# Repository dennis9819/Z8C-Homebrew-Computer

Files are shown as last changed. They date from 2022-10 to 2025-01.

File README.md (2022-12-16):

# Z8C-Homebrew-Computer

# Using the build tools
The Z8C uses the zmac macro assembler (http://48k.ca/zmac.html)

To easily develop for my Z80 homebrew system, I designed a simple
assempler development environment. This packs the following tasks into one script:
* zmac assembly
* object file creation (for xmodem upload)
* monitor file creation (creates monitor commands for ascii upload)
* symbol table include file generation
* eeprom programming for the minipro

## Prequisites
* zmac - self-compiled version included in ./Utility.
* minipro (https://gitlab.com/DavidGriffith/minipro)
* binutils (apt-get install binutils-multiarch, 
    pacman -S aarch64-linux-gnu-binutils )

## Building a project
`./build.sh <dir> <asm filename>`
* `dir`: Path to the location of the asm file
* `asm filename`: name of the assembly file without suffix

```
    # e.g.:
    cd ./Utility
    ./build.sh ../OperatingSystem/monitor_v2  
    ./build.sh ../OperatingSystem/software  
```
## Building a project with a properties file

`./build.sh <dir>`
* `dir`: Path to the location of the asm file

The directory must contain a file called `properties.env`
This file can contain project-specific options.

Example:
```
export OPT_GEN_SYMBOLTABLE=1
export OPT_GEN_MONFILE=0
export OPT_GEN_OBJFILE=1
export OPT_WRITEROM=1
export FILENAME=main
```

### Options
* `OPT_GEN_SYMBOLTABLE` if set to 1: Generates the symbols.s file
* `OPT_GEN_MONFILE` if set to 1: Generates the monitor file
* `OPT_GEN_OBJFILE` if set to 1: Generates the object file
* `OPT_WRITEROM` if set to 1: Starts eeprom programmer
* `FILENAME` same as the `<asm filename>` paramter of the build script
* `ROOT_DIR` overrides the project root path. required if git is not used
* `EEPROM_PART` sets EEPROM part for minipro. Default: `AT28C256`

# System design
The Z80 Hombrew computer is modular computer system, designed arround a custom backplane.

## Available modules
### Z8C CPU/COM Board
* Z80 ZPU @ 4MHz (6MHz planned)
* 64 KiB SRAM
* 32 KiB EEPROM (R/W switchable)
* Z80 CTC with external 1.8432MHz Clock switchable per channel
* Z80 SIO (Up to 115200 BAUD possible @ X16 SIO prescaler)
* 1 FTDI Connector
* 1 RS232 DSUB-9 Port
* 8 front-facing DIP switches (currently used for baud-rate setup)
* Power-On-Reset Circuit

```
Memory Layout
       Default ($00 = 0x00)  Mode 1 ($00 = 0x02)  Mode 2 ($00 = 0x01)             
$0000 +--------------------+--------------------+--------------------+
      | EEPROM Lower 16KiB | EEPROM Upper 16KiB | SRAM               |
$4000 +--------------------+--------------------+                    |
      | SRAM               | SRAM               |                    | 
      |                    |                    |                    |
      |                    |                    |                    |
$FFFF +--------------------+--------------------+--------------------+

Note: In default mode and mode 1, the MEMAQ pin (pin a5 on backplane) 
      can be used to inject an external memory device in the $0000-$3FFF 
      window.

IO Addresses:
$00 Memory register
$01 DIP Switches
$04 CTC (First address)
$08 SIO (First address)
```

### Z8C MIO Board
* Z80 PIO (Used for GPIO and non Z80 compliant interrupt handling)
* VT82C42 PS/2 controller
* AM5911A (only usable with CPU-Clock under 3 MHz)
* PFC8584 I2C Controller
* DS1307 RTC
* 8-Bit GPIO Port

//TODO: Add more Info

### Z8C Disk Interface Board
* Intel 82C55 based IDE Interface
* FDC9266 Floppy Disk Controller

//TODO: Add more Info

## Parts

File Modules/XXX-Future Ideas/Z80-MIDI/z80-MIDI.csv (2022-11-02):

Source: | C:\Users\dg\Documents\Z80\z80-MIDI\z80-MIDI.kicad_sch
Date: | 14/10/2022 00:28:46
Tool: | Eeschema (6.0.4)
Generator: | C:\Program Files\KiCad\6.0\bin\scripting\plugins/bom_csv_grouped_by_value.py
Component Count: | 26
Individual Components:
Item | Qty | Reference(s) | Value | LibPart | Footprint | Datasheet | Allied Price/Stock | Allied_Number | Description | Height | Manufacturer_Name | Manufacturer_Part_Number | Mouser Part Number | Mouser Price/Stock | RS Part Number | RS Price/Stock
 |  | IC1 | CTC-DIP-28 | Zilog_Z80_Peripherals:CTC-DIP-28 | Package_DIP:DIP-28_W15.24mm_LongPads |  |  |  | Z8430 Zilog CTC | 5.21 | Zilog | Z84C3010PEG | 692-Z84C3010PEG | https://www.mouser.com/Search/Refine.aspx?Keyword=692-Z84C3010PEG
 |  | IC2 | SIO1-DIP-40 | Zilog_Z80_Peripherals:SIO1-DIP-40 | Package_DIP:DIP-40_W15.24mm_LongPads |  | https://www.alliedelec.com/zilog-z84c4206peg/R1000052/ | R1000052 | Z80 CMOS SIO/1 Z84C41 Zilog | 4.06 | Zilog | Z84C4206PEG | 692-Z84C4206PEG | https://www.mouser.com/Search/Refine.aspx?Keyword=692-Z84C4206PEG | 6600766 | https://uk.rs-online.com/web/p/products/6600766
 |  | J1 | Conn_02x32_Row_Letter_First | Connector_Generic:Conn_02x32_Row_Letter_First | Connector_DIN:DIN41612_Q_2x32_Male_Horizontal_THT | ~
 |  | J2 | Conn_02x05_Odd_Even | Connector_Generic:Conn_02x05_Odd_Even | Connector_PinHeader_2.54mm:PinHeader_2x05_P2.54mm_Vertical | ~
 |  | J3 | DIN-5 | Connector:DIN-5 | w_conn_av:din-5 | http://www.mouser.com/ds/2/18/40_c091_abd_e-75918.pdf
 |  | J4 | DIN-5 | Connector:DIN-5 | w_conn_av:din-5 | http://www.mouser.com/ds/2/18/40_c091_abd_e-75918.pdf
 |  | J5 | DIN-5 | Connector:DIN-5 | w_conn_av:din-5 | http://www.mouser.com/ds/2/18/40_c091_abd_e-75918.pdf
 |  | LED1 | MENOTR_A500_Dual_3mm | CustomSymbols:MENOTR_A500_Dual_3mm | w_conn_av:MENTOR A500 Dual 3mm
 |  | R1 | 10k | Device:R | Resistor_THT:R_Axial_DIN0204_L3.6mm_D1.6mm_P7.62mm_Horizontal | ~
 |  | R2 | 10k | Device:R | Resistor_THT:R_Axial_DIN0204_L3.6mm_D1.6mm_P7.62mm_Horizontal | ~
 |  | R3 | 10k | Device:R | Resistor_THT:R_Axial_DIN0204_L3.6mm_D1.6mm_P7.62mm_Horizontal | ~
 |  | R4 | 10k | Device:R | Resistor_THT:R_Axial_DIN0204_L3.6mm_D1.6mm_P7.62mm_Horizontal | ~
 |  | R5 | 10k | Device:R | Resistor_THT:R_Axial_DIN0204_L3.6mm_D1.6mm_P7.62mm_Horizontal | ~
 |  | R6 | 10k | Device:R | Resistor_THT:R_Axial_DIN0204_L3.6mm_D1.6mm_P7.62mm_Horizontal | ~
 |  | R7 | 10k | Device:R | Resistor_THT:R_Axial_DIN0204_L3.6mm_D1.6mm_P7.62mm_Horizontal | ~
 |  | RN1 | R_Network08 | Device:R_Network08 | Resistor_THT:R_Array_SIP9 | http://www.vishay.com/docs/31509/csc.pdf
 |  | U1 | 74LS688 | 74xx:74LS688 | Package_DIP:DIP-20_W7.62mm_LongPads | http://www.ti.com/lit/gpn/sn74LS688
 |  | U2 | 74HC245 | 74xx:74HC245 | Package_DIP:DIP-20_W7.62mm_LongPads | http://www.ti.com/lit/gpn/sn74HC245
 |  | U3 | 74HC245 | 74xx:74HC245 | Package_DIP:DIP-20_W7.62mm_LongPads | http://www.ti.com/lit/gpn/sn74HC245
 |  | U4 | 74HC245 | 74xx:74HC245 | Package_DIP:DIP-20_W7.62mm_LongPads | http://www.ti.com/lit/gpn/sn74HC245
 |  | U5 | 74LS06 | 74xx:74LS06 | Package_DIP:DIP-14_W7.62mm_Socket_LongPads | http://www.ti.com/lit/gpn/sn74LS06
 |  | U6 | 74LS02 | 74xx:74LS02 |  | http://www.ti.com/lit/gpn/sn74ls02
 |  | U7 | 74LS06 | 74xx:74LS06 | Package_DIP:DIP-14_W7.62mm_Socket_LongPads | http://www.ti.com/lit/gpn/sn74LS06
 |  | U8 | 74LS06 | 74xx:74LS06 | Package_DIP:DIP-14_W7.62mm_Socket_LongPads | http://www.ti.com/lit/gpn/sn74LS06
 |  | U9 | 6N137 | Isolator:6N137 | Package_DIP:DIP-8_W7.62mm | https://docs.broadcom.com/docs/AV02-0940EN
 |  | X1 | ACO-xxxMHz | Oscillator:ACO-xxxMHz | Oscillator:Oscillator_DIP-14 | http://www.conwin.com/datasheets/cx/cx030.pdf
Collated Components:
Item | Qty | Reference(s) | Value | LibPart | Footprint | Datasheet | Allied Price/Stock | Allied_Number | Description | Height | Manufacturer_Name | Manufacturer_Part_Number | Mouser Part Number | Mouser Price/Stock | RS Part Number | RS Price/Stock
1 | 1 | IC1 | CTC-DIP-28 | Zilog_Z80_Peripherals:CTC-DIP-28 | Package_DIP:DIP-28_W15.24mm_LongPads |  |  |  | Z8430 Zilog CTC | 5.21 | Zilog | Z84C3010PEG | 692-Z84C3010PEG | https://www.mouser.com/Search/Refine.aspx?Keyword=692-Z84C3010PEG
2 | 1 | IC2 | SIO1-DIP-40 | Zilog_Z80_Peripherals:SIO1-DIP-40 | Package_DIP:DIP-40_W15.24mm_LongPads |  | https://www.alliedelec.com/zilog-z84c4206peg/R1000052/ | R1000052 | Z80 CMOS SIO/1 Z84C41 Zilog | 4.06 | Zilog | Z84C4206PEG | 692-Z84C4206PEG | https://www.mouser.com/Search/Refine.aspx?Keyword=692-Z84C4206PEG | 6600766 | https://uk.rs-online.com/web/p/products/6600766
3 | 1 | J1 | Conn_02x32_Row_Letter_First | Connector_Generic:Conn_02x32_Row_Letter_First | Connector_DIN:DIN41612_Q_2x32_Male_Horizontal_THT | ~
4 | 1 | J2 | Conn_02x05_Odd_Even | Connector_Generic:Conn_02x05_Odd_Even | Connector_PinHeader_2.54mm:PinHeader_2x05_P2.54mm_Vertical | ~
5 | 3 | J3, J4, J5 | DIN-5 | Connector:DIN-5 | w_conn_av:din-5 | http://www.mouser.com/ds/2/18/40_c091_abd_e-75918.pdf
6 | 1 | LED1 | MENOTR_A500_Dual_3mm | CustomSymbols:MENOTR_A500_Dual_3mm | w_conn_av:MENTOR A500 Dual 3mm
7 | 7 | R1, R2, R3, R4, R5, R6, R7 | 10k | Device:R | Resistor_THT:R_Axial_DIN0204_L3.6mm_D1.6mm_P7.62mm_Horizontal | ~
8 | 1 | RN1 | R_Network08 | Device:R_Network08 | Resistor_THT:R_Array_SIP9 | http://www.vishay.com/docs/31509/csc.pdf
9 | 1 | U1 | 74LS688 | 74xx:74LS688 | Package_DIP:DIP-20_W7.62mm_LongPads | http://www.ti.com/lit/gpn/sn74LS688
10 | 3 | U2, U3, U4 | 74HC245 | 74xx:74HC245 | Package_DIP:DIP-20_W7.62mm_LongPads | http://www.ti.com/lit/gpn/sn74HC245
11 | 3 | U5, U7, U8 | 74LS06 | 74xx:74LS06 | Package_DIP:DIP-14_W7.62mm_Socket_LongPads | http://www.ti.com/lit/gpn/sn74LS06
12 | 1 | U6 | 74LS02 | 74xx:74LS02 |  | http://www.ti.com/lit/gpn/sn74ls02
13 | 1 | U9 | 6N137 | Isolator:6N137 | Package_DIP:DIP-8_W7.62mm | https://docs.broadcom.com/docs/AV02-0940EN
14 | 1 | X1 | ACO-xxxMHz | Oscillator:ACO-xxxMHz | Oscillator:Oscillator_DIP-14 | http://www.conwin.com/datasheets/cx/cx030.pdf

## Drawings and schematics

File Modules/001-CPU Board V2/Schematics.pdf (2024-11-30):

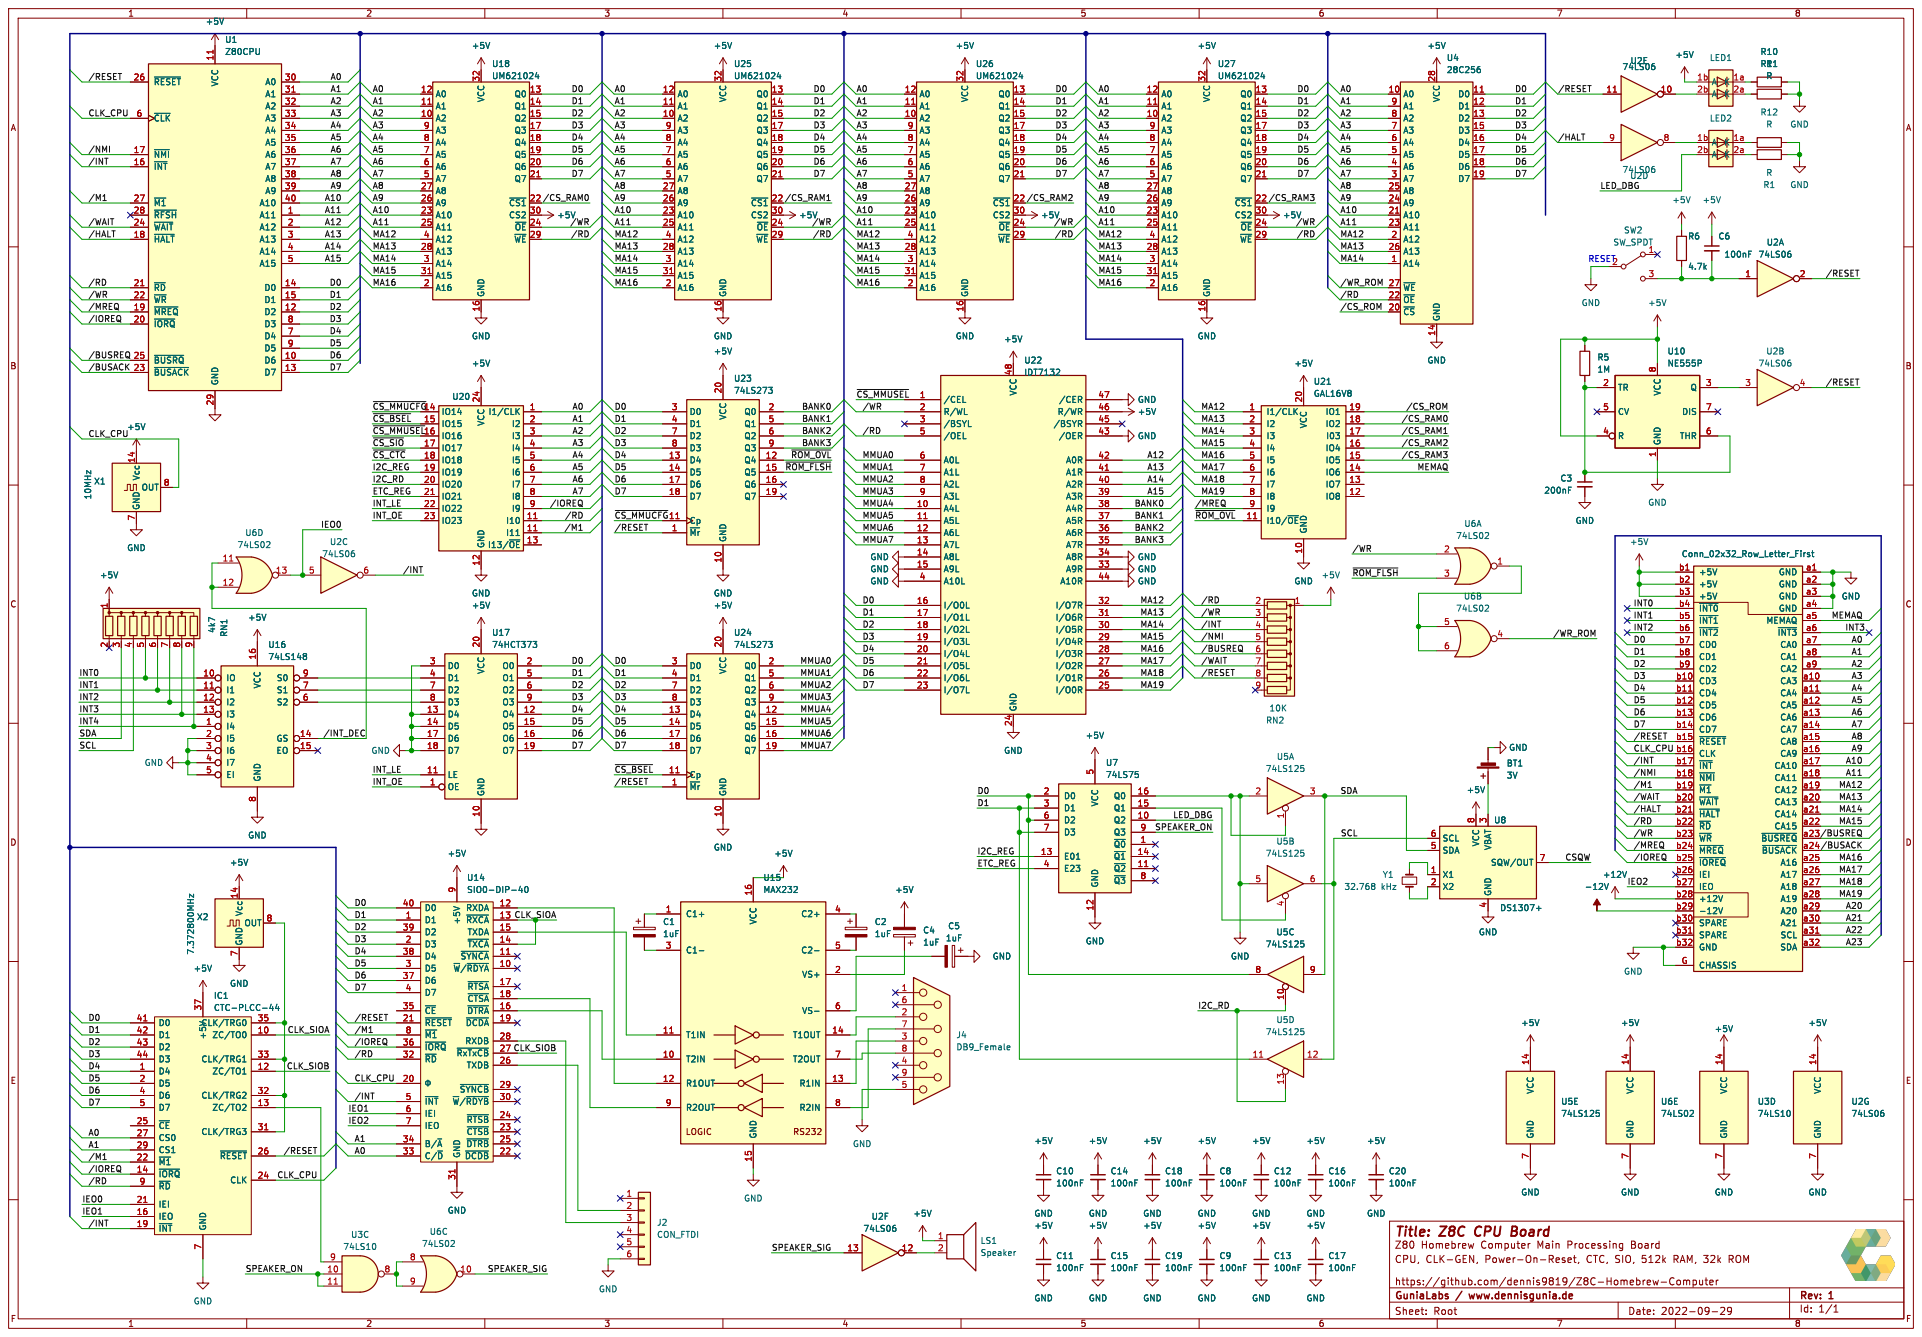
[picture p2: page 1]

GND
+5V GND GND GND GND

4 SDA 5 SCL 6 SQW/OUT 7 VCC

Id: 1/1 Title: Z8C CPU Board

https://github.com/dennis9819/Z8C-Homebrew-Computer

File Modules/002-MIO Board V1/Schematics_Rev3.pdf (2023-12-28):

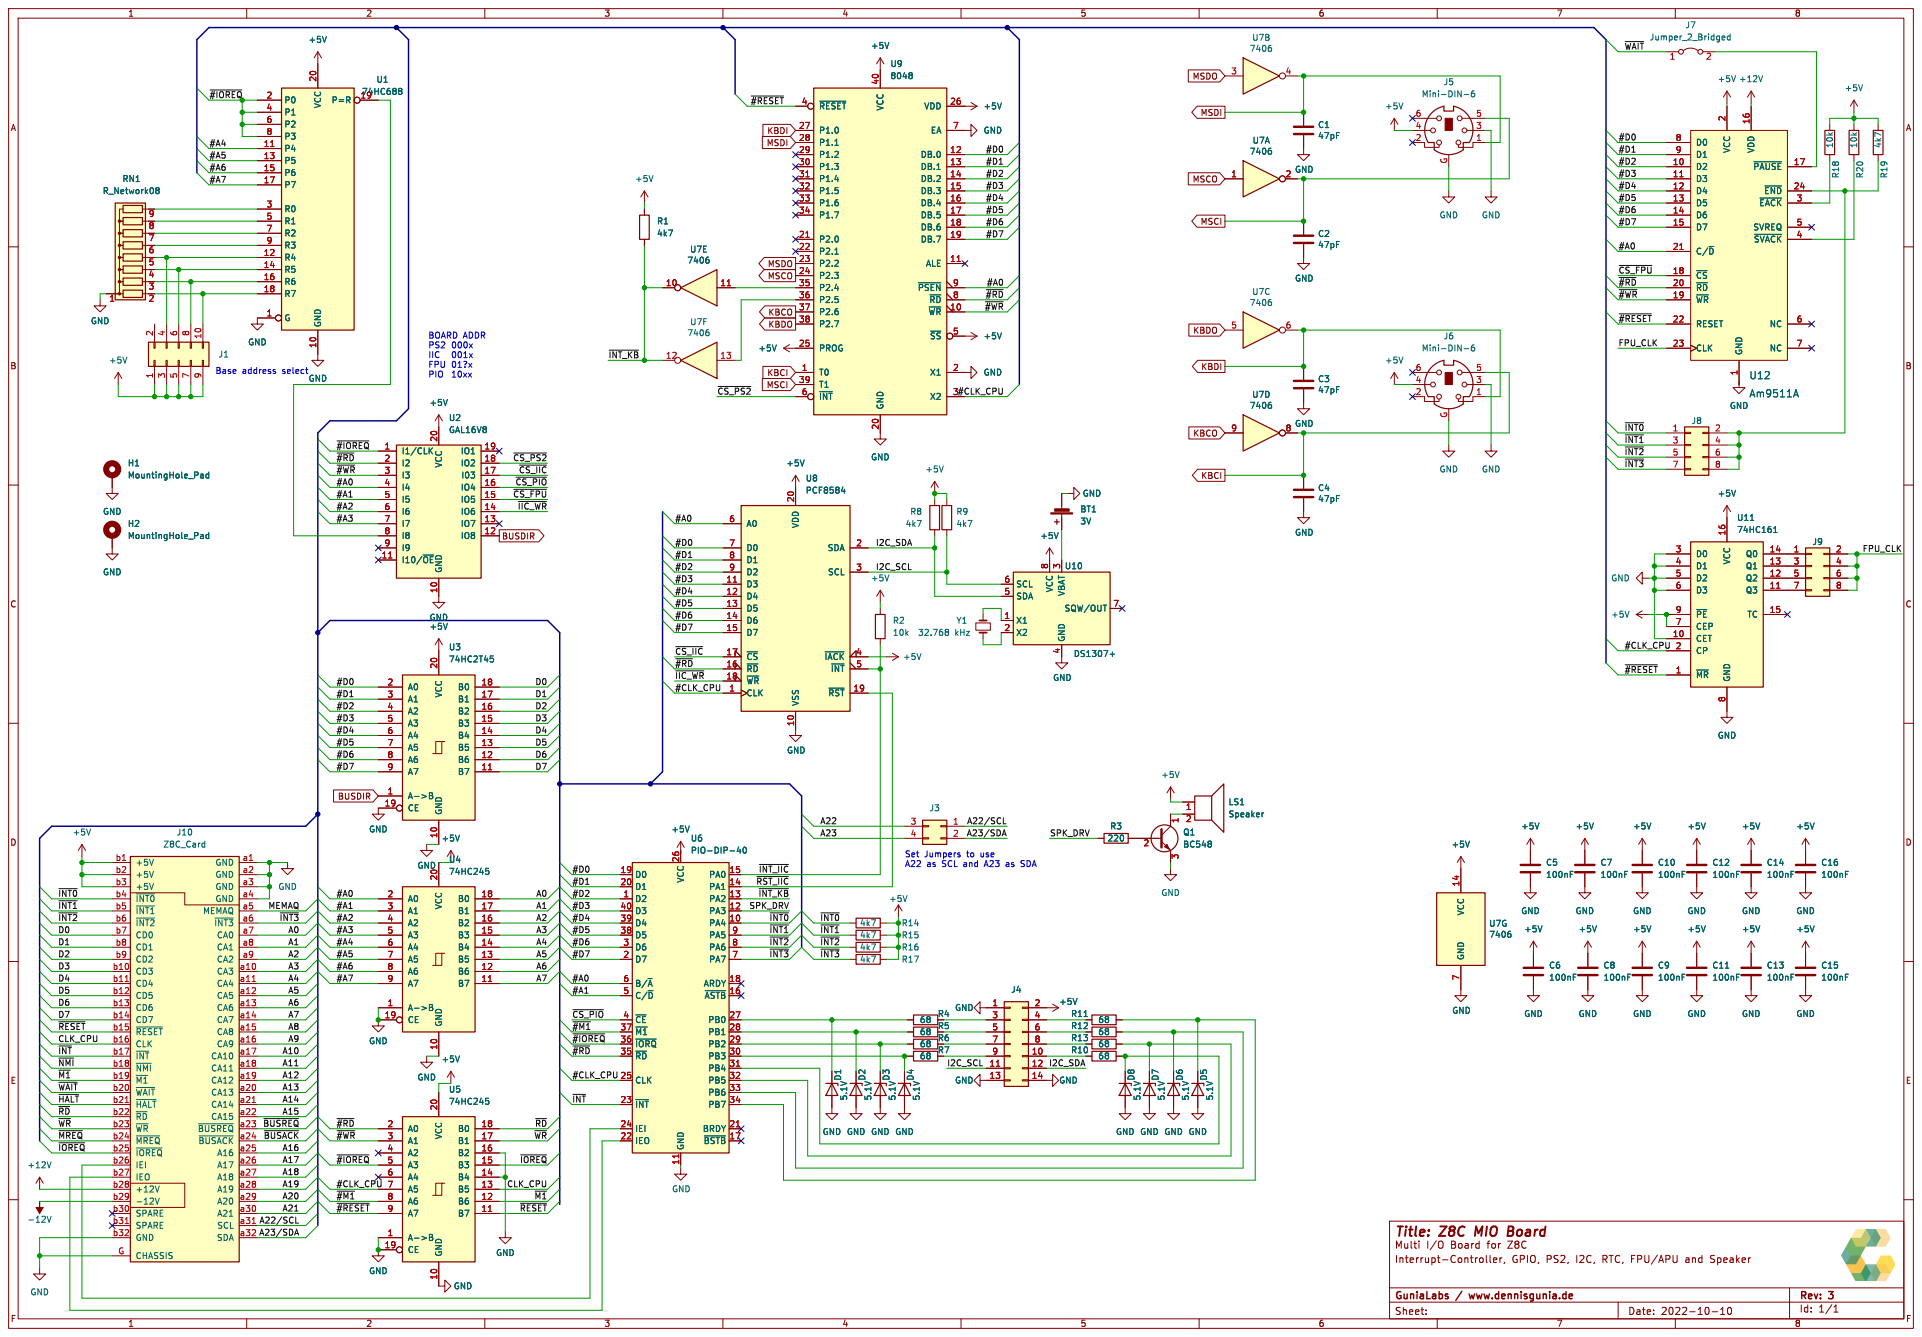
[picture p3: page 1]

4 SDA 5 SCL 6 SQW/OUT 7 VCC

Id: 1/1 Title: Z8C MIO Board

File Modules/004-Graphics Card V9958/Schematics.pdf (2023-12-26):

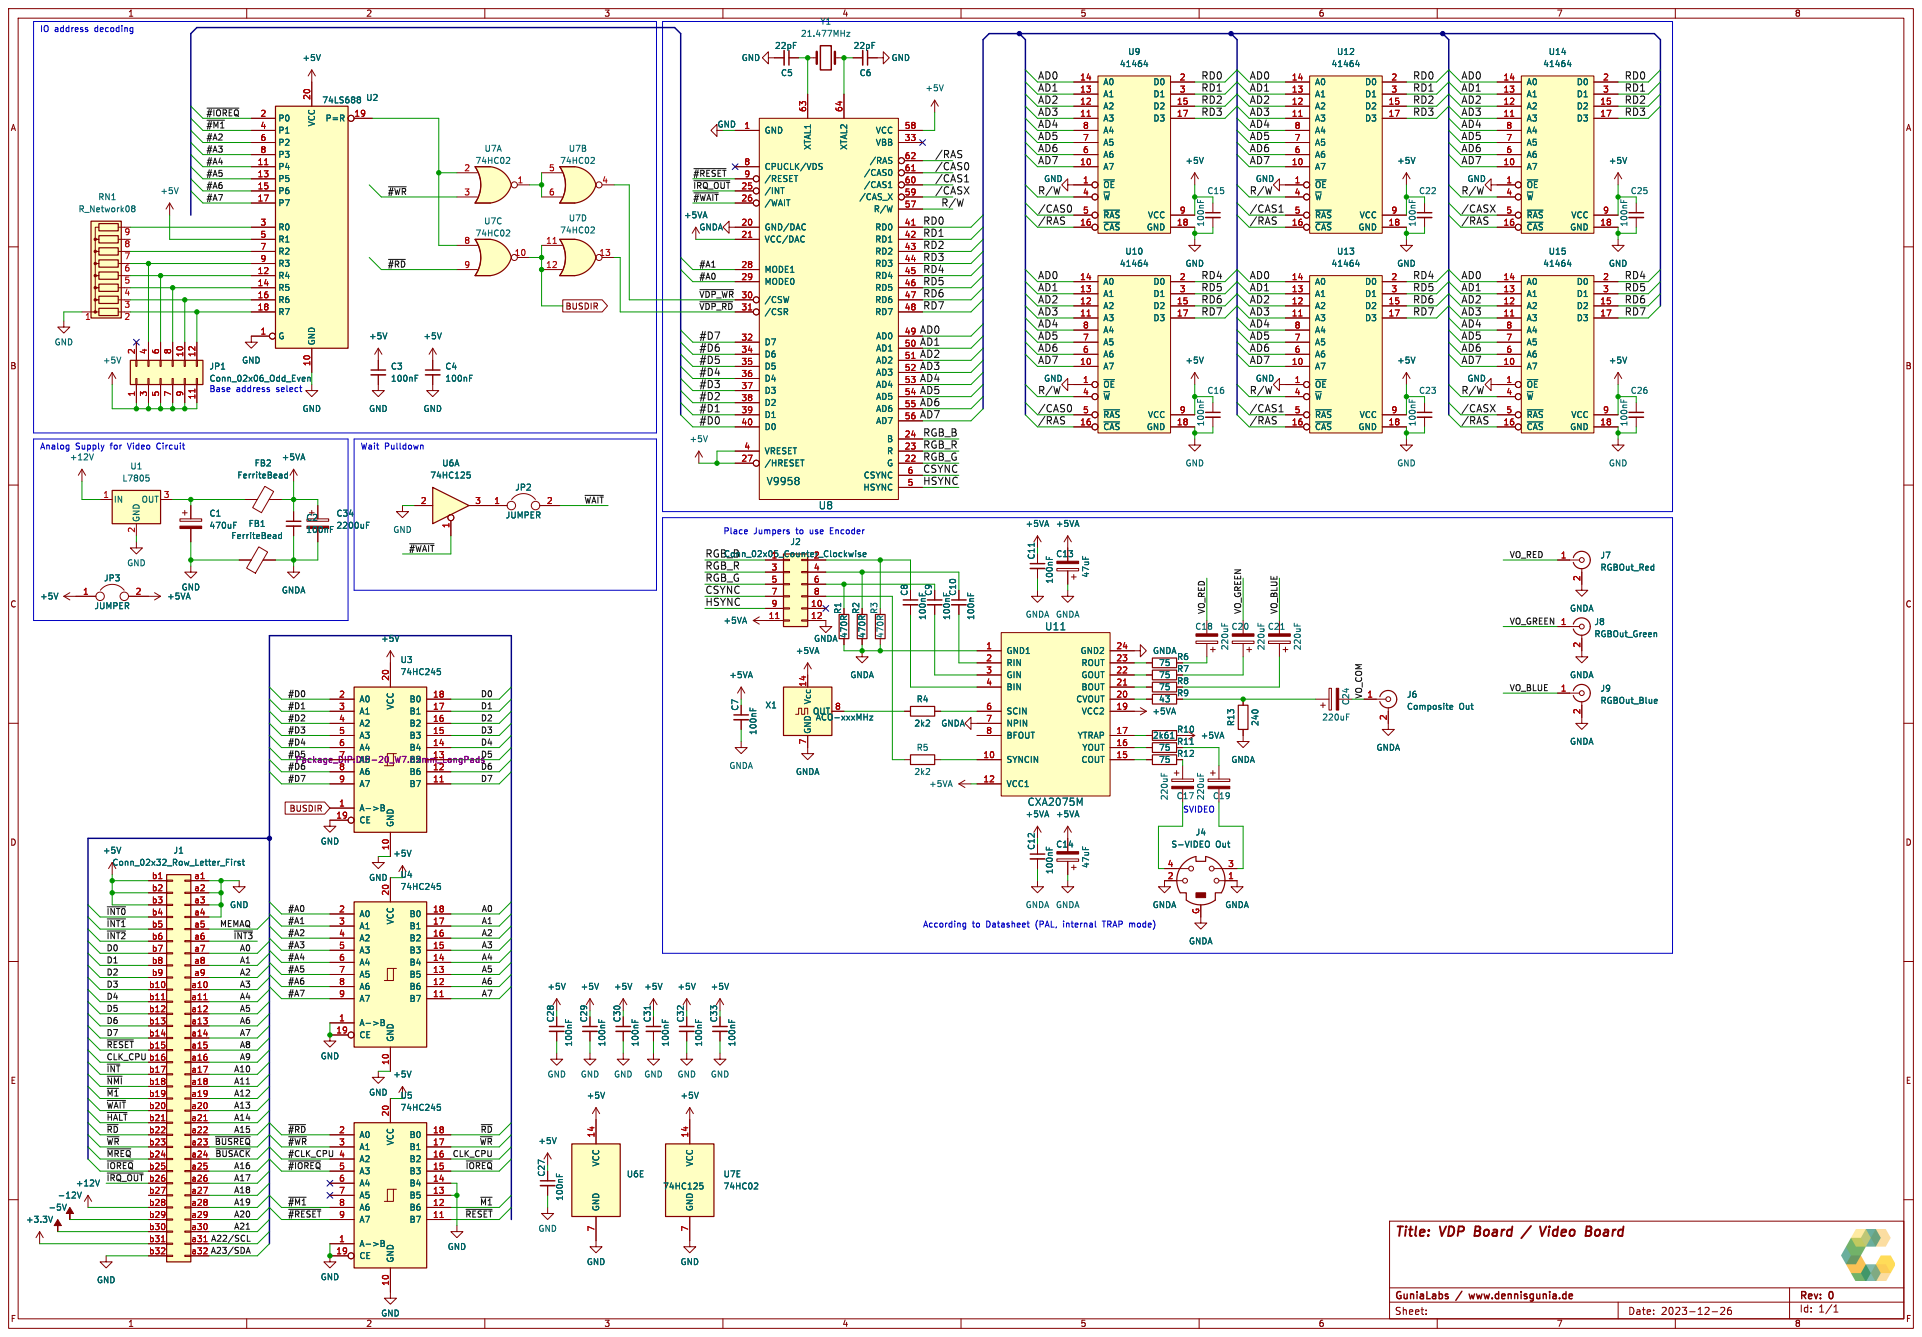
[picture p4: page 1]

Sheet: GuniaLabs / www.dennisgunia.de GND
+5VVCC 14 GND

Id: 1/1 Title: VDP Board / Video Board

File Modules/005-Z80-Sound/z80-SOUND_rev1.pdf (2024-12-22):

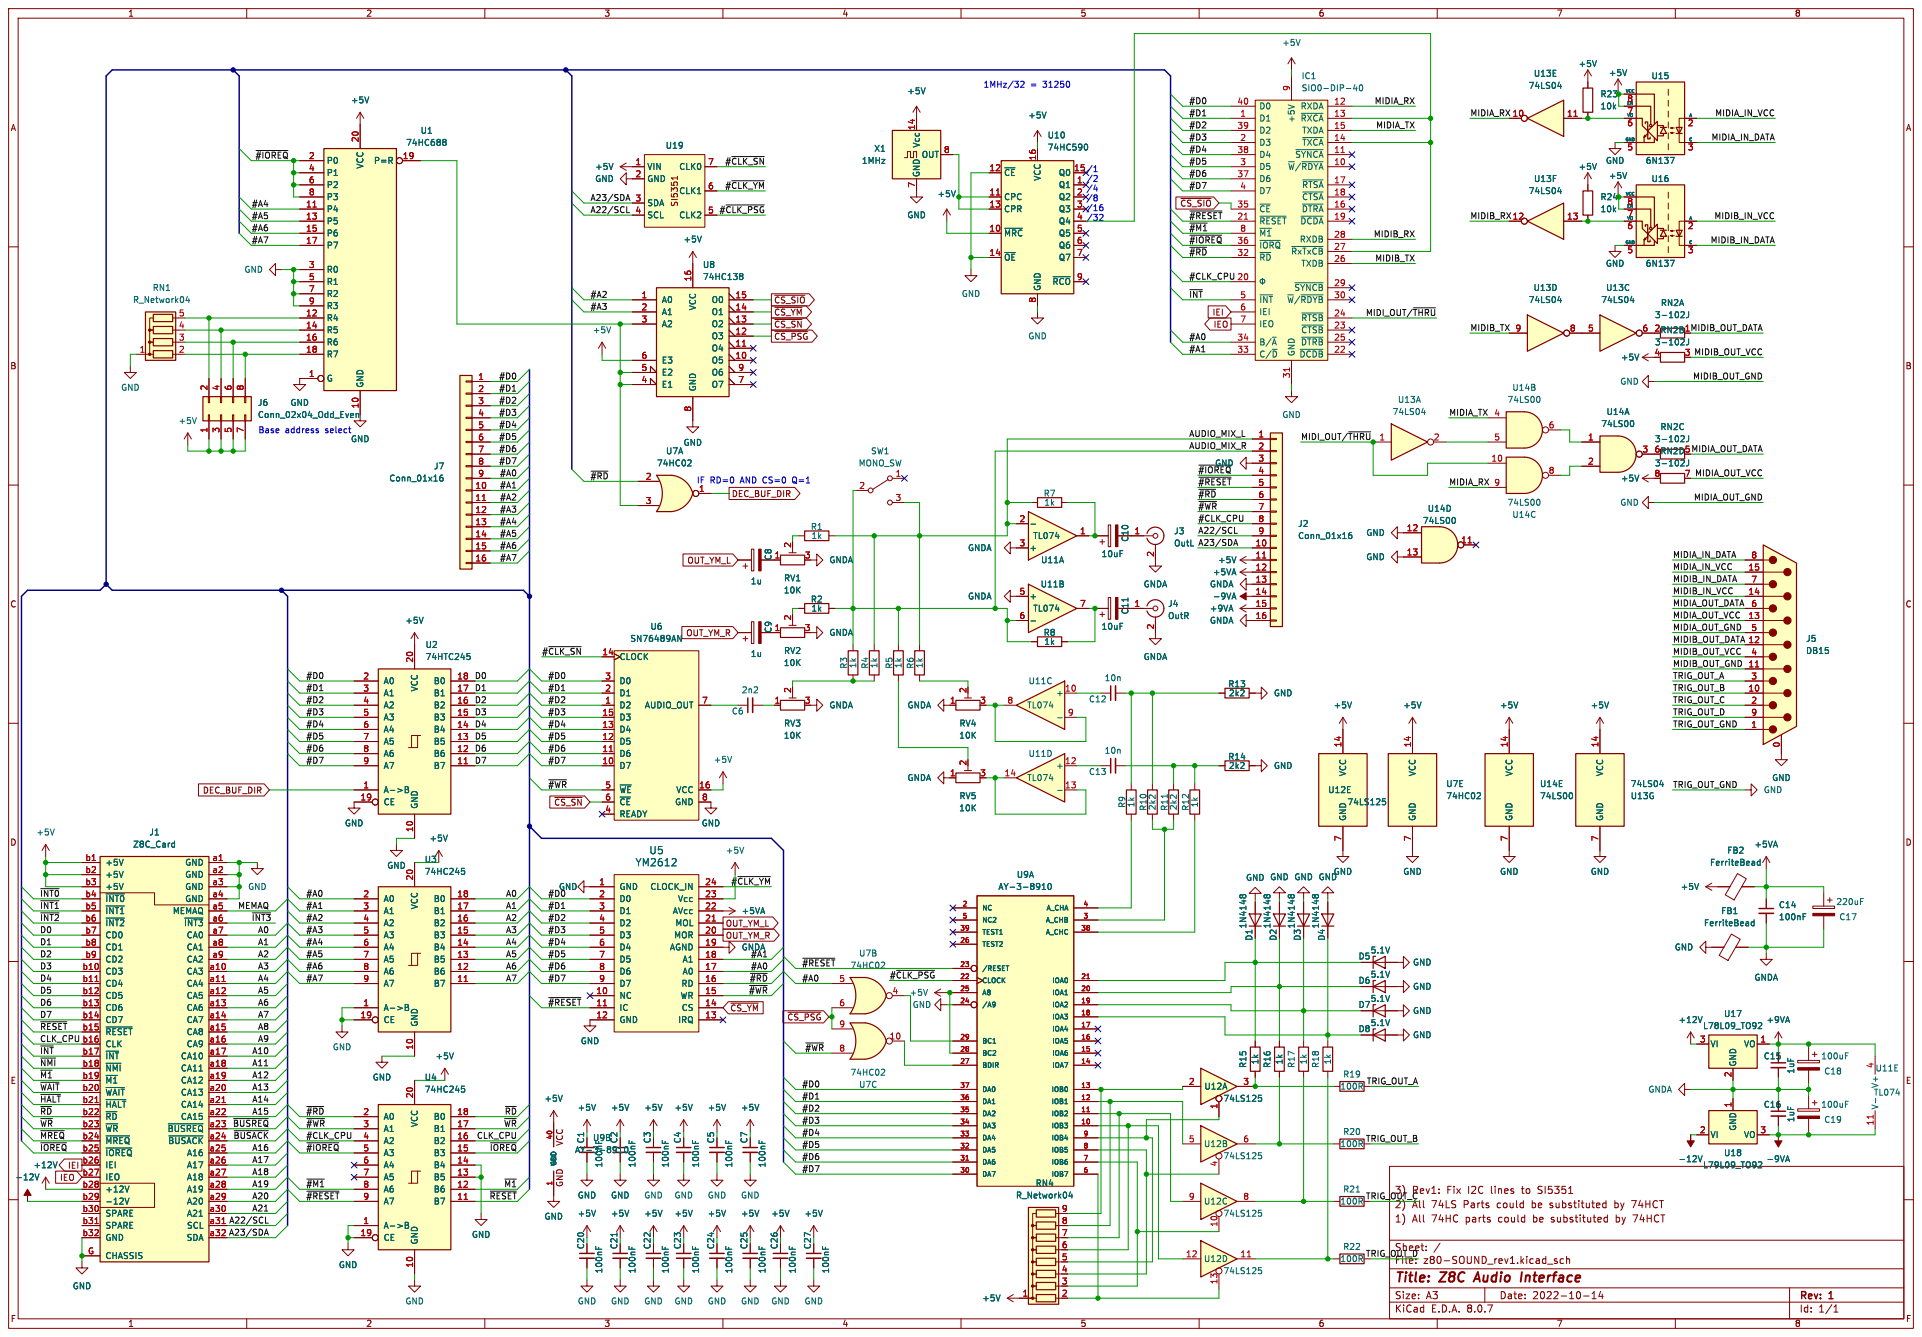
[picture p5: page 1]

7 OUT 8 +5V U19 VIN 1 GND 2 SDA 3 SCL 4 CLK2 5 CLK1 6 CLK0 7 +5V GND

IF RD=0 AND CS=0 Q=1

GND a1 CA3 a10 CA4 a11 CA5 a12 CA6 a13 CA7 a14 CA8 a15 CA9 a16 CA10 a17 CA11 a18 CA12 a19 GND a2 CA13 a20 CA14 a21 CA15 a22 ~{BUSREQ}a23 ~{BUSACK}a24 A16 a25 A17 a26 A18 a27 A19 a28 A20 a29 GND a3 A21 a30 SCL a31 SDA a32 GND a4 MEMAQ a5 ~{INT3}a6 CA0 a7 CA1 a8 CA2 a9 +5V b1 CD3 b10 CD4 b11 CD5 b12 CD6 b13 CD7 b14 ~{RESET} b15 CLK b16 ~{INT} b17 ~{NMI} b18 ~{M1} b19 +5V b2 ~{WAIT} b20 ~{HALT} b21 ~{RD} b22 ~{WR} b23 ~{MREQ} b24 ~{IOREQ} b25
-12V b29 +5V b3 SPARE b30 SPARE b31 GND b32 ~{INT0} b4 ~{INT1} b5 ~{INT2} b6 CD0 b7 CD1 b8 CD2 b9

+5VA DEC_BUF_DIR
-12V b29 +5V b3 SPARE b30 SPARE b31 GND b32 ~{INT0} b4 ~{INT1} b5 ~{INT2} b6 CD0 b7 CD1 b8 CD2 b9 GND

1 VCC 40 C1 100nF GND GND U5 YM2612 GND 1 NC 10

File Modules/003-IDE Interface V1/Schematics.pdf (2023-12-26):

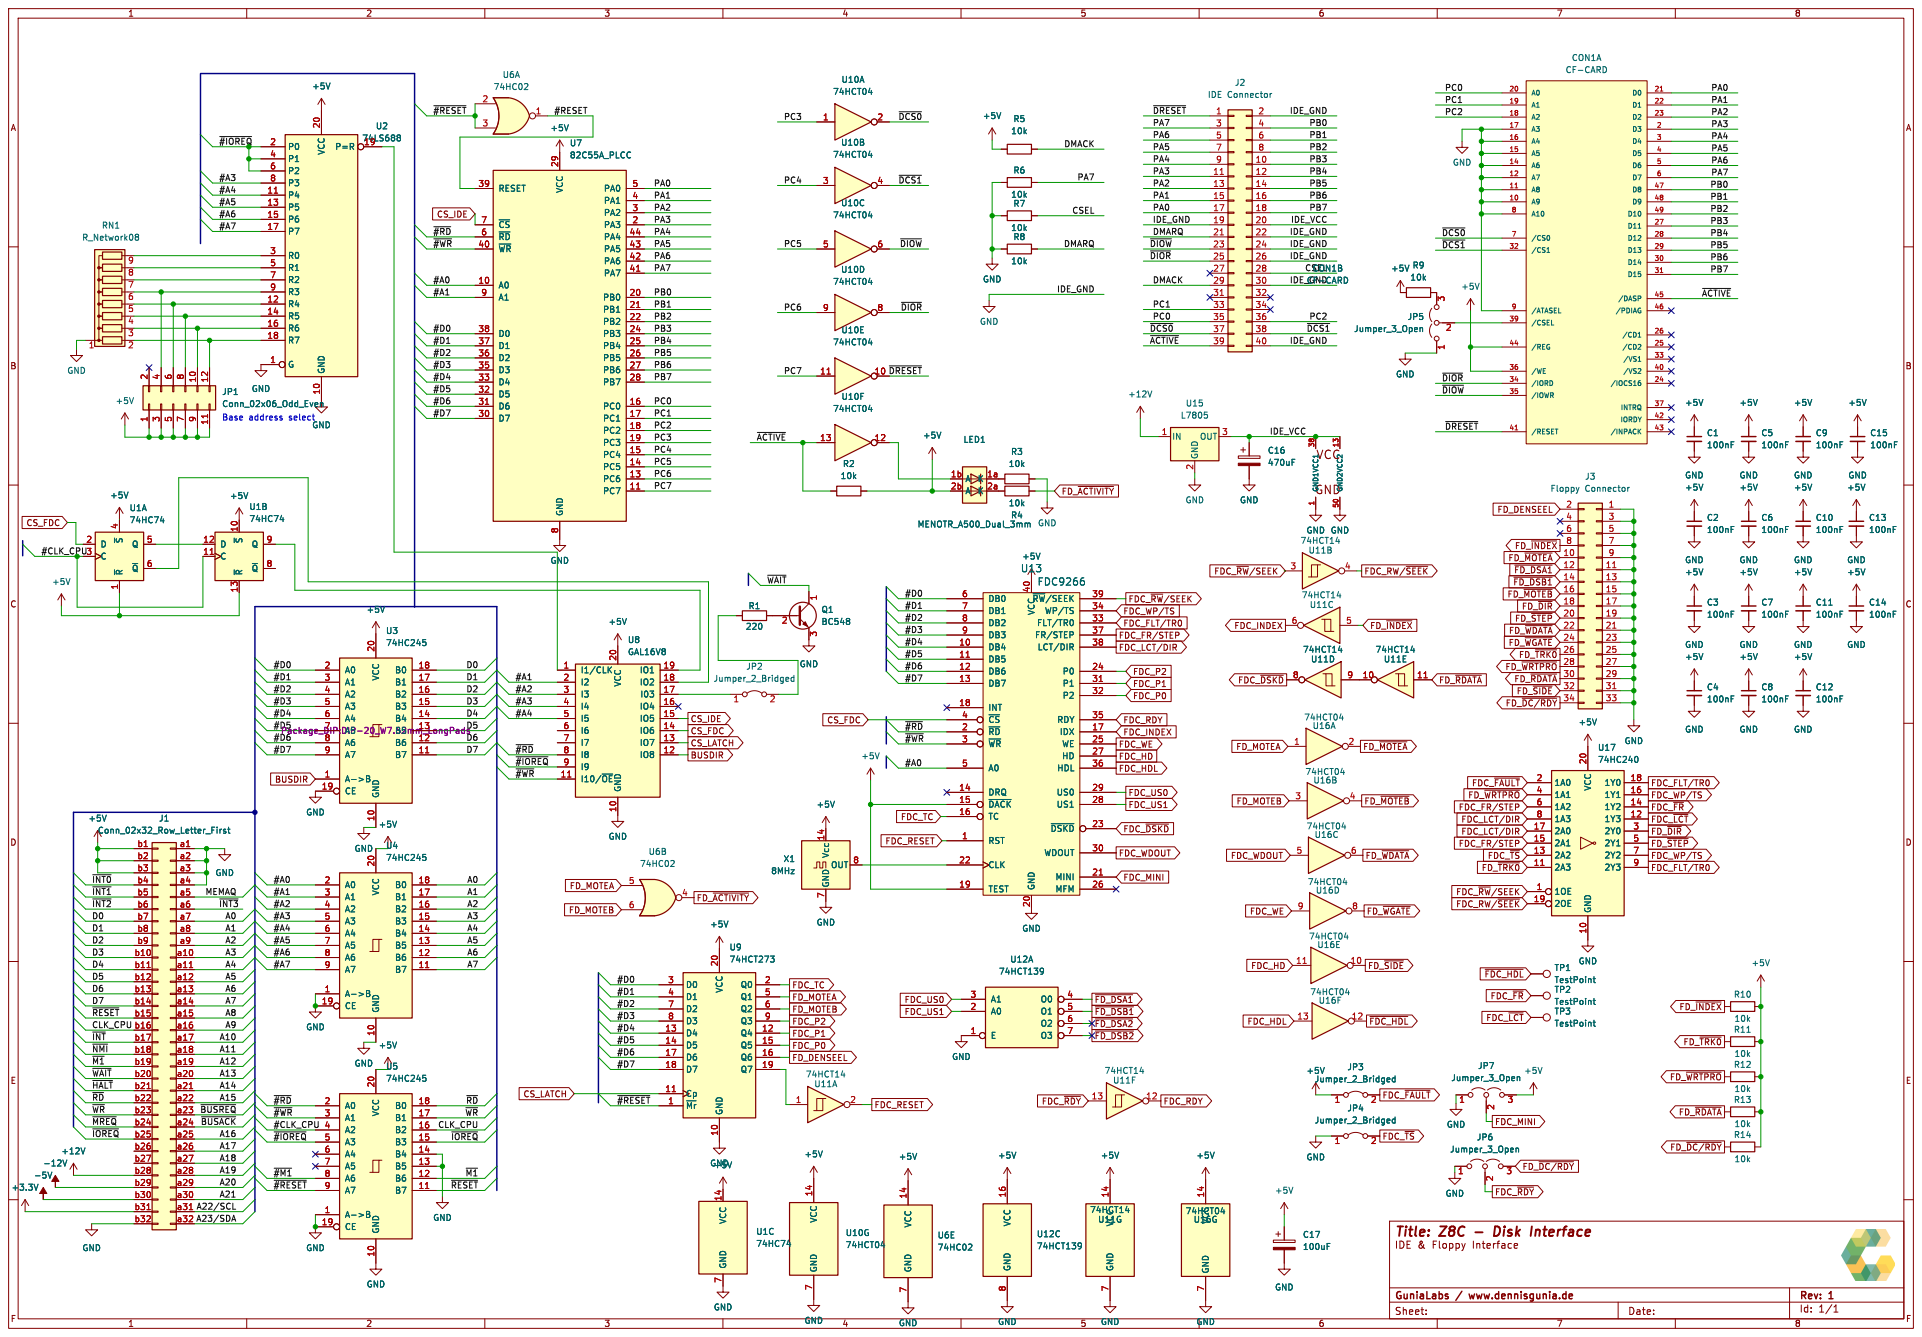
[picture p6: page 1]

Id: 1/1 Title: Z8C - Disk Interface

Sheet: GuniaLabs / www.dennisgunia.de

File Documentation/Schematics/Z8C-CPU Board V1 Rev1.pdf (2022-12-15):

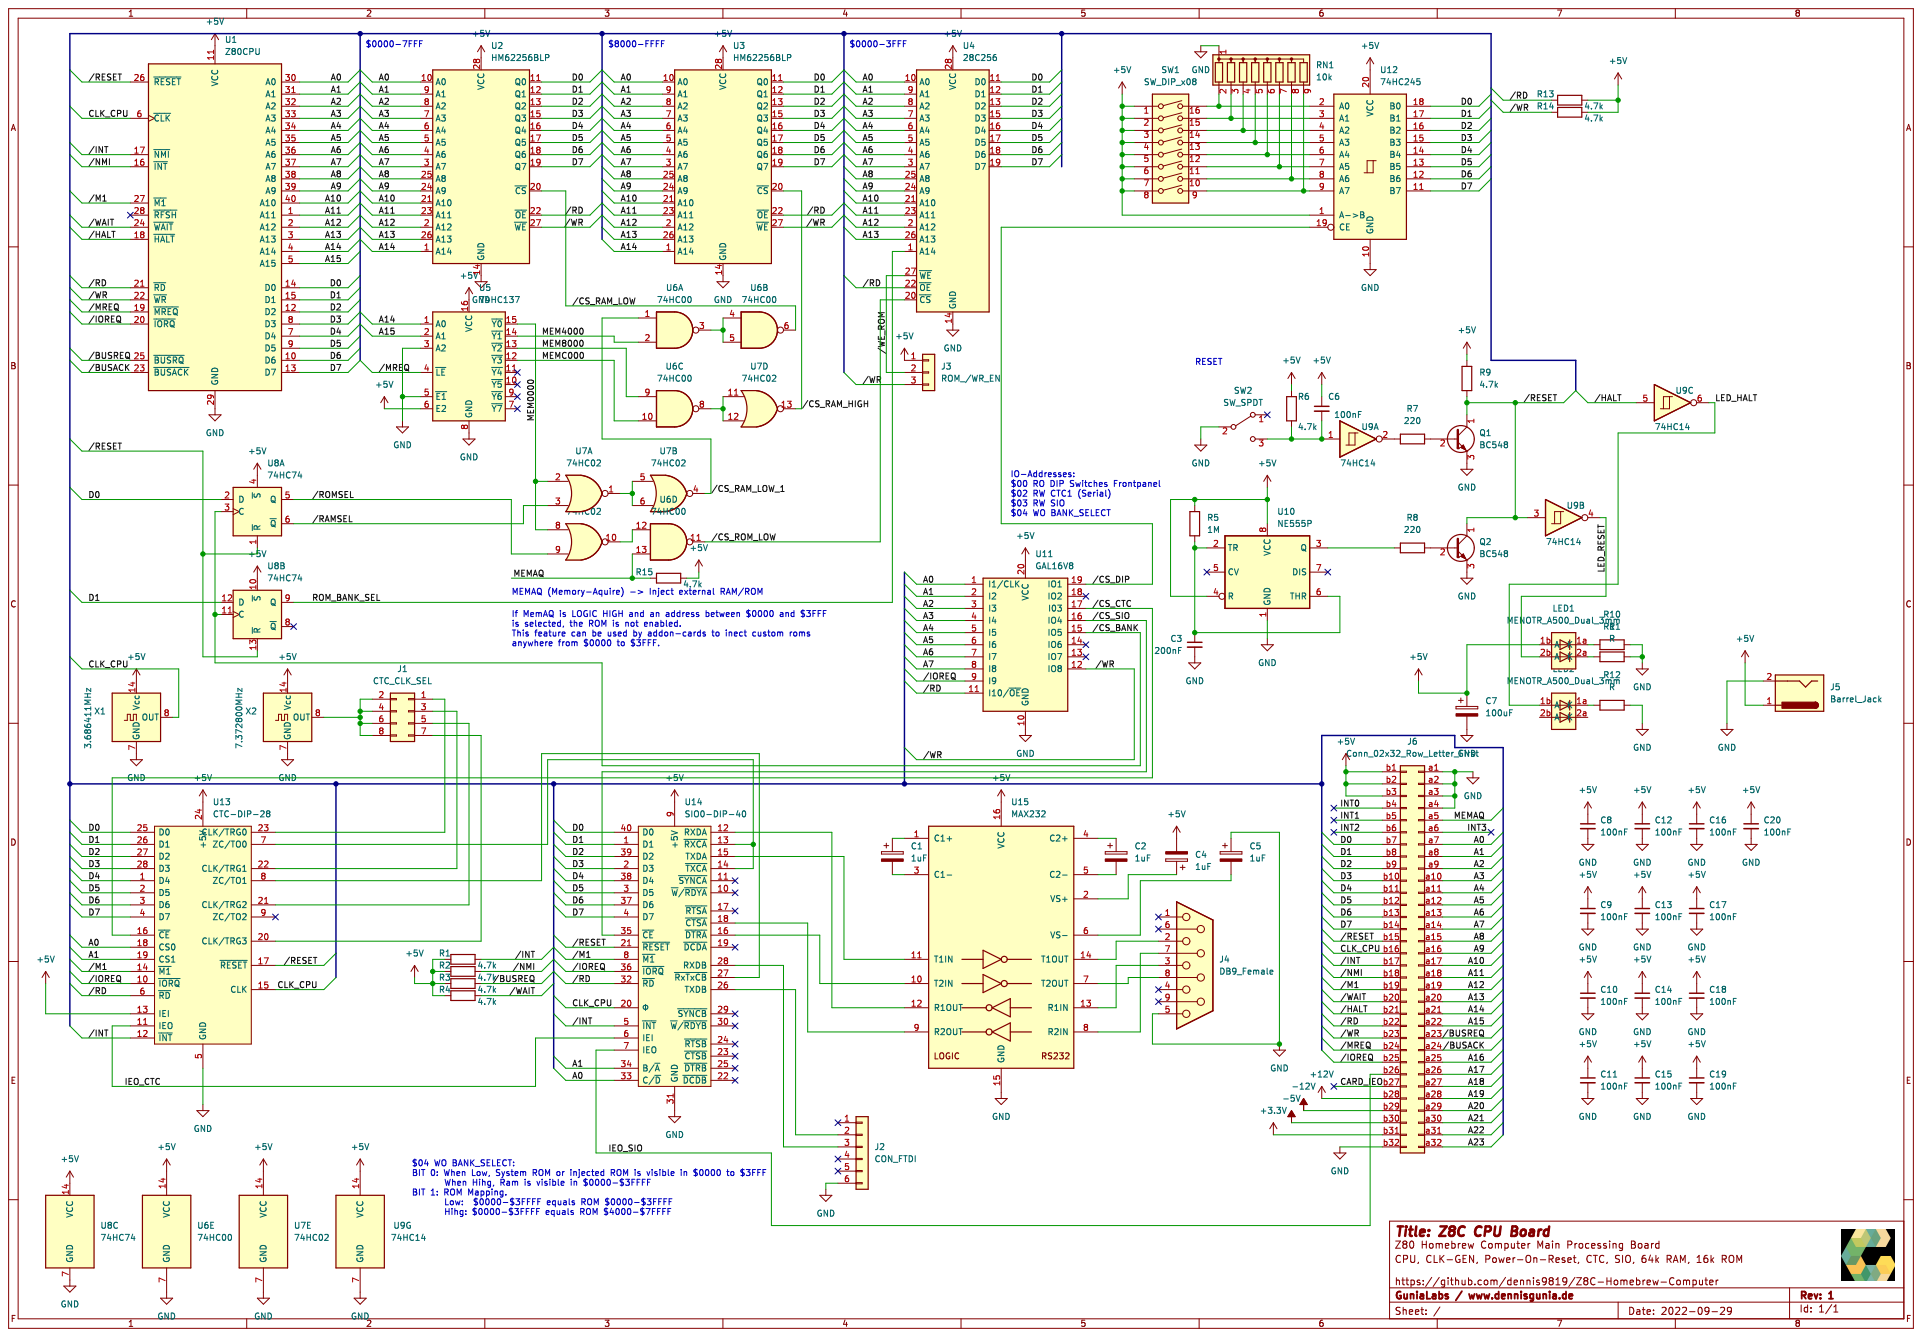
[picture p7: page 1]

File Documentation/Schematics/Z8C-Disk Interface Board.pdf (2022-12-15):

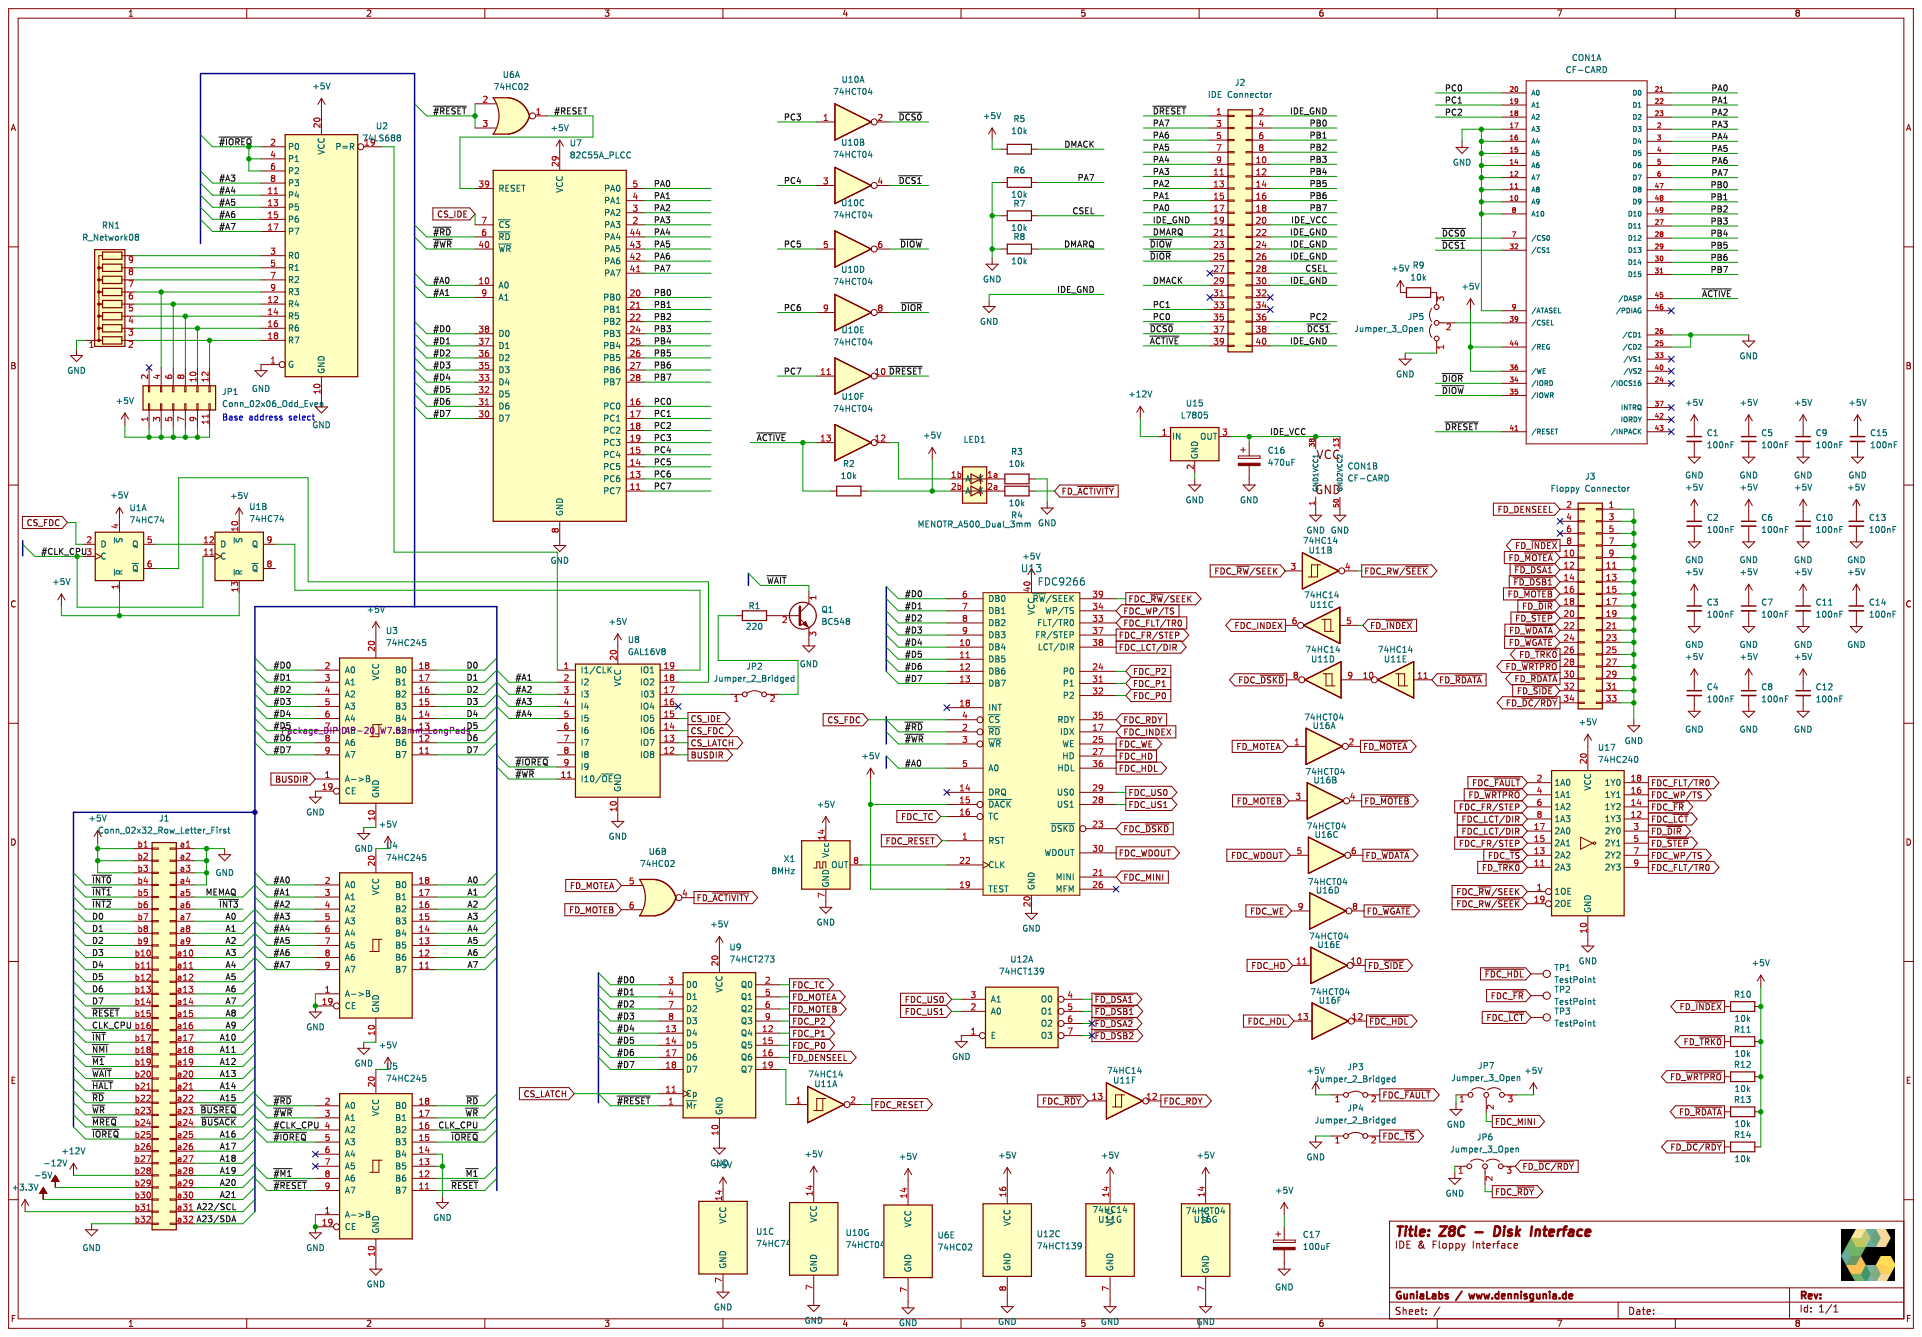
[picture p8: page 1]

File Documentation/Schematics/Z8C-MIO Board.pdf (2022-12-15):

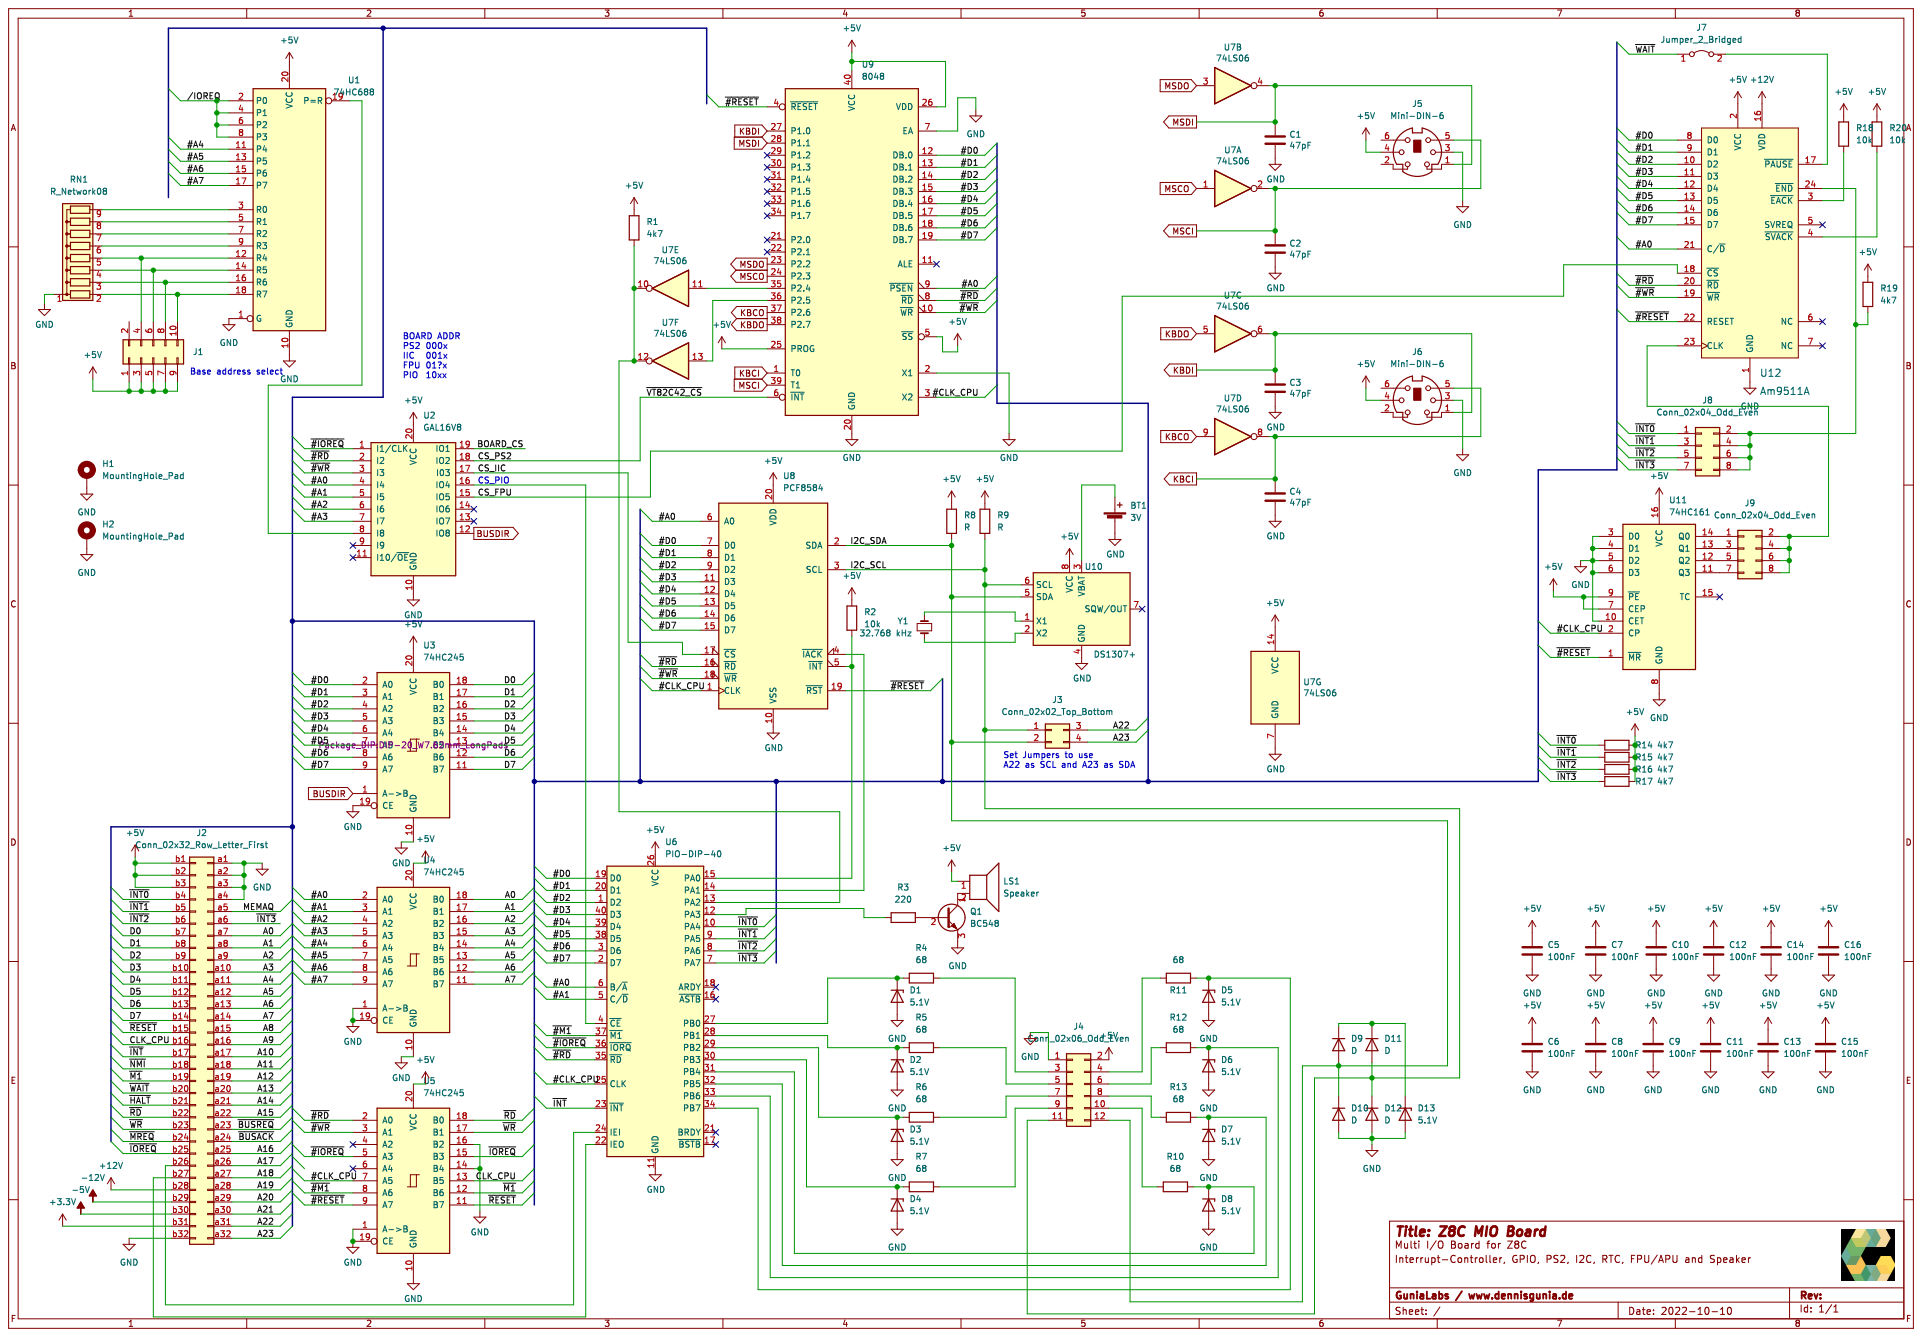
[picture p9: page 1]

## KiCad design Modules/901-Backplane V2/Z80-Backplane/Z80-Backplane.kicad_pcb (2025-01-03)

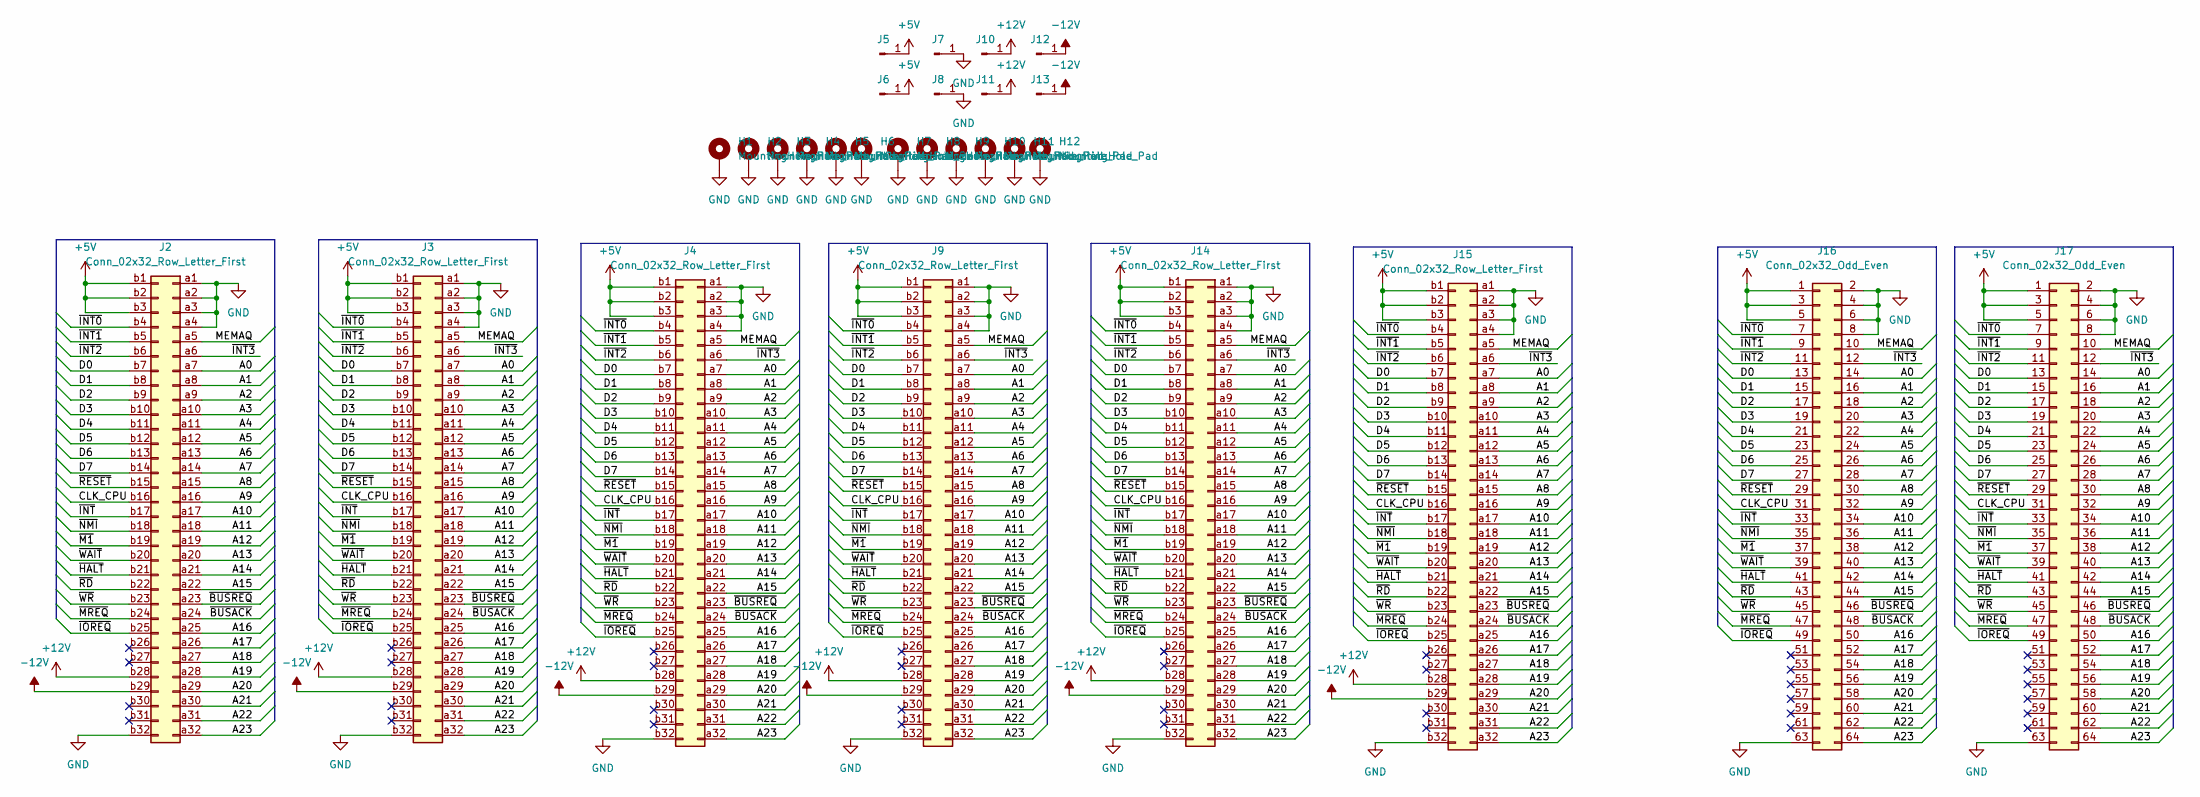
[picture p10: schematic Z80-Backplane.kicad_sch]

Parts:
H1, H2, H3, H4, H5, H6, H7, H8, H9, H10, H11, H12: MountingHole_Pad; MountingHole_2.7mm_M2.5_DIN965_Pad
J2, J3, J4, J9, J14, J15: Conn_02x32_Row_Letter_First; DIN41612_B_2x32_Female_Vertical_THT
J5, J6, J7, J8, J10, J11, J12, J13: Conn_01x01_Male; FS-P475
J16, J17: Conn_02x32_Odd_Even; IDC-Header_2x32_P2.54mm_Vertical

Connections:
+5V: J2.b1, J2.b2, J2.b3, J3.b1, J3.b2, J3.b3, J4.b1, J4.b2, J4.b3, J5.1, J6.1, J9.b1, J9.b2, J9.b3, J14.b1, J14.b2, J14.b3, J15.b1, J15.b2, J15.b3, J16.1, J16.3, J16.5, J17.1, J17.3, J17.5
+12V: J2.b28, J3.b28, J4.b28, J9.b28, J10.1, J11.1, J14.b28, J15.b28
-12V: J2.b29, J3.b29, J4.b29, J9.b29, J12.1, J13.1, J14.b29, J15.b29
/A0: J2.a7, J3.a7, J4.a7, J9.a7, J14.a7, J15.a7, J16.14, J17.14
/A1: J2.a8, J3.a8, J4.a8, J9.a8, J14.a8, J15.a8, J16.16, J17.16
/A2: J2.a9, J3.a9, J4.a9, J9.a9, J14.a9, J15.a9, J16.18, J17.18
/A3: J2.a10, J3.a10, J4.a10, J9.a10, J14.a10, J15.a10, J16.20, J17.20
/A4: J2.a11, J3.a11, J4.a11, J9.a11, J14.a11, J15.a11, J16.22, J17.22
/A5: J2.a12, J3.a12, J4.a12, J9.a12, J14.a12, J15.a12, J16.24, J17.24
/A6: J2.a13, J3.a13, J4.a13, J9.a13, J14.a13, J15.a13, J16.26, J17.26
/A7: J2.a14, J3.a14, J4.a14, J9.a14, J14.a14, J15.a14, J16.28, J17.28
/A8: J2.a15, J3.a15, J4.a15, J9.a15, J14.a15, J15.a15, J16.30, J17.30
/A9: J2.a16, J3.a16, J4.a16, J9.a16, J14.a16, J15.a16, J16.32, J17.32
/A10: J2.a17, J3.a17, J4.a17, J9.a17, J14.a17, J15.a17, J16.34, J17.34
/A11: J2.a18, J3.a18, J4.a18, J9.a18, J14.a18, J15.a18, J16.36, J17.36
/A12: J2.a19, J3.a19, J4.a19, J9.a19, J14.a19, J15.a19, J16.38, J17.38
/A13: J2.a20, J3.a20, J4.a20, J9.a20, J14.a20, J15.a20, J16.40, J17.40
/A14: J2.a21, J3.a21, J4.a21, J9.a21, J14.a21, J15.a21, J16.42, J17.42
/A15: J2.a22, J3.a22, J4.a22, J9.a22, J14.a22, J15.a22, J16.44, J17.44
/A16: J2.a25, J3.a25, J4.a25, J9.a25, J14.a25, J15.a25, J16.50, J17.50
/A17: J2.a26, J3.a26, J4.a26, J9.a26, J14.a26, J15.a26, J16.52, J17.52
/A18: J2.a27, J3.a27, J4.a27, J9.a27, J14.a27, J15.a27, J16.54, J17.54
/A19: J2.a28, J3.a28, J4.a28, J9.a28, J14.a28, J15.a28, J16.56, J17.56
/A20: J2.a29, J3.a29, J4.a29, J9.a29, J14.a29, J15.a29, J16.58, J17.58
/A21: J2.a30, J3.a30, J4.a30, J9.a30, J14.a30, J15.a30, J16.60, J17.60
/A22: J2.a31, J3.a31, J4.a31, J9.a31, J14.a31, J15.a31, J16.62, J17.62
/A23: J2.a32, J3.a32, J4.a32, J9.a32, J14.a32, J15.a32, J16.64, J17.64
/CLK_CPU: J2.b16, J3.b16, J4.b16, J9.b16, J14.b16, J15.b16, J16.31, J17.31
/D0: J2.b7, J3.b7, J4.b7, J9.b7, J14.b7, J15.b7, J16.13, J17.13
/D1: J2.b8, J3.b8, J4.b8, J9.b8, J14.b8, J15.b8, J16.15, J17.15
/D2: J2.b9, J3.b9, J4.b9, J9.b9, J14.b9, J15.b9, J16.17, J17.17
/D3: J2.b10, J3.b10, J4.b10, J9.b10, J14.b10, J15.b10, J16.19, J17.19
/D4: J2.b11, J3.b11, J4.b11, J9.b11, J14.b11, J15.b11, J16.21, J17.21
/D5: J2.b12, J3.b12, J4.b12, J9.b12, J14.b12, J15.b12, J16.23, J17.23
/D6: J2.b13, J3.b13, J4.b13, J9.b13, J14.b13, J15.b13, J16.25, J17.25
/D7: J2.b14, J3.b14, J4.b14, J9.b14, J14.b14, J15.b14, J16.27, J17.27
/MEMAQ: J2.a5, J3.a5, J4.a5, J9.a5, J14.a5, J15.a5, J16.10, J17.10
/~BUSACK: J2.a24, J3.a24, J4.a24, J9.a24, J14.a24, J15.a24, J16.48, J17.48
/~BUSREQ: J2.a23, J3.a23, J4.a23, J9.a23, J14.a23, J15.a23, J16.46, J17.46
/~HALT: J2.b21, J3.b21, J4.b21, J9.b21, J14.b21, J15.b21, J16.41, J17.41
/~INT0: J2.b4, J3.b4, J4.b4, J9.b4, J14.b4, J15.b4, J16.7, J17.7
/~INT1: J2.b5, J3.b5, J4.b5, J9.b5, J14.b5, J15.b5, J16.9, J17.9
/~INT2: J2.b6, J3.b6, J4.b6, J9.b6, J14.b6, J15.b6, J16.11, J17.11
/~INT3: J2.a6, J3.a6, J4.a6, J9.a6, J14.a6, J15.a6, J16.12, J17.12
/~INT: J2.b17, J3.b17, J4.b17, J9.b17, J14.b17, J15.b17, J16.33, J17.33
/~IOREQ: J2.b25, J3.b25, J4.b25, J9.b25, J14.b25, J15.b25, J16.49, J17.49
/~M1: J2.b19, J3.b19, J4.b19, J9.b19, J14.b19, J15.b19, J16.37, J17.37
/~MREQ: J2.b24, J3.b24, J4.b24, J9.b24, J14.b24, J15.b24, J16.47, J17.47
/~NMI: J2.b18, J3.b18, J4.b18, J9.b18, J14.b18, J15.b18, J16.35, J17.35
/~RD: J2.b22, J3.b22, J4.b22, J9.b22, J14.b22, J15.b22, J16.43, J17.43
/~RESET: J2.b15, J3.b15, J4.b15, J9.b15, J14.b15, J15.b15, J16.29, J17.29
/~WAIT: J2.b20, J3.b20, J4.b20, J9.b20, J14.b20, J15.b20, J16.39, J17.39
/~WR: J2.b23, J3.b23, J4.b23, J9.b23, J14.b23, J15.b23, J16.45, J17.45
GND: H1.1, H2.1, H3.1, H4.1, H5.1, H6.1, H7.1, H8.1, H9.1, H10.1, H11.1, H12.1, J2.a1, J2.a2, J2.a3, J2.a4, J2.b32, J3.a1, J3.a2, J3.a3, J3.a4, J3.b32, J4.a1, J4.a2, J4.a3, J4.a4, J4.b32, J7.1, J8.1, J9.a1, J9.a2, J9.a3, J9.a4, J9.b32, J14.a1, J14.a2, J14.a3, J14.a4, J14.b32, J15.a1, J15.a2, J15.a3, J15.a4, J15.b32, J16.2, J16.4, J16.6, J16.8, J16.63, J17.2, J17.4, J17.6, J17.8, J17.63

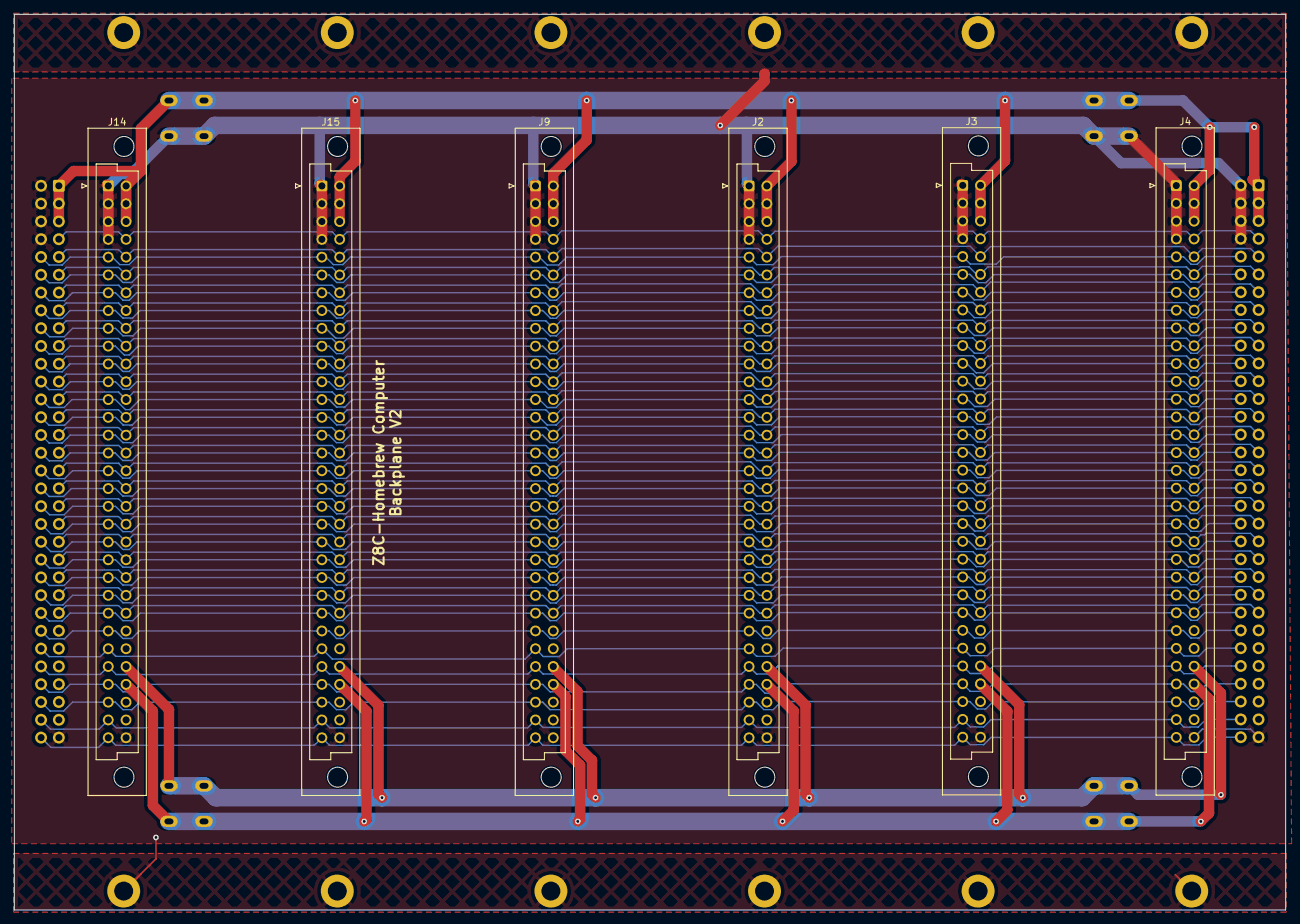
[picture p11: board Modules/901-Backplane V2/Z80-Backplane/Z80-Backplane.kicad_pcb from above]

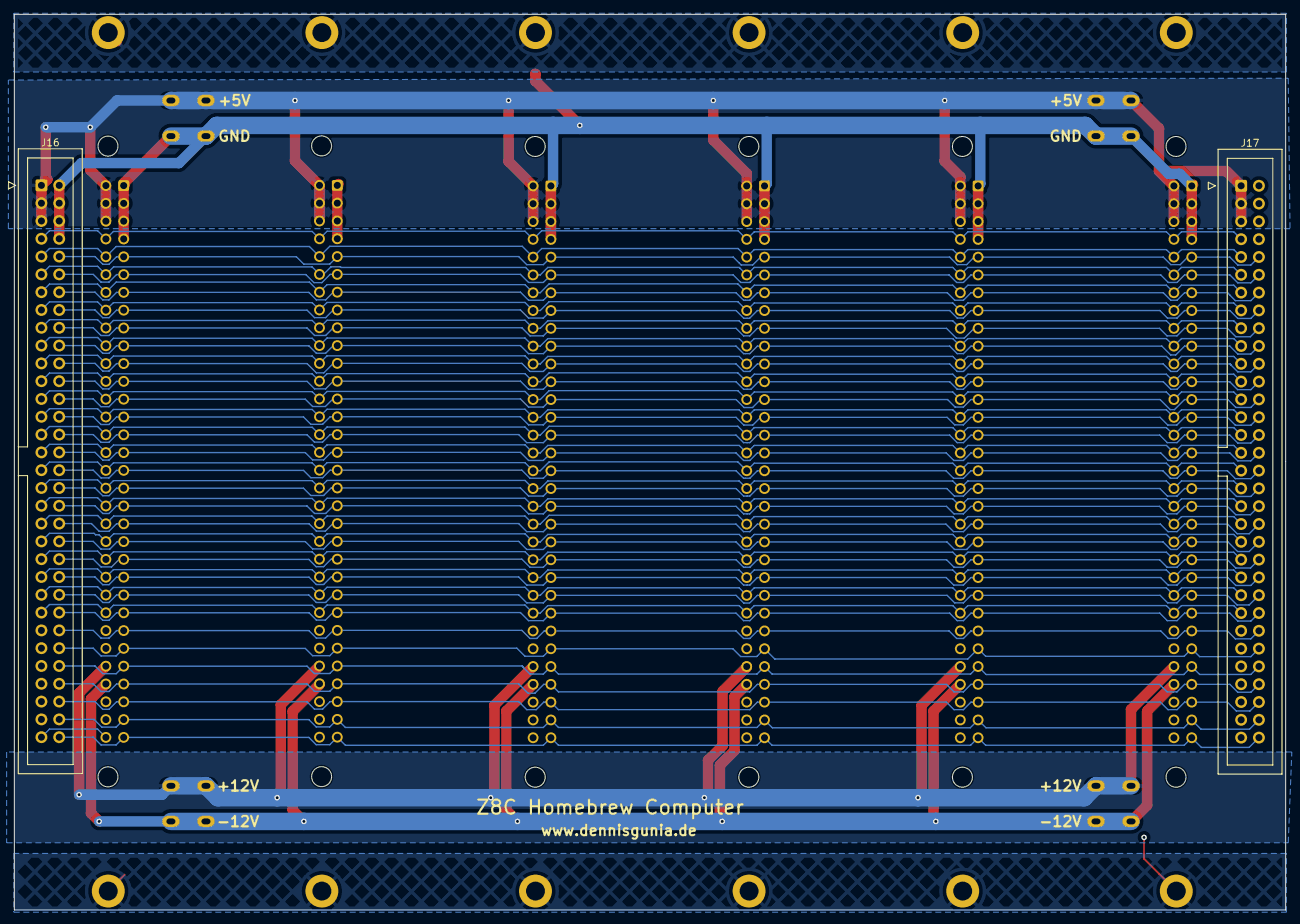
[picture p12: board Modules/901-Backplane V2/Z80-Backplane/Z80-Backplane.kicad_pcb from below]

Board: 2 copper layers, 181.4 x 127.8 mm, 28 parts (10 on the bottom side), 54 nets.

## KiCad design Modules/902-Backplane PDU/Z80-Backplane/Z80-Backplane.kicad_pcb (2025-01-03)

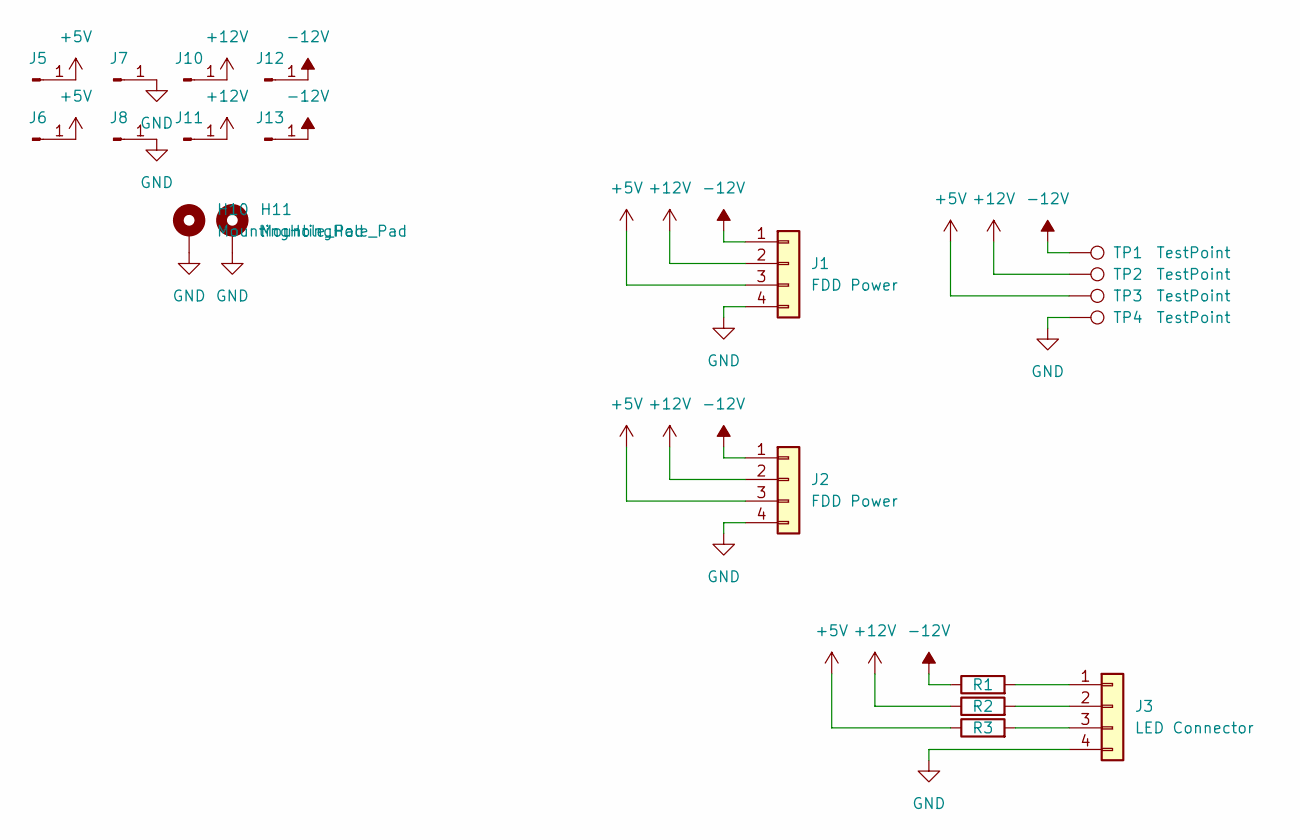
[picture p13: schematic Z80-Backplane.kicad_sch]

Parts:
H10, H11: MountingHole_Pad; MountingHole_2.7mm_M2.5_DIN965_Pad
J1, J2: FDD Power; Molex_Mini-Fit_Jr_5566-04A_2x02_P4.20mm_Vertical
J3: LED Connector; JST_EH_B4B-EH-A_1x04_P2.50mm_Vertical
J5, J6, J7, J8, J10, J11, J12, J13: Conn_01x01_Male; FS-P475
R1, R2, R3: R; R_Axial_DIN0207_L6.3mm_D2.5mm_P10.16mm_Horizontal
TP1, TP2, TP3, TP4: TestPoint; TestPoint_THTPad_D1.5mm_Drill0.7mm

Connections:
+5V: J1.3, J2.3, J5.1, J6.1, R3.1, TP3.1
+12V: J1.2, J2.2, J10.1, J11.1, R2.1, TP2.1
-12V: J1.1, J2.1, J12.1, J13.1, R1.1, TP1.1
GND: H10.1, H11.1, J1.4, J2.4, J3.4, J7.1, J8.1, TP4.1
unnamed: J3.1, R1.2
unnamed: J3.2, R2.2
unnamed: J3.3, R3.2

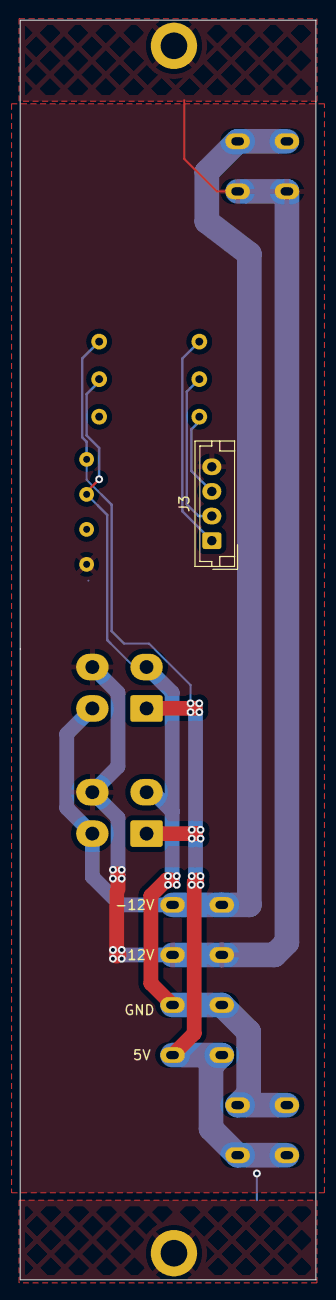
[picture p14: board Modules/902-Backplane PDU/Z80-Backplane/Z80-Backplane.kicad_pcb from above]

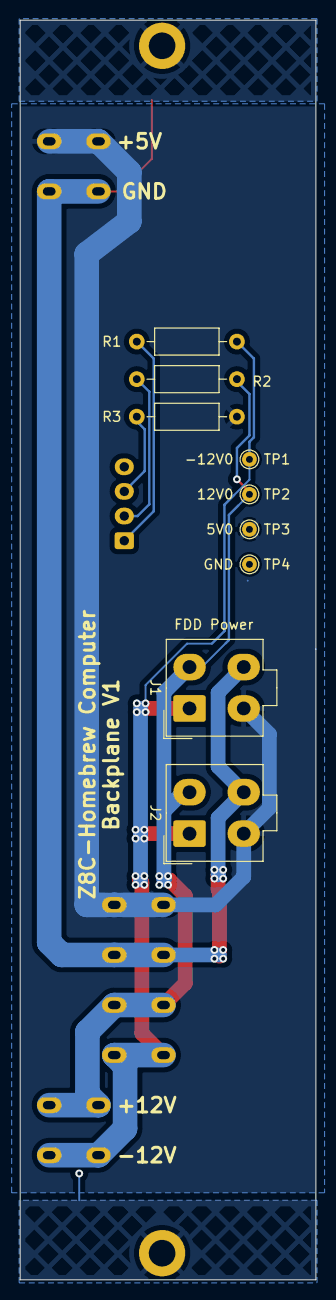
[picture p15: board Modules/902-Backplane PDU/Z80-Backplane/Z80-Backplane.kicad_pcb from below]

Board: 2 copper layers, 30.0 x 127.8 mm, 20 parts (13 on the bottom side), 7 nets.

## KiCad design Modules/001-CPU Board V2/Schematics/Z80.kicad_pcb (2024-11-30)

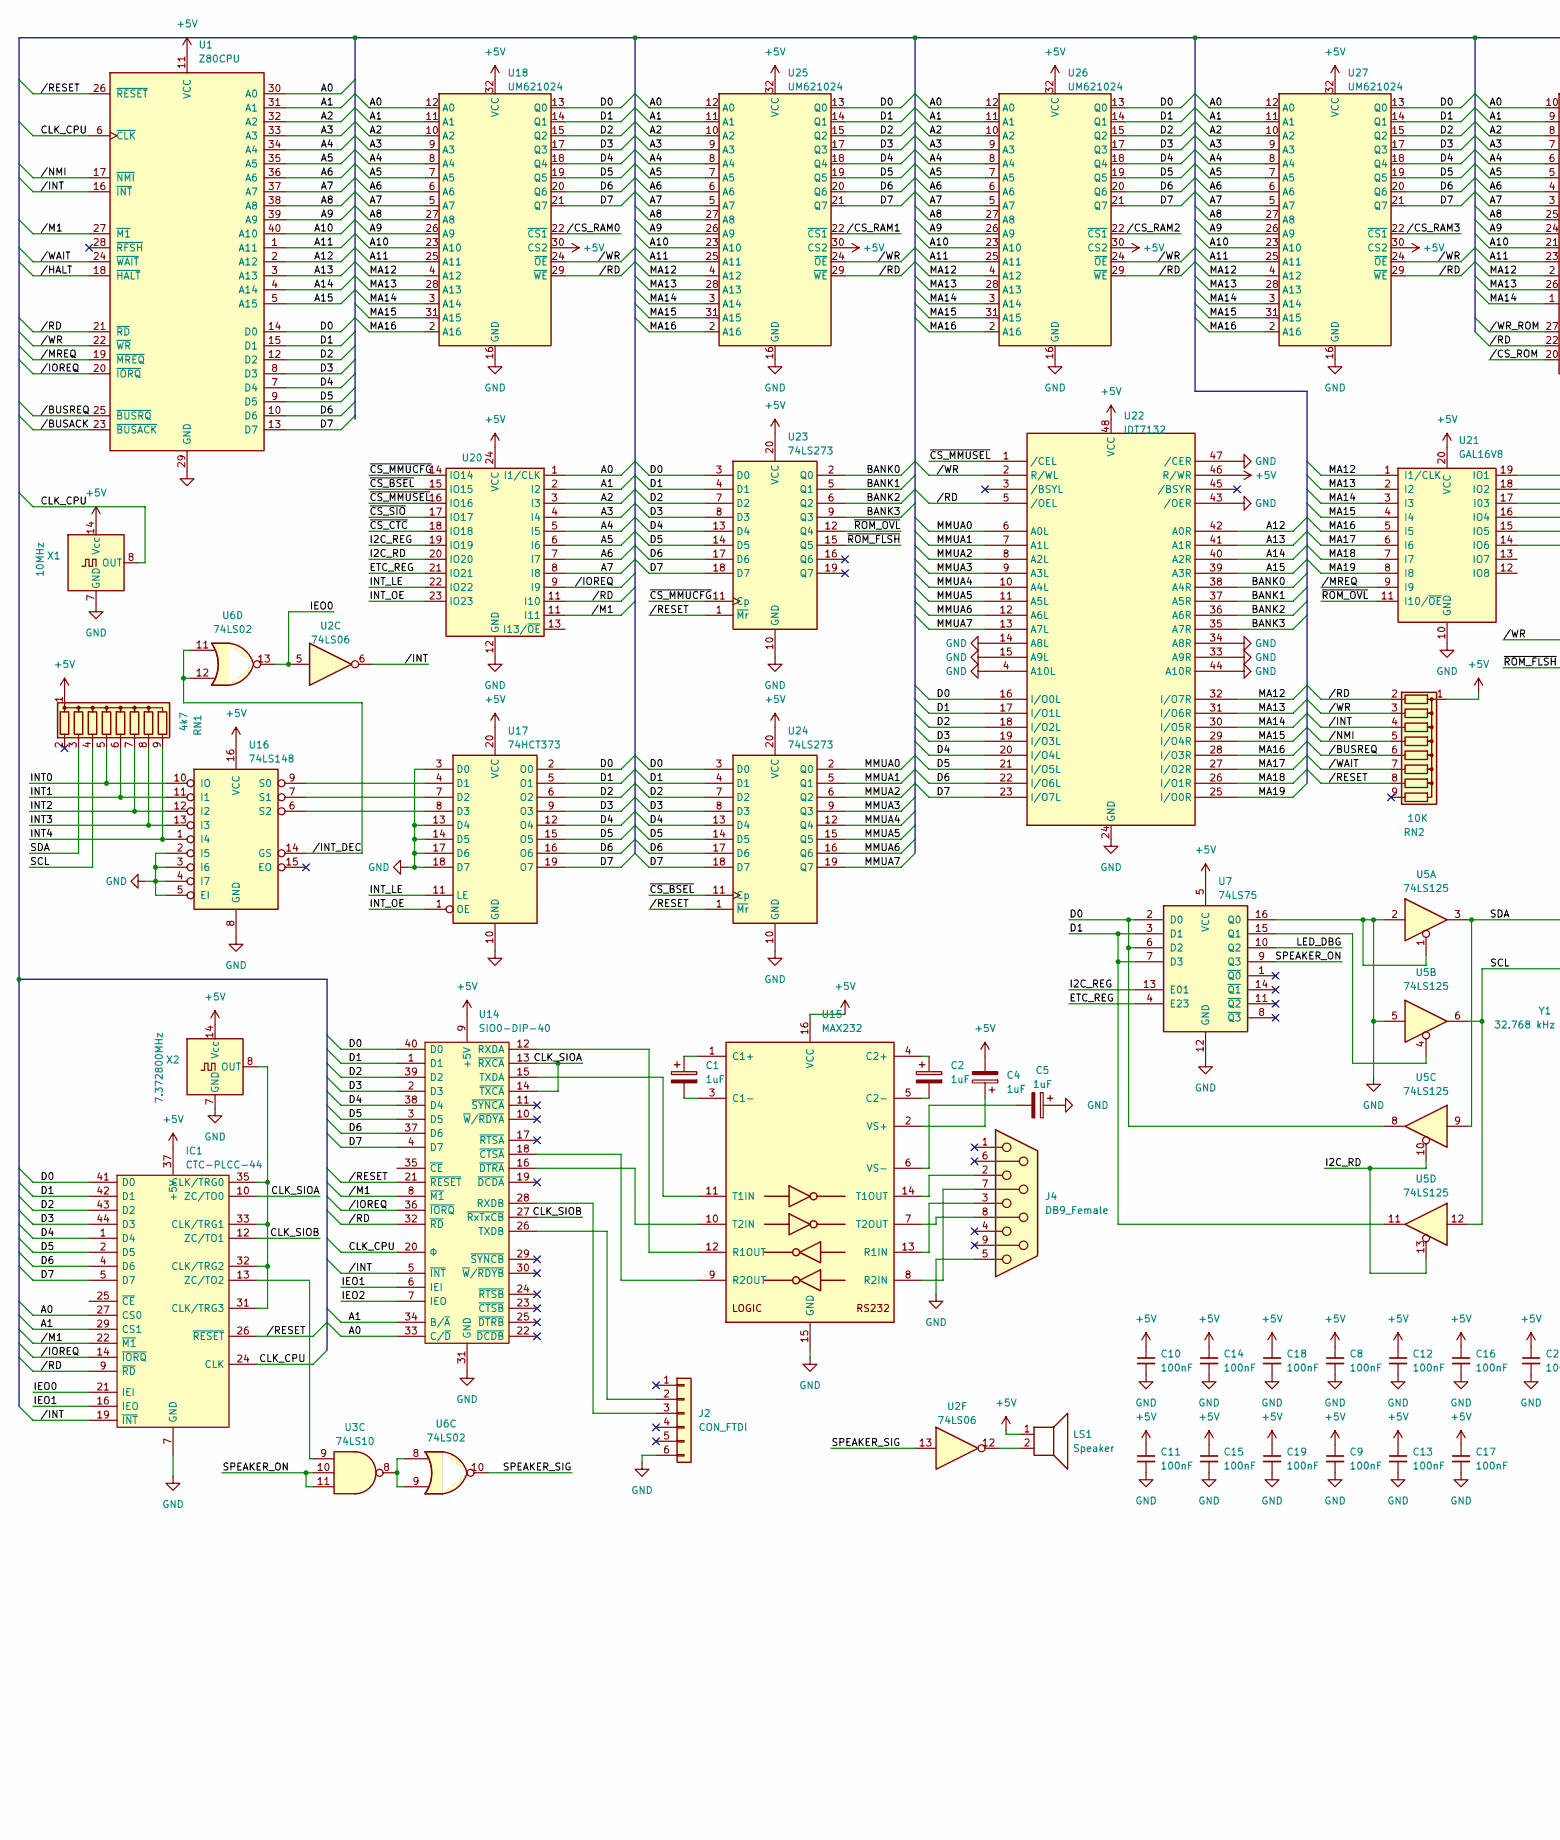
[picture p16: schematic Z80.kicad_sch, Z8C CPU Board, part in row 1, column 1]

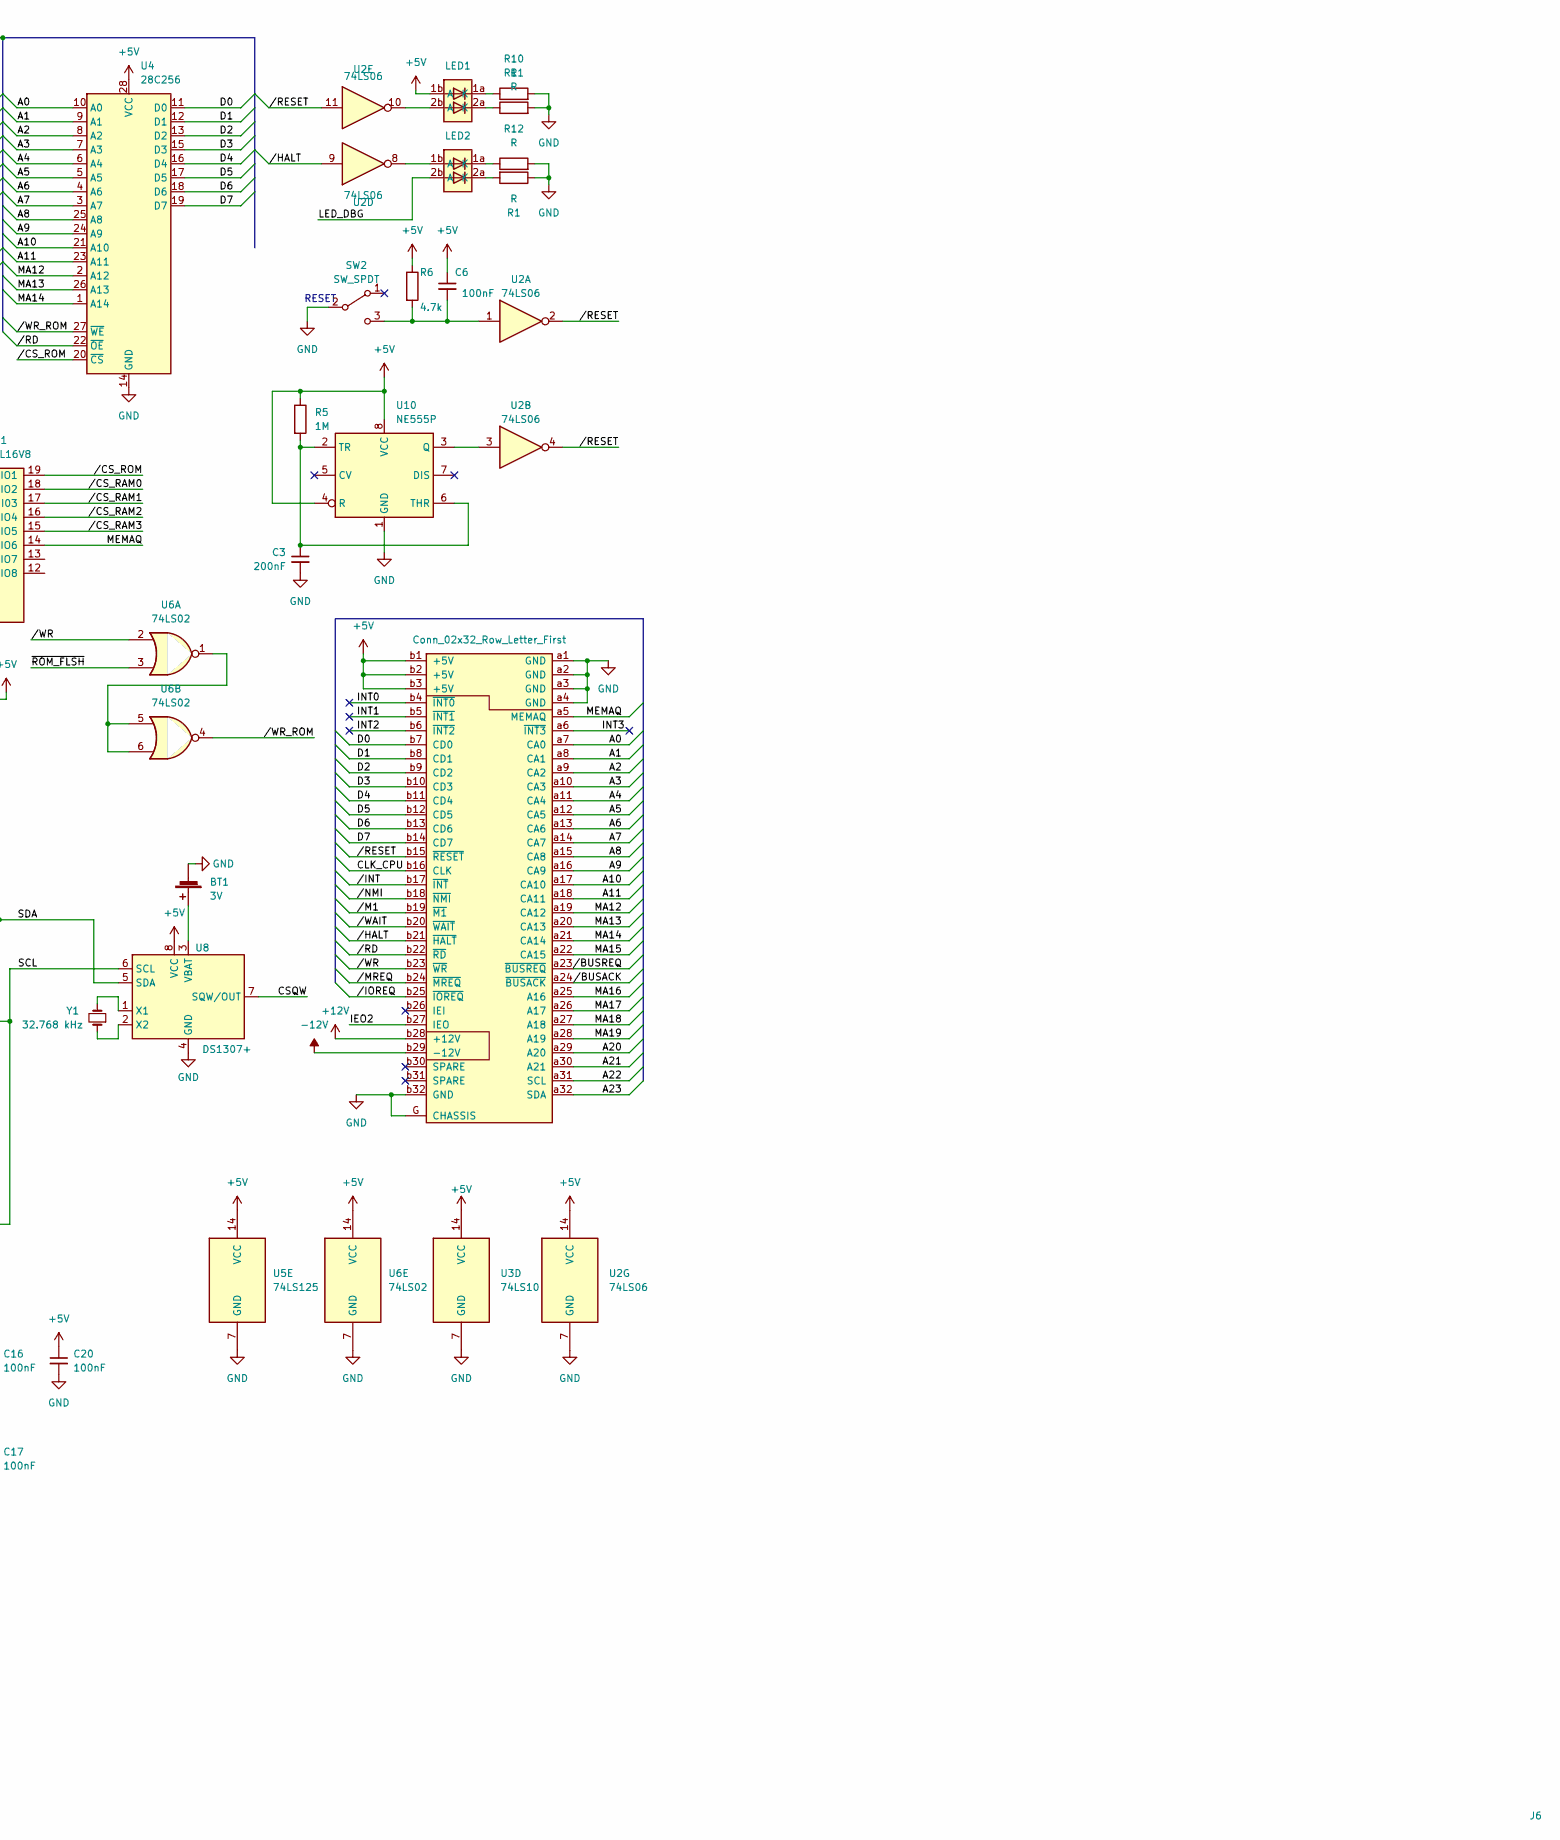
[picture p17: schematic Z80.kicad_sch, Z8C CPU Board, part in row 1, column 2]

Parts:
BT1: 3V; Battery_Holder_Coin_2032_BS-7
C1, C2, C4, C5: 1uF; CP_Radial_D6.3mm_P2.50mm
C3: 200nF; C_Rect_L7.0mm_W2.0mm_P5.00mm
C6, C8, C9, C10, C11, C12, C13, C14, C15, C16, C17, C18, C19, C20: 100nF; C_Rect_L7.0mm_W2.0mm_P5.00mm
IC1: CTC-PLCC-44; PLCC-44_THT-Socket; Manufacturer_Part_Number Z84C3010PEG; Mouser Part Number 692-Z84C3010PEG
J2: CON_FTDI; PinSocket_1x06_P2.54mm_Vertical
J4: DB9_Female; DSUB-9_Female_Horizontal_P2.77x2.84mm_EdgePinOffset9.90mm_H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
J6: Conn_02x32_Row_Letter_First; Z8C Card
LED1, LED2: MENOTR_A500_Dual_3mm; MENTOR A500 Dual 3mm
LS1: Speaker; Piezo_Transducer_THT_PS1240P02BT
R1, R10, R11, R12: R; R_Axial_DIN0204_L3.6mm_D1.6mm_P2.54mm_Vertical
R5: 1M; R_Axial_DIN0204_L3.6mm_D1.6mm_P2.54mm_Vertical
R6: 4.7k; R_Axial_DIN0204_L3.6mm_D1.6mm_P2.54mm_Vertical
RN1: 4k7; R_Array_SIP9
RN2: 10K; R_Array_SIP9
SW2: SW_SPDT; Toggle_Switch_100SP1T2B4M6QE
U1: Z80CPU; DIP-40_W15.24mm_Socket_LongPads
U2: 74LS06; DIP-14_W7.62mm
U3: 74LS10
U4: 28C256; DIP_Socket-28_W11.9_W12.7_W15.24_W17.78_W18.5_3M_228-1277-0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
U5: 74LS125; DIP-14_W7.62mm_Socket
U6: 74LS02
U7: 74LS75; DIP-16_W7.62mm_Socket
U8: DS1307+; DIP-8_W7.62mm
U10: NE555P; DIP-8_W7.62mm_Socket_LongPads
U14: SIO0-DIP-40; DIP-40_W15.24mm_Socket_LongPads; Manufacturer_Part_Number Z84C4206PEG; Mouser Part Number 692-Z84C4206PEG
U15: MAX232; DIP-16_W7.62mm_Socket_LongPads
U16: 74LS148; DIP-16_W7.62mm
U17: 74HCT373; DIP-20_W7.62mm
U18, U25, U26, U27: UM621024; DIP-32_W7.62mm
U20: DIP-24_W7.62mm
U21: GAL16V8; DIP-20_W7.62mm_Socket_LongPads
U22: IDT7132; PLCC-52_THT-Socket
U23, U24: 74LS273; DIP-20_W7.62mm
X1: 10MHz; Oscillator_DIP-14
X2: 7.372800MHz; Oscillator_DIP-14
Y1: 32.768 kHz; Crystal_AT310_D3.0mm_L10.0mm_Horizontal

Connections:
+5V: C4.2, C6.1, C8.1, C9.1, C10.1, C11.1, C12.1, C13.1, C14.1, C15.1, C16.1, C17.1, C18.1, C19.1, C20.1, IC1.37 (+5V), J6.b1 (+5V), J6.b2 (+5V), J6.b3 (+5V), LED1.1b (A), LS1.1, R5.1, R6.1, RN1.1 (common), RN2.1 (common), U1.11 (VCC), U2.14 (VCC), U3.14 (VCC), U4.28 (VCC), U5.14 (VCC), U6.14 (VCC), U7.5 (VCC), U8.8 (VCC), U10.4 (R), U10.8 (VCC), U14.9 (+5V), U15.16 (VCC), U16.16 (VCC), U17.20 (VCC), U18.30 (CS2), U18.32 (VCC), U20.24 (VCC), U21.20 (VCC), U22.46 (R/WR), U22.48 (VCC), U23.20 (VCC), U24.20 (VCC), U25.30 (CS2), U25.32 (VCC), U26.30 (CS2), U26.32 (VCC), U27.30 (CS2), U27.32 (VCC), X1.14 (Vcc), X2.14 (Vcc)
+12V: J6.b28 (+12V)
-12V: J6.b29 (-12V)
/A0: IC1.27 (CS0), J6.a7 (CA0), U1.30 (A0), U4.10 (A0), U14.33 (C/~D), U18.12 (A0), U20.1 (I1/CLK), U25.12 (A0), U26.12 (A0), U27.12 (A0)
/A1: IC1.29 (CS1), J6.a8 (CA1), U1.31 (A1), U4.9 (A1), U14.34 (B/~A), U18.11 (A1), U20.2 (I2), U25.11 (A1), U26.11 (A1), U27.11 (A1)
/A2: J6.a9 (CA2), U1.32 (A2), U4.8 (A2), U18.10 (A2), U20.3 (I3), U25.10 (A2), U26.10 (A2), U27.10 (A2)
/A3: J6.a10 (CA3), U1.33 (A3), U4.7 (A3), U18.9 (A3), U20.4 (I4), U25.9 (A3), U26.9 (A3), U27.9 (A3)
/A4: J6.a11 (CA4), U1.34 (A4), U4.6 (A4), U18.8 (A4), U20.5 (I5), U25.8 (A4), U26.8 (A4), U27.8 (A4)
/A5: J6.a12 (CA5), U1.35 (A5), U4.5 (A5), U18.7 (A5), U20.6 (I6), U25.7 (A5), U26.7 (A5), U27.7 (A5)
/A6: J6.a13 (CA6), U1.36 (A6), U4.4 (A6), U18.6 (A6), U20.7 (I7), U25.6 (A6), U26.6 (A6), U27.6 (A6)
/A7: J6.a14 (CA7), U1.37 (A7), U4.3 (A7), U18.5 (A7), U20.8 (I8), U25.5 (A7), U26.5 (A7), U27.5 (A7)
/A8: J6.a15 (CA8), U1.38 (A8), U4.25 (A8), U18.27 (A8), U25.27 (A8), U26.27 (A8), U27.27 (A8)
/A9: J6.a16 (CA9), U1.39 (A9), U4.24 (A9), U18.26 (A9), U25.26 (A9), U26.26 (A9), U27.26 (A9)
/A10: J6.a17 (CA10), U1.40 (A10), U4.21 (A10), U18.23 (A10), U25.23 (A10), U26.23 (A10), U27.23 (A10)
/A11: J6.a18 (CA11), U1.1 (A11), U4.23 (A11), U18.25 (A11), U25.25 (A11), U26.25 (A11), U27.25 (A11)
/A12: U1.2 (A12), U22.42 (A0R)
/A13: U1.3 (A13), U22.41 (A1R)
/A14: U1.4 (A14), U22.40 (A2R)
/A15: U1.5 (A15), U22.39 (A3R)
/A20: J6.a29 (A20)
/A21: J6.a30 (A21)
/A22: J6.a31 (SCL)
/A23: J6.a32 (SDA)
/BANK0: U22.38 (A4R), U23.2 (Q0)
/BANK1: U22.37 (A5R), U23.5 (Q1)
/BANK2: U22.36 (A6R), U23.6 (Q2)
/BANK3: U22.35 (A7R), U23.9 (Q3)
/CLK_CPU: IC1.24 (CLK), J6.b16 (CLK), U1.6 (~CLK), U14.20 (Φ), X1.8 (OUT)
/CLK_SIOA: IC1.10 (ZC/TO0), U14.13 (~RXCA), U14.14 (~TXCA)
/CLK_SIOB: IC1.12 (ZC/TO1), U14.27 (~RxTxCB)
/CSQW: U8.7 (SQW/OUT)
/D0: IC1.41 (D0), J6.b7 (CD0), U1.14 (D0), U4.11 (D0), U5.8, U7.2 (D0), U7.6 (D2), U14.40 (D0), U17.2 (O0), U18.13 (Q0), U22.16 (I/O0L), U23.3 (D0), U24.3 (D0), U25.13 (Q0), U26.13 (Q0), U27.13 (Q0)
/D1: IC1.42 (D1), J6.b8 (CD1), U1.15 (D1), U4.12 (D1), U5.11, U7.3 (D1), U7.7 (D3), U14.1 (D1), U17.5 (O1), U18.14 (Q1), U22.17 (I/O1L), U23.4 (D1), U24.4 (D1), U25.14 (Q1), U26.14 (Q1), U27.14 (Q1)
/D2: IC1.43 (D2), J6.b9 (CD2), U1.12 (D2), U4.13 (D2), U14.39 (D2), U17.6 (O2), U18.15 (Q2), U22.18 (I/O2L), U23.7 (D2), U24.7 (D2), U25.15 (Q2), U26.15 (Q2), U27.15 (Q2)
/D3: IC1.44 (D3), J6.b10 (CD3), U1.8 (D3), U4.15 (D3), U14.2 (D3), U17.9 (O3), U18.17 (Q3), U22.19 (I/O3L), U23.8 (D3), U24.8 (D3), U25.17 (Q3), U26.17 (Q3), U27.17 (Q3)
/D4: IC1.1 (D4), J6.b11 (CD4), U1.7 (D4), U4.16 (D4), U14.38 (D4), U17.12 (O4), U18.18 (Q4), U22.20 (I/O4L), U23.13 (D4), U24.13 (D4), U25.18 (Q4), U26.18 (Q4), U27.18 (Q4)
/D5: IC1.2 (D5), J6.b12 (CD5), U1.9 (D5), U4.17 (D5), U14.3 (D5), U17.15 (O5), U18.19 (Q5), U22.21 (I/O5L), U23.14 (D5), U24.14 (D5), U25.19 (Q5), U26.19 (Q5), U27.19 (Q5)
/D6: IC1.4 (D6), J6.b13 (CD6), U1.10 (D6), U4.18 (D6), U14.37 (D6), U17.16 (O6), U18.20 (Q6), U22.22 (I/O6L), U23.17 (D6), U24.17 (D6), U25.20 (Q6), U26.20 (Q6), U27.20 (Q6)
/D7: IC1.5 (D7), J6.b14 (CD7), U1.13 (D7), U4.19 (D7), U14.4 (D7), U17.19 (O7), U18.21 (Q7), U22.23 (I/O7L), U23.18 (D7), U24.18 (D7), U25.21 (Q7), U26.21 (Q7), U27.21 (Q7)
/ETC_REG: U7.4 (E23), U20.21 (IO21)
/I2C_RD: U5.10, U5.13, U20.20 (IO20)
/I2C_REG: U7.13 (E01), U20.19 (IO19)
/IEO0: IC1.21 (IEI), U2.5, U6.13
/IEO1: IC1.16 (IEO), U14.6 (IEI)
/IEO2: J6.b27 (IEO), U14.7 (IEO)
/INT0: J6.b4 (~INT0), RN1.5 (R4), U16.10 (IO)
/INT1: J6.b5 (~INT1), RN1.6 (R5), U16.11 (I1)
/INT2: J6.b6 (~INT2), RN1.7 (R6), U16.12 (I2)
/INT3: J6.a6 (~INT3), RN1.8 (R7), U16.13 (I3)
/INT4: RN1.9 (R8), U16.1 (I4)
/INT_LE: U17.11 (LE), U20.22 (IO22)
/INT_OE: U17.1 (OE), U20.23 (IO23)
/LED_DBG: LED2.2b (A), U7.10 (Q2)
/MA12: J6.a19 (CA12), U4.2 (A12), U18.4 (A12), U21.1 (I1/CLK), U22.32 (I/O7R), U25.4 (A12), U26.4 (A12), U27.4 (A12)
/MA13: J6.a20 (CA13), U4.26 (A13), U18.28 (A13), U21.2 (I2), U22.31 (I/O6R), U25.28 (A13), U26.28 (A13), U27.28 (A13)
/MA14: J6.a21 (CA14), U4.1 (A14), U18.3 (A14), U21.3 (I3), U22.30 (I/O5R), U25.3 (A14), U26.3 (A14), U27.3 (A14)
/MA15: J6.a22 (CA15), U18.31 (A15), U21.4 (I4), U22.29 (I/O4R), U25.31 (A15), U26.31 (A15), U27.31 (A15)
/MA16: J6.a25 (A16), U18.2 (A16), U21.5 (I5), U22.28 (I/O3R), U25.2 (A16), U26.2 (A16), U27.2 (A16)
/MA17: J6.a26 (A17), U21.6 (I6), U22.27 (I/O2R)
/MA18: J6.a27 (A18), U21.7 (I7), U22.26 (I/O1R)
/MA19: J6.a28 (A19), U21.8 (I8), U22.25 (I/O0R)
/MEMAQ: J6.a5 (MEMAQ), U21.14 (IO6)
/MMUA0: U22.6 (A0L), U24.2 (Q0)
/MMUA1: U22.7 (A1L), U24.5 (Q1)
/MMUA2: U22.8 (A2L), U24.6 (Q2)
/MMUA3: U22.9 (A3L), U24.9 (Q3)
/MMUA4: U22.10 (A4L), U24.12 (Q4)
/MMUA5: U22.11 (A5L), U24.15 (Q5)
/MMUA6: U22.12 (A6L), U24.16 (Q6)
/MMUA7: U22.13 (A7L), U24.19 (Q7)
/SCL: RN1.4 (R3), U5.6, U5.12, U8.6 (SCL)
/SDA: RN1.3 (R2), U5.3, U5.9, U8.5 (SDA)
/SPEAKER_ON: U3.10, U3.11, U7.9 (Q3)
/SPEAKER_SIG: U2.13, U6.10
//BUSACK: J6.a24 (~BUSACK), U1.23 (~BUSACK)
//BUSREQ: J6.a23 (~BUSREQ), RN2.6 (R5), U1.25 (~BUSRQ)
//CS_RAM0: U18.22 (~CS1), U21.18 (IO2)
//CS_RAM1: U21.17 (I03), U25.22 (~CS1)
//CS_RAM2: U21.16 (IO4), U26.22 (~CS1)
//CS_RAM3: U21.15 (IO5), U27.22 (~CS1)
//CS_ROM: U4.20 (~CS), U21.19 (IO1)
//HALT: J6.b21 (~HALT), U1.18 (~HALT), U2.9
//INT: IC1.19 (~INT), J6.b17 (~INT), RN2.4 (R3), U1.16 (~INT), U2.6, U14.5 (~INT)
//INT_DEC: U6.11, U6.12, U16.14 (GS)
//IOREQ: IC1.14 (~IORQ), J6.b25 (~IOREQ), U1.20 (~IORQ), U14.36 (~IORQ), U20.9 (I9)
//MREQ: J6.b24 (~MREQ), U1.19 (~MREQ), U21.9 (I9)
//NMI: J6.b18 (~NMI), RN2.5 (R4), U1.17 (~NMI)
//RESET: IC1.26 (~RESET), J6.b15 (~RESET), RN2.8 (R7), U1.26 (~RESET), U2.2, U2.4, U2.11, U14.21 (~RESET), U23.1 (~Mr), U24.1 (~Mr)
//WAIT: J6.b20 (~WAIT), RN2.7 (R6), U1.24 (~WAIT)
//WR_ROM: U4.27 (~WE), U6.4
/~CS_BSEL: U20.15 (IO15), U24.11 (Cp)
/~CS_CTC: U20.18 (IO18)
/~CS_MMUCFG: U20.14 (IO14), U23.11 (Cp)
/~CS_MMUSEL: U20.16 (IO16), U22.1 (/CEL)
/~CS_SIO: U20.17 (IO17)
/~ROM_FLSH: U6.3, U23.15 (Q5)
/~ROM_OVL: U21.11 (I10/~OE), U23.12 (Q4)
unnamed: IC1.31 (CLK/TRG3), IC1.32 (CLK/TRG2), IC1.33 (CLK/TRG1), IC1.35 (CLK/TRG0), X2.8 (OUT)
unnamed: IC1.13 (ZC/TO2), U3.9
unnamed: J2.2, U14.26 (TXDB)
unnamed: J2.3, U14.28 (RXDB)
unnamed: LED1.2b (A), U2.10
unnamed: LED1.1a (K), R10.1
unnamed: LED1.2a (K), R11.1
unnamed: LED2.1b (A), U2.8
unnamed: LED2.1a (K), R12.1
unnamed: LED2.2a (K), R1.2
unnamed: LS1.2, U2.12
unnamed: C6.2, R6.2, SW2.3 (C), U2.1
unnamed: U3.8, U6.8, U6.9
unnamed: U6.1, U6.5, U6.6
unnamed: U5.4, U7.15 (Q1)
unnamed: BT1.pos, U8.3 (VBAT)
unnamed: U8.1 (X1), Y1.2
unnamed: U8.2 (X2), Y1.1
unnamed: U2.3, U10.3 (Q)
unnamed: C3.1, R5.2, U10.2 (TR), U10.6 (THR)
unnamed: U14.12 (RXDA), U15.12 (R1OUT)
unnamed: U14.15 (TXDA), U15.11 (T1IN)
unnamed: U14.18 (~CTSA), U15.9 (R2OUT)
unnamed: U14.16 (~DTRA), U15.10 (T2IN)
unnamed: C1.1, U15.1 (C1+)
unnamed: C1.2, U15.3 (C1-)
unnamed: C2.1, U15.4 (C2+)
unnamed: C2.2, U15.5 (C2-)
unnamed: J4.3, U15.13 (R1IN)
unnamed: J4.7, U15.8 (R2IN)
unnamed: J4.2, U15.14 (T1OUT)
unnamed: J4.8, U15.7 (T2OUT)
unnamed: C4.1, U15.2 (VS+)
unnamed: C5.2, U15.6 (VS-)
unnamed: U16.9 (S0), U17.4 (D1)
unnamed: U16.7 (S1), U17.7 (D2)
unnamed: U16.6 (S2), U17.8 (D3)

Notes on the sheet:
RESET

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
Board: 2 copper layers, 59 parts (0 on the bottom side), 121 nets, no tracks yet.

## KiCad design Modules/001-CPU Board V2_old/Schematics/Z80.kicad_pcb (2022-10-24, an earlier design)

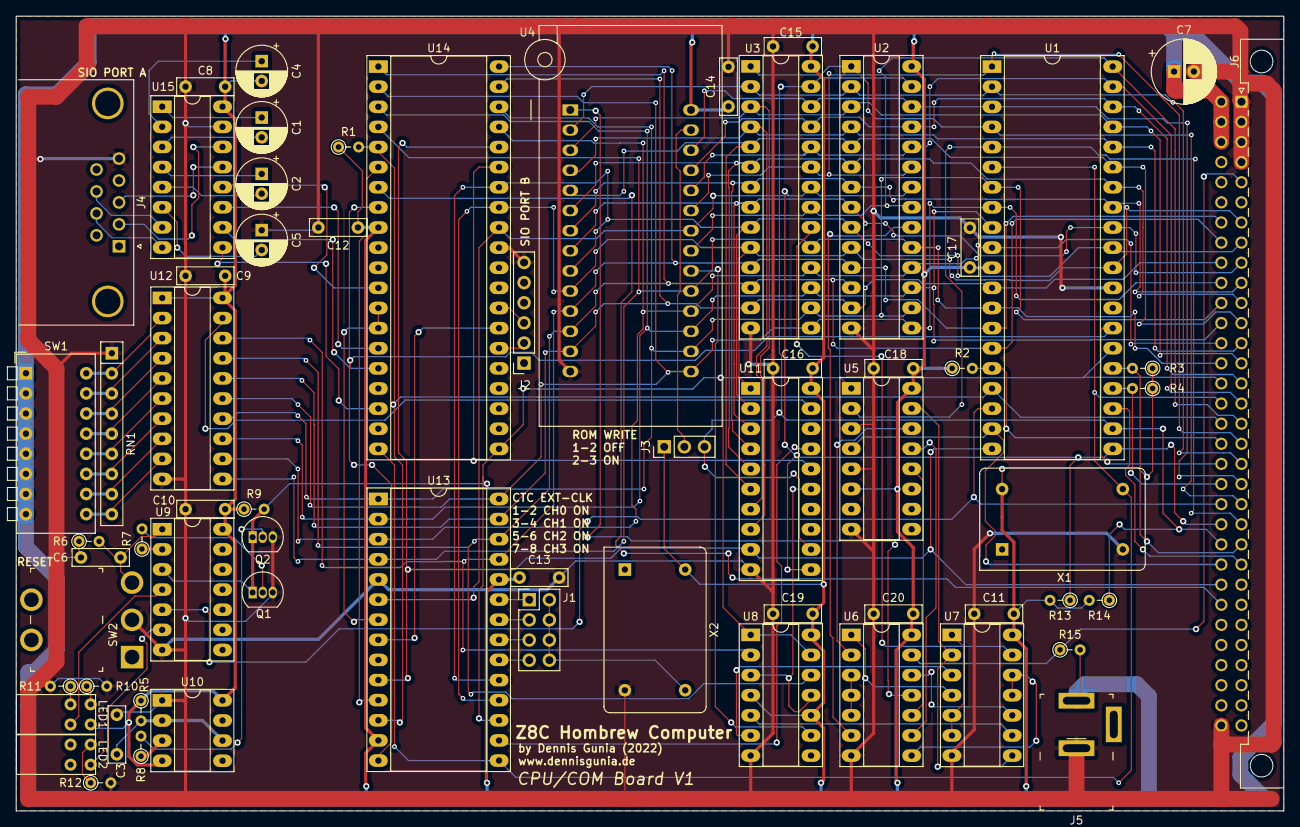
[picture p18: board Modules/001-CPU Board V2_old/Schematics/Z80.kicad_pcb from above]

Board: 2 copper layers, 160.0 x 100.3 mm, 65 parts (0 on the bottom side), 104 nets.

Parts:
C1, C2, C4, C5: 1uF; CP_Radial_D6.3mm_P2.50mm
C3: 200nF; C_Rect_L7.0mm_W2.0mm_P5.00mm
C6, C8, C9, C10, C11, C12, C13, C14, C15, C16, C17, C18, C19, C20: 100nF; C_Rect_L7.0mm_W2.0mm_P5.00mm
C7: 100uF; CP_Radial_D8.0mm_P2.50mm
J1: CTC_CLK_SEL; PinHeader_2x04_P2.54mm_Vertical
J2: CON_FTDI; PinSocket_1x06_P2.54mm_Vertical
J3: ROM_/WR_EN; PinHeader_1x03_P2.54mm_Vertical
J4: DB9_Female; DSUB-9_Female_Horizontal_P2.77x2.84mm_EdgePinOffset9.90mm_H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
J5: Barrel_Jack; Barrel_Jack_5.5mmODx2.1mmID_PJ-202A
J6: Conn_02x32_Row_Letter_First; DIN41612_Q_2x32_Male_Horizontal_THT
LED1, LED2: MENOTR_A500_Dual_3mm; MENTOR A500 Dual 3mm
Q1, Q2: BC548; TO-92_Inline
R1, R2, R3, R4, R6, R9, R13, R14, R15: 4.7k; R_Axial_DIN0204_L3.6mm_D1.6mm_P2.54mm_Vertical
R5: 1M; R_Axial_DIN0204_L3.6mm_D1.6mm_P2.54mm_Vertical
R7, R8: 220; R_Axial_DIN0204_L3.6mm_D1.6mm_P2.54mm_Vertical
R10, R11, R12: R; R_Axial_DIN0204_L3.6mm_D1.6mm_P2.54mm_Vertical
RN1: 10k; R_Array_SIP9
SW1: SW_DIP_x08; SW_DIP_SPSTx08_Piano_CTS_Series194-8MSTN_W7.62mm_P2.54mm
SW2: SW_SPDT; Toggle_Switch_100SP1T2B4M6QE
U1: Z80CPU; DIP-40_W15.24mm_Socket_LongPads
U2, U3: HM62256BLP; DIP-28_W7.62mm_Socket_LongPads
U4: 28C256; DIP_Socket-28_W11.9_W12.7_W15.24_W17.78_W18.5_3M_228-1277-0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
U5: 74HC137; DIP-16_W7.62mm_Socket_LongPads
U6: 74HC00; DIP-14_W7.62mm_Socket_LongPads
U7: 74HC02; DIP-14_W7.62mm_Socket_LongPads
U8: 74HC74; DIP-14_W7.62mm_Socket_LongPads
U9: 74HC14; DIP-14_W7.62mm_Socket_LongPads
U10: NE555P; DIP-8_W7.62mm_Socket_LongPads
U11: GAL16V8; DIP-20_W7.62mm_Socket_LongPads
U12: 74HC245; DIP-20_W7.62mm_Socket_LongPads
U13: CTC-DIP-28; DIP-28_W15.24mm_Socket_LongPads
U14: SIO0-DIP-40; DIP-40_W15.24mm_Socket_LongPads
U15: MAX232; DIP-16_W7.62mm_Socket_LongPads
X1: 3.686411MHz; Oscillator_DIP-14
X2: 7.372800MHz; Oscillator_DIP-14

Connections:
+5V: C4.2, C6.1, C7.1, C8.1, C9.1, C10.1, C11.1, C12.1, C13.1, C14.1, C15.1, C16.1, C17.1, C18.1, C19.1, C20.1, J3.1, J5.1, J6.b1, J6.b2, J6.b3, LED1.1b (A), R1.1, R2.1, R3.1, R4.1, R5.1, R6.1, R9.1, R13.2, R14.2, R15.2, SW1.1, SW1.2, SW1.3, SW1.4, SW1.5, SW1.6, SW1.7, SW1.8, U1.11 (VCC), U2.28 (VCC), U3.28 (VCC), U4.28 (VCC), U5.6 (E2), U5.16 (VCC), U6.14 (VCC), U7.14 (VCC), U8.4 (~S), U8.10 (~S), U8.14 (VCC), U9.14 (VCC), U10.4 (R), U10.8 (VCC), U11.20 (VCC), U12.1 (A->B), U12.20 (VCC), U13.13 (IEI), U13.24 (+5V), U14.9 (+5V), U15.16 (VCC), X1.14 (Vcc), X2.14 (Vcc)
/A0: J6.a7, U1.30 (A0), U2.10 (A0), U3.10 (A0), U4.10 (A0), U11.1 (I1/CLK), U13.18 (CS0), U14.33 (C/~D)
/A1: J6.a8, U1.31 (A1), U2.9 (A1), U3.9 (A1), U4.9 (A1), U11.2 (I2), U13.19 (CS1), U14.34 (B/~A)
/A2: J6.a9, U1.32 (A2), U2.8 (A2), U3.8 (A2), U4.8 (A2), U11.3 (I3)
/A3: J6.a10, U1.33 (A3), U2.7 (A3), U3.7 (A3), U4.7 (A3), U11.4 (I4)
/A4: J6.a11, U1.34 (A4), U2.6 (A4), U3.6 (A4), U4.6 (A4), U11.5 (I5)
/A5: J6.a12, U1.35 (A5), U2.5 (A5), U3.5 (A5), U4.5 (A5), U11.6 (I6)
/A6: J6.a13, U1.36 (A6), U2.4 (A6), U3.4 (A6), U4.4 (A6), U11.7 (I7)
/A7: J6.a14, U1.37 (A7), U2.3 (A7), U3.3 (A7), U4.3 (A7), U11.8 (I8)
/A8: J6.a15, U1.38 (A8), U2.25 (A8), U3.25 (A8), U4.25 (A8)
/A9: J6.a16, U1.39 (A9), U2.24 (A9), U3.24 (A9), U4.24 (A9)
/A10: J6.a17, U1.40 (A10), U2.21 (A10), U3.21 (A10), U4.21 (A10)
/A11: J6.a18, U1.1 (A11), U2.23 (A11), U3.23 (A11), U4.23 (A11)
/A12: J6.a19, U1.2 (A12), U2.2 (A12), U3.2 (A12), U4.2 (A12)
/A13: J6.a20, U1.3 (A13), U2.26 (A13), U3.26 (A13), U4.26 (A13)
/A14: J6.a21, U1.4 (A14), U2.1 (A14), U3.1 (A14), U5.1 (A0)
/A15: J6.a22, U1.5 (A15), U5.2 (A1)
/CLK_CPU: J6.b16, U1.6 (~CLK), U13.15 (CLK), U14.20 (Φ), X1.8 (OUT)
/D0: J6.b7, U1.14 (D0), U2.11 (Q0), U3.11 (Q0), U4.11 (D0), U8.2 (D), U12.18 (B0), U13.25 (D0), U14.40 (D0)
/D1: J6.b8, U1.15 (D1), U2.12 (Q1), U3.12 (Q1), U4.12 (D1), U8.12 (D), U12.17 (B1), U13.26 (D1), U14.1 (D1)
/D2: J6.b9, U1.12 (D2), U2.13 (Q2), U3.13 (Q2), U4.13 (D2), U12.16 (B2), U13.27 (D2), U14.39 (D2)
/D3: J6.b10, U1.8 (D3), U2.15 (Q3), U3.15 (Q3), U4.15 (D3), U12.15 (B3), U13.28 (D3), U14.2 (D3)
/D4: J6.b11, U1.7 (D4), U2.16 (Q4), U3.16 (Q4), U4.16 (D4), U12.14 (B4), U13.1 (D4), U14.38 (D4)
/D5: J6.b12, U1.9 (D5), U2.17 (Q5), U3.17 (Q5), U4.17 (D5), U12.13 (B5), U13.2 (D5), U14.3 (D5)
/D6: J6.b13, U1.10 (D6), U2.18 (Q6), U3.18 (Q6), U4.18 (D6), U12.12 (B6), U13.3 (D6), U14.37 (D6)
/D7: J6.b14, U1.13 (D7), U2.19 (Q7), U3.19 (Q7), U4.19 (D7), U12.11 (B7), U13.4 (D7), U14.4 (D7)
/IEO_CTC: U13.11 (IEO), U14.6 (IEI)
/IEO_SIO: J6.b26, U14.7 (IEO)
/LED_HALT: LED2.1b (A), U9.6
/LED_RESET: LED1.2b (A), U9.4
/MEM0000: U5.15 (~Y0), U7.2, U7.8
/MEM4000: U5.14 (~Y1), U6.2
/MEM8000: U5.13 (~Y2), U6.9
/MEMAQ: J6.a5, R15.1, U6.13
/MEMC000: U5.12 (~Y3), U6.10
/ROM_BANK_SEL: U4.20 (~CS), U8.9 (Q)
//BUSACK: J6.a24, U1.23 (~BUSACK)
//BUSREQ: J6.a23, R3.2, U1.25 (~BUSRQ)
//CS_BANK: U8.3 (C), U8.11 (C), U11.15 (IO5)
//CS_CTC: U11.17 (I03), U13.16 (~CE)
//CS_DIP: U11.19 (IO1), U12.19 (CE)
//CS_RAM_HIGH: U3.20 (~CS), U7.13
//CS_RAM_LOW: U2.20 (~CS), U6.6
//CS_RAM_LOW_1: U6.1, U7.4
//CS_ROM_LOW: U4.1 (A14), U6.11
//CS_SIO: U11.16 (IO4), U14.35 (~CE)
//HALT: J6.b21, U1.18 (~HALT), U9.5
//INT: J6.b17, R1.2, U1.17 (~NMI), U13.12 (~INT), U14.5 (~INT)
//IOREQ: J6.b25, U1.20 (~IORQ), U11.9 (I9), U13.10 (~IORQ), U14.36 (~IORQ)
//M1: J6.b19, U1.27 (~M1), U13.14 (~M1), U14.8 (~M1)
//MREQ: J6.b24, U1.19 (~MREQ), U5.4 (~LE)
//NMI: J6.b18, R2.2, U1.16 (~INT)
//RAMSEL: U7.3, U8.6 (~Q)
//RD: J6.b22, R13.1, U1.21 (~RD), U2.22 (~OE), U3.22 (~OE), U4.22 (~OE), U11.11 (I10/~OE), U13.6 (~RD), U14.32 (~RD)
//RESET: J6.b15, Q1.1 (C), Q2.1 (C), R9.2, U1.26 (~RESET), U8.1 (~R), U8.13 (~R), U9.3, U13.17 (~RESET), U14.21 (~RESET)
//ROMSEL: U7.9, U8.5 (Q)
//WAIT: J6.b20, R4.2, U1.24 (~WAIT)
//WE_ROM: J3.2, U4.27 (~WE)
//WR: J3.3, J6.b23, R14.1, U1.22 (~WR), U2.27 (~WE), U3.27 (~WE), U11.12 (IO8)
GND: C3.2, C5.1, C7.2, C8.2, C9.2, C10.2, C11.2, C12.2, C13.2, C14.2, C15.2, C16.2, C17.2, C18.2, C19.2, C20.2, J2.6, J4.5, J5.2, J6.a1, J6.a2, J6.a3, J6.a4, J6.b32, Q1.3 (E), Q2.3 (E), R10.2, R11.2, R12.2, RN1.1 (common), SW2.2 (B), U1.29 (GND), U2.14 (GND), U3.14 (GND), U4.14 (GND), U5.3 (A2), U5.5 (~E1), U5.8 (GND), U6.7 (GND), U7.7 (GND), U8.7 (GND), U9.7 (GND), U10.1 (GND), U11.10 (GND), U12.10 (GND), U13.5 (GND), U14.31 (GND), U15.15 (GND), X1.7 (GND), X2.7 (GND)
unnamed: C1.1, U15.1 (C1+)
unnamed: C1.2, U15.3 (C1-)
unnamed: C2.1, U15.4 (C2+)
unnamed: C2.2, U15.5 (C2-)
unnamed: C3.1, R5.2, U10.2 (TR), U10.6 (THR)
unnamed: C4.1, U15.2 (VS+)
unnamed: C5.2, U15.6 (VS-)
unnamed: C6.2, R6.2, SW2.3 (C), U9.1
unnamed: J1.1, U13.23 (CLK/TRG0)
unnamed: J1.2, J1.4, J1.6, J1.8, X2.8 (OUT)
unnamed: J1.3, U13.22 (CLK/TRG1)
unnamed: J1.5, U13.21 (CLK/TRG2)
unnamed: J1.7, U13.20 (CLK/TRG3)
unnamed: J2.2, U14.26 (TXDB)
unnamed: J2.3, U14.28 (RXDB)
unnamed: J4.2, U15.14 (T1OUT)
unnamed: J4.3, U15.13 (R1IN)
unnamed: J4.7, U15.8 (R2IN)
unnamed: J4.8, U15.7 (T2OUT)
unnamed: LED1.1a (K), R10.1
unnamed: LED1.2a (K), R11.1
unnamed: LED2.1a (K), R12.1
unnamed: Q1.2 (B), R7.2
unnamed: Q2.2 (B), R8.2
unnamed: R7.1, U9.2
unnamed: R8.1, U10.3 (Q)
unnamed: RN1.2 (R1), SW1.16, U12.2 (A0)
unnamed: RN1.3 (R2), SW1.15, U12.3 (A1)
unnamed: RN1.4 (R3), SW1.14, U12.4 (A2)
unnamed: RN1.5 (R4), SW1.13, U12.5 (A3)
unnamed: RN1.6 (R5), SW1.12, U12.6 (A4)
unnamed: RN1.7 (R6), SW1.11, U12.7 (A5)
unnamed: RN1.8 (R7), SW1.10, U12.8 (A6)
unnamed: RN1.9 (R8), SW1.9, U12.9 (A7)
unnamed: U6.3, U6.4, U6.5
unnamed: U6.8, U7.11, U7.12
unnamed: U7.1, U7.5, U7.6
unnamed: U6.12, U7.10
unnamed: U13.7 (ZC/TO0), U14.13 (~RXCA), U14.14 (~TXCA)
unnamed: U13.8 (ZC/TO1), U14.27 (~RxTxCB)
unnamed: U14.12 (RXDA), U15.12 (R1OUT)
unnamed: U14.15 (TXDA), U15.11 (T1IN)
unnamed: U14.16 (~DTRA), U15.10 (T2IN)
unnamed: U14.18 (~CTSA), U15.9 (R2OUT)

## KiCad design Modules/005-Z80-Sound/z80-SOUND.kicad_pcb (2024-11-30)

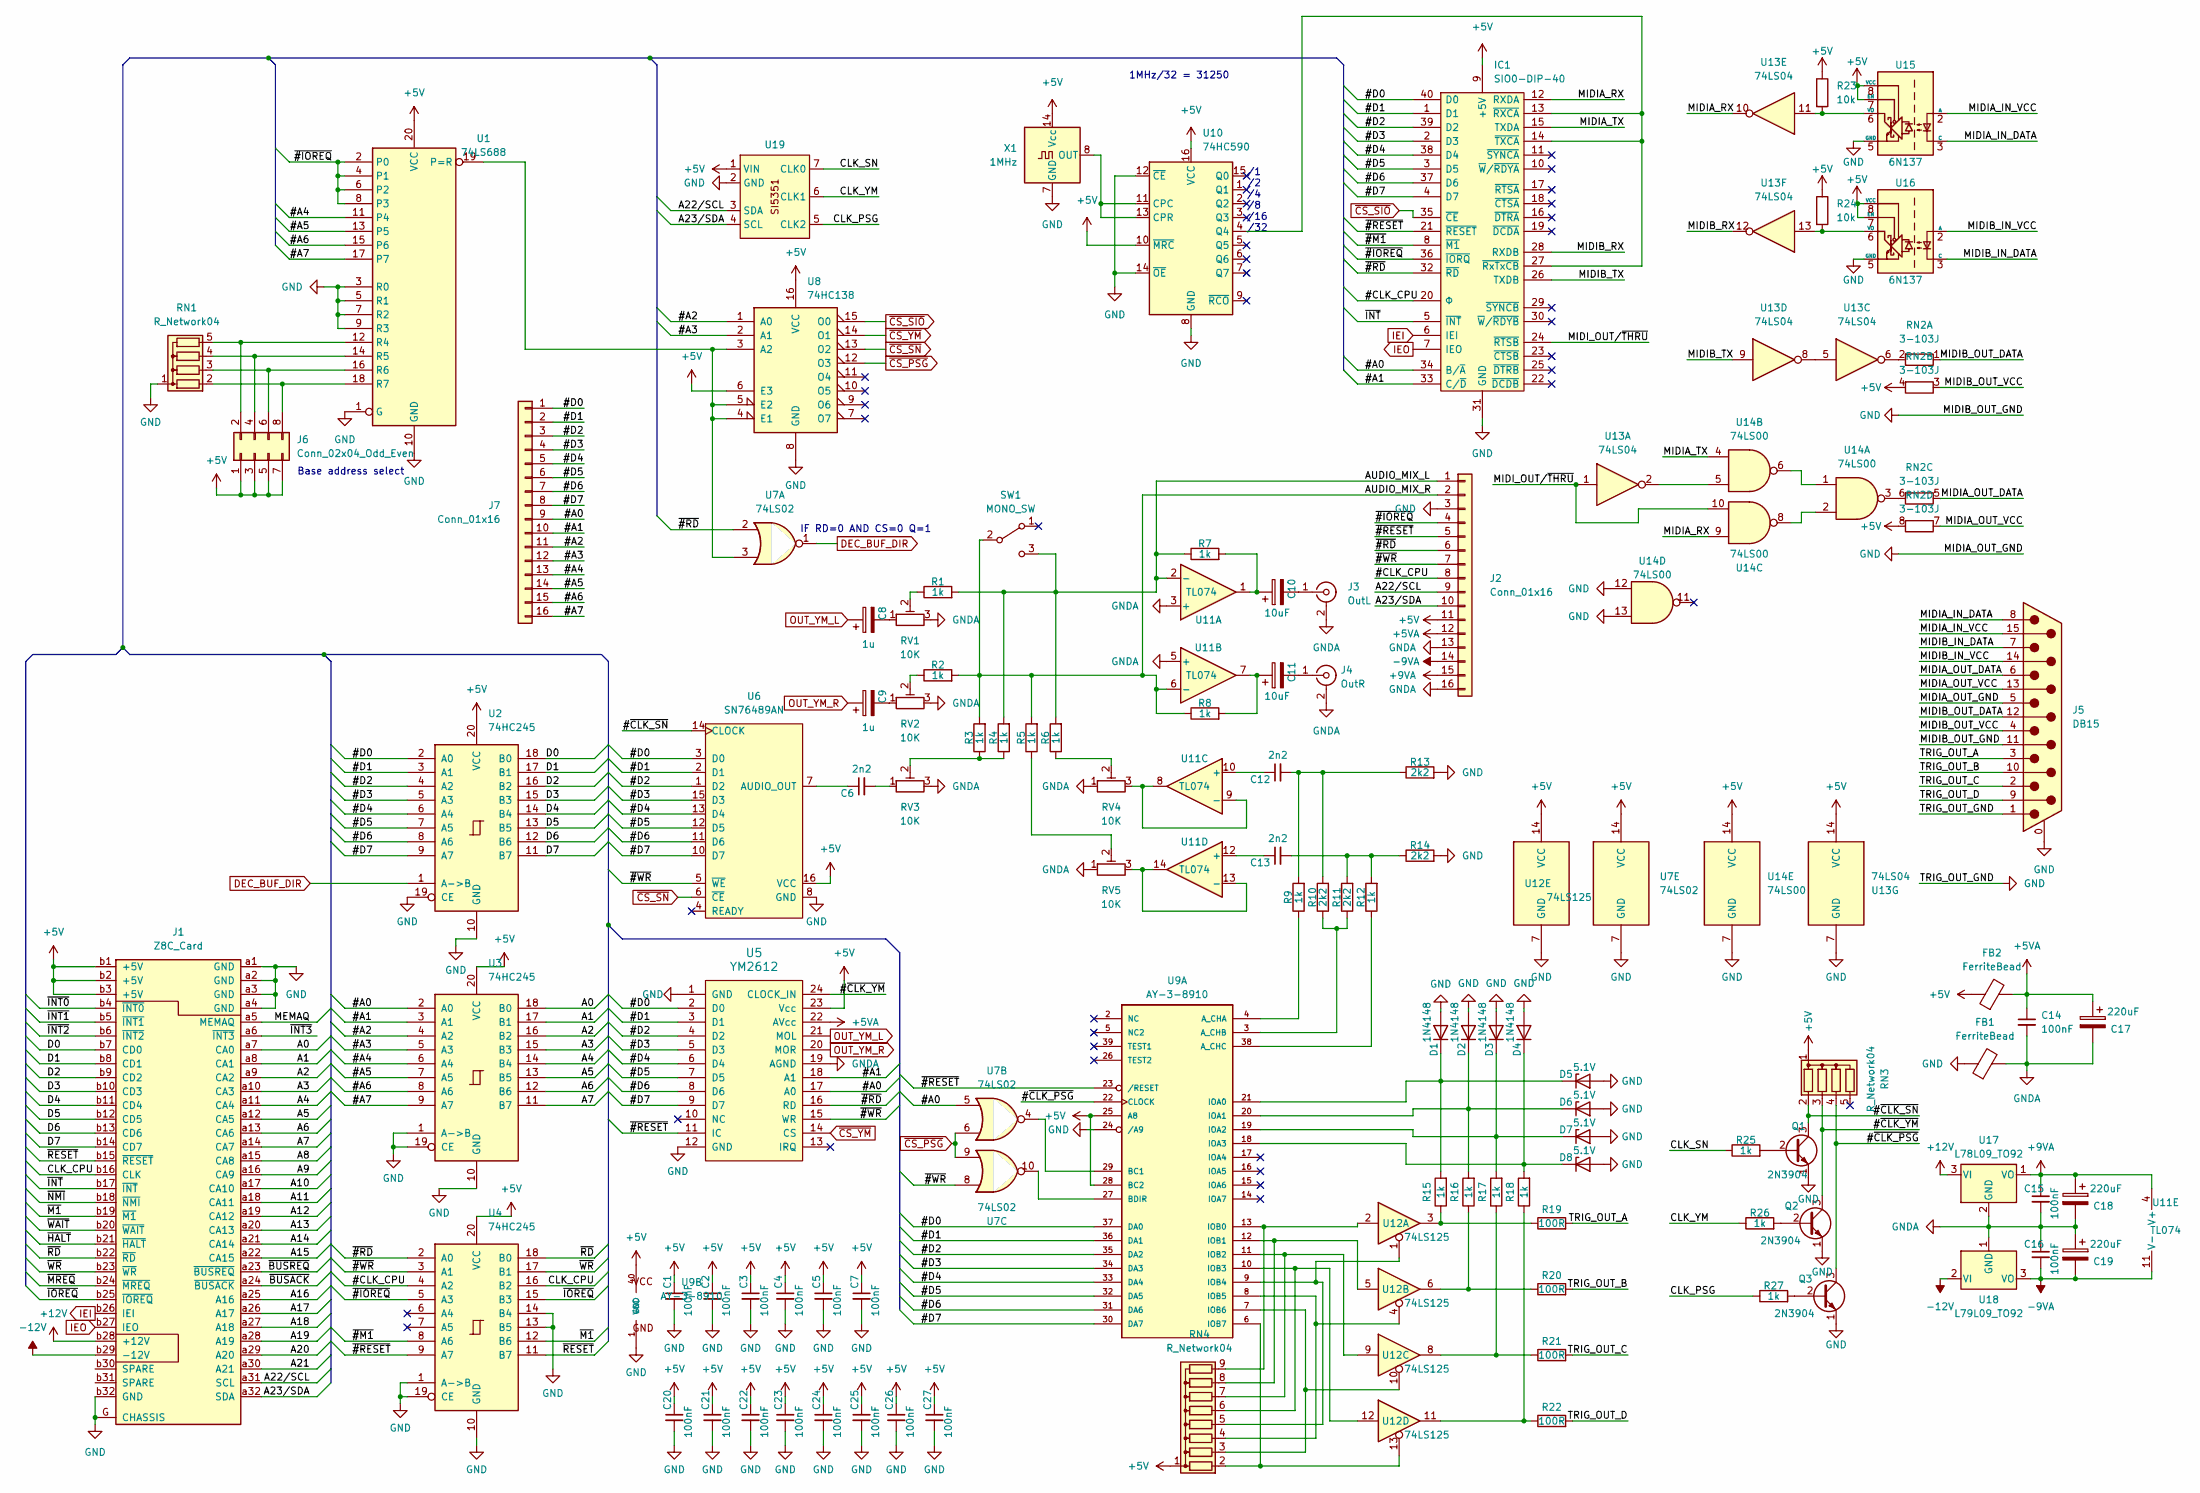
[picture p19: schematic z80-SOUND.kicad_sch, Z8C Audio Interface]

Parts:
C1, C2, C3, C4, C5, C7, C14, C15, C16, C20, C21, C22, C23, C24, C25, C26, C27: 100nF; C_Rect_L7.0mm_W2.0mm_P5.00mm
C6, C12, C13: 2n2; C_Rect_L7.0mm_W2.0mm_P5.00mm
C8, C9: 1u; CP_Radial_D6.3mm_P2.50mm
C10, C11: 10uF; CP_Radial_D6.3mm_P2.50mm
C17, C18, C19: 220uF; CP_Radial_D8.0mm_P3.50mm
D1, D2, D3, D4: 1N4148; D_DO-35_SOD27_P7.62mm_Horizontal
D5, D6, D7, D8: 5.1V; D_DO-34_SOD68_P7.62mm_Horizontal
FB1, FB2: FerriteBead; R_Axial_DIN0414_L11.9mm_D4.5mm_P15.24mm_Horizontal
IC1: SIO0-DIP-40; DIP-40_W15.24mm_Socket; Manufacturer_Part_Number Z84C4206PEG; Mouser Part Number 692-Z84C4206PEG
J1: Z8C_Card; Z8C Card
J2, J7: Conn_01x16; PinSocket_1x16_P2.54mm_Vertical
J3: OutL; RCA_Reichelt
J4: OutR; RCA_Reichelt
J5: DB15; DSUB-15_Female_Horizontal_P2.77x2.84mm_EdgePinOffset9.90mm_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
J6: Conn_02x04_Odd_Even; PinHeader_2x04_P2.54mm_Vertical
Q1, Q2, Q3: 2N3904; TO-92_Inline
R1, R2, R3, R4, R5, R6, R7, R8, R9, R12, R15, R16, R17, R18, R25, R26, R27: 1k; R_Axial_DIN0204_L3.6mm_D1.6mm_P7.62mm_Horizontal
R10, R11, R13, R14: 2k2; R_Axial_DIN0204_L3.6mm_D1.6mm_P7.62mm_Horizontal
R19, R20, R21, R22: 100R; R_Axial_DIN0204_L3.6mm_D1.6mm_P7.62mm_Horizontal
R23, R24: 10k; R_Axial_DIN0204_L3.6mm_D1.6mm_P7.62mm_Horizontal
RN1, RN3: R_Network04; R_Array_SIP5
RN2: 3-103J; R_Array_SIP8
RN4: R_Network04; R_Array_SIP9
RV1, RV2, RV3, RV4, RV5: 10K; Potentiometer_Bourns_3299W_Vertical
SW1: MONO_SW; DPDT_Vertical
U1: 74LS688; DIP-20_W7.62mm_Socket_LongPads
U2, U3, U4: 74HC245; DIP-20_W7.62mm_Socket_LongPads
U5: YM2612; DIP-24_W15.24mm_Socket
U6: SN76489AN; DIP-16_W7.62mm_Socket
U7: 74LS02; DIP-14_W7.62mm_Socket
U8: 74HC138; DIP-16_W7.62mm_Socket_LongPads
U9: AY-3-8910; DIP-40_W15.24mm_Socket
U10: 74HC590; DIP-16_W7.62mm_Socket_LongPads
U11: TL074; DIP-14_W7.62mm_Socket
U12: 74LS125; DIP-14_W7.62mm_Socket
U13: 74LS04; DIP-14_W7.62mm_Socket
U14: 74LS00; DIP-14_W7.62mm_Socket
U15, U16: 6N137; DIP-8_W7.62mm
U17: L78L09_TO92; TO-92_Inline
U18: L79L09_TO92; TO-92_Inline
U19: PinSocket_1x07_P2.54mm_Vertical
X1: 1MHz; Oscillator_DIP-14

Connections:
+5V: C1.1, C2.1, C3.1, C4.1, C5.1, C7.1, C20.1, C21.1, C22.1, C23.1, C24.1, C25.1, C26.1, C27.1, FB2.1, IC1.9 (+5V), J1.b1 (+5V), J1.b2 (+5V), J1.b3 (+5V), J2.11, J6.1, J6.3, J6.5, J6.7, R23.1, R24.1, RN2.4 (R2.2), RN2.8 (R4.2), RN3.1 (common), RN4.1 (common), U1.20 (VCC), U2.20 (VCC), U3.20 (VCC), U4.20 (VCC), U5.23 (Vcc), U6.16 (VCC), U7.14 (VCC), U8.6 (E3), U8.16 (VCC), U9.25 (A8), U9.28 (BC2), U9.40 (VCC), U10.10 (~MRC), U10.16 (VCC), U12.14 (VCC), U13.14 (VCC), U14.14 (VCC), U15.7 (EN), U15.8 (VCC), U16.7 (EN), U16.8 (VCC), U19.1 (VIN), X1.14 (Vcc)
+5VA: C14.1, C17.1, FB2.2, J2.12, U5.22 (AVcc)
+9VA: C15.1, C18.1, J2.15, U11.4 (V+), U17.1 (VO)
+12V: J1.b28 (+12V), U17.3 (VI)
-9VA: C16.2, C19.2, J2.14, U11.11 (V-), U18.3 (VO)
-12V: J1.b29 (-12V), U18.2 (VI)
/#A0: IC1.34 (B/~A), J7.9, U3.2 (A0), U5.17 (A0), U7.5
/#A1: IC1.33 (C/~D), J7.10, U3.3 (A1), U5.18 (A1)
/#A2: J7.11, U3.4 (A2), U8.1 (A0)
/#A3: J7.12, U3.5 (A3), U8.2 (A1)
/#A4: J7.13, U1.11 (P4), U3.6 (A4)
/#A5: J7.14, U1.13 (P5), U3.7 (A5)
/#A6: J7.15, U1.15 (P6), U3.8 (A6)
/#A7: J7.16, U1.17 (P7), U3.9 (A7)
/#CLK_CPU: IC1.20 (Φ), J2.8, U4.4 (A2)
/#D0: IC1.40 (D0), J7.1, U2.2 (A0), U5.2 (D0), U6.3 (D0), U9.37 (DA0)
/#D1: IC1.1 (D1), J7.2, U2.3 (A1), U5.3 (D1), U6.2 (D1), U9.36 (DA1)
/#D2: IC1.39 (D2), J7.3, U2.4 (A2), U5.4 (D2), U6.1 (D2), U9.35 (DA2)
/#D3: IC1.2 (D3), J7.4, U2.5 (A3), U5.5 (D3), U6.15 (D3), U9.34 (DA3)
/#D4: IC1.38 (D4), J7.5, U2.6 (A4), U5.6 (D4), U6.13 (D4), U9.33 (DA4)
/#D5: IC1.3 (D5), J7.6, U2.7 (A5), U5.7 (D5), U6.12 (D5), U9.32 (DA5)
/#D6: IC1.37 (D6), J7.7, U2.8 (A6), U5.8 (D6), U6.11 (D6), U9.31 (DA6)
/#D7: IC1.4 (D7), J7.8, U2.9 (A7), U5.9 (D7), U6.10 (D7), U9.30 (DA7)
/#~CLK_PSG: Q3.3 (C), RN3.4 (R3), U9.22 (CLOCK)
/#~CLK_SN: Q1.3 (C), RN3.2 (R1), U6.14 (CLOCK)
/#~CLK_YM: Q2.3 (C), RN3.3 (R2), U5.24 (CLOCK_IN)
/A0: J1.a7 (CA0), U3.18 (B0)
/A1: J1.a8 (CA1), U3.17 (B1)
/A2: J1.a9 (CA2), U3.16 (B2)
/A3: J1.a10 (CA3), U3.15 (B3)
/A4: J1.a11 (CA4), U3.14 (B4)
/A5: J1.a12 (CA5), U3.13 (B5)
/A6: J1.a13 (CA6), U3.12 (B6)
/A7: J1.a14 (CA7), U3.11 (B7)
/A8: J1.a15 (CA8)
/A9: J1.a16 (CA9)
/A10: J1.a17 (CA10)
/A11: J1.a18 (CA11)
/A12: J1.a19 (CA12)
/A13: J1.a20 (CA13)
/A14: J1.a21 (CA14)
/A15: J1.a22 (CA15)
/A16: J1.a25 (A16)
/A17: J1.a26 (A17)
/A18: J1.a27 (A18)
/A19: J1.a28 (A19)
/A20: J1.a29 (A20)
/A21: J1.a30 (A21)
/A22/SCL: J1.a31 (SCL), J2.9, U19.3 (SDA)
/A23/SDA: J1.a32 (SDA), J2.10, U19.4 (SCL)
/AUDIO_MIX_L: J2.1, R1.2, R4.2, R6.2, R7.1, SW1.3 (C), U11.2 (-)
/AUDIO_MIX_R: J2.2, R2.2, R3.2, R5.2, R8.1, SW1.2 (B), U11.6 (-)
/CLK_CPU: J1.b16 (CLK), U4.16 (B2)
/CLK_PSG: R27.1, U19.5 (CLK2)
/CLK_SN: R25.1, U19.7 (CLK0)
/CLK_YM: R26.1, U19.6 (CLK1)
/D0: J1.b7 (CD0), U2.18 (B0)
/D1: J1.b8 (CD1), U2.17 (B1)
/D2: J1.b9 (CD2), U2.16 (B2)
/D3: J1.b10 (CD3), U2.15 (B3)
/D4: J1.b11 (CD4), U2.14 (B4)
/D5: J1.b12 (CD5), U2.13 (B5)
/D6: J1.b13 (CD6), U2.12 (B6)
/D7: J1.b14 (CD7), U2.11 (B7)
/MEMAQ: J1.a5 (MEMAQ)
/MIDIA_IN_DATA: J5.8, U15.3 (C)
/MIDIA_IN_VCC: J5.15, U15.2 (A)
/MIDIA_OUT_DATA: J5.6, RN2.5 (R3.1)
/MIDIA_OUT_VCC: J5.13, RN2.7 (R4.1)
/MIDIA_RX: IC1.12 (RXDA), U13.10, U14.9
/MIDIA_TX: IC1.15 (TXDA), U14.4
/MIDIB_IN_DATA: J5.7, U16.3 (C)
/MIDIB_IN_VCC: J5.14, U16.2 (A)
/MIDIB_OUT_DATA: J5.12, RN2.1 (R1.1)
/MIDIB_OUT_VCC: J5.4, RN2.3 (R2.1)
/MIDIB_RX: IC1.28 (RXDB), U13.12
/MIDIB_TX: IC1.26 (TXDB), U13.9
/MIDI_OUT/~THRU: IC1.24 (~RTSB), U13.1, U14.10
/TRIG_OUT_A: J5.3, R19.2
/TRIG_OUT_B: J5.10, R20.2
/TRIG_OUT_C: J5.2, R21.2
/TRIG_OUT_D: J5.9, R22.2
/~#IOREQ: IC1.36 (~IORQ), J2.4, U1.2 (P0), U1.4 (P1), U1.6 (P2), U1.8 (P3), U4.5 (A3)
/~#M1: IC1.8 (~M1), U4.8 (A6)
/~#RD: IC1.32 (~RD), J2.6, U4.2 (A0), U5.16 (RD), U7.2
/~#RESET: IC1.21 (~RESET), J2.5, U4.9 (A7), U5.11 (IC), U9.23 (/RESET)
/~#WR: J2.7, U4.3 (A1), U5.15 (WR), U6.5 (~WE), U7.8
/~BUSACK: J1.a24 (~BUSACK)
/~BUSREQ: J1.a23 (~BUSREQ)
/~HALT: J1.b21 (~HALT)
/~INT0: J1.b4 (~INT0)
/~INT1: J1.b5 (~INT1)
/~INT2: J1.b6 (~INT2)
/~INT3: J1.a6 (~INT3)
/~INT: IC1.5 (~INT), J1.b17 (~INT)
/~IOREQ: J1.b25 (~IOREQ), U4.15 (B3)
/~M1: J1.b19 (~M1), U4.12 (B6)
/~MREQ: J1.b24 (~MREQ)
/~NMI: J1.b18 (~NMI)
/~RD: J1.b22 (~RD), U4.18 (B0)
/~RESET: J1.b15 (~RESET), U4.11 (B7)
/~WAIT: J1.b20 (~WAIT)
/~WR: J1.b23 (~WR), U4.17 (B1)
DEC_BUF_DIR: U2.1 (A->B), U7.1
GND: C1.2, C2.2, C3.2, C4.2, C5.2, C7.2, C20.2, C21.2, C22.2, C23.2, C24.2, C25.2, C26.2, C27.2, D1.2 (A), D2.2 (A), D3.2 (A), D4.2 (A), D5.2 (A), D6.2 (A), D7.2 (A), D8.2 (A), FB1.1, IC1.31 (GND), J1.G (CHASSIS), J1.a1 (GND), J1.a2 (GND), J1.a3 (GND), J1.a4 (GND), J1.b32 (GND), J2.3, J5.0 (PAD), J5.1, J5.5, J5.11 (P111), Q1.1 (E), Q2.1 (E), Q3.1 (E), R13.2, R14.2, RN1.1 (common), U1.1 (G), U1.3 (R0), U1.5 (R1), U1.7 (R2), U1.9 (R3), U1.10 (GND), U2.10 (GND), U2.19 (CE), U3.1 (A->B), U3.10 (GND), U3.19 (CE), U4.1 (A->B), U4.10 (GND), U4.13 (B5), U4.14 (B4), U4.19 (CE), U5.1 (GND), U5.12 (GND), U6.8 (GND), U7.7 (GND), U8.8 (GND), U9.1 (GND), U9.24 (/A9), U10.8 (GND), U10.12 (~CE), U10.14 (~OE), U12.7 (GND), U13.7 (GND), U14.7 (GND), U14.12, U14.13, U15.5 (GND), U16.5 (GND), U19.2 (GND), X1.7 (GND)
GNDA: C14.2, C15.2, C16.1, C17.2, C18.2, C19.1, FB1.2, J2.13, J2.16, J3.2 (Ext), J4.2 (Ext), RV1.3, RV2.3, RV3.3, RV4.1, RV5.1, U5.19 (AGND), U11.3 (+), U11.5 (+), U17.2 (GND), U18.1 (GND)
IEI: IC1.6 (IEI), J1.b26 (IEI)
IEO: IC1.7 (IEO), J1.b27 (IEO)
unnamed: C6.2, RV3.1
unnamed: C8.2, RV1.1
unnamed: C9.2, RV2.1
unnamed: C10.1, R7.2, U11.1
unnamed: C11.1, R8.2, U11.7
unnamed: C12.2, R9.2, R10.2, R13.1
unnamed: C13.2, R11.2, R12.2, R14.1
unnamed: D1.1 (K), D5.1 (K), R15.2, U9.21 (IOA0)
unnamed: D2.1 (K), D6.1 (K), R16.2, U9.20 (IOA1)
unnamed: D3.1 (K), D7.1 (K), R17.2, U9.19 (IOA2)
unnamed: D4.1 (K), D8.1 (K), R18.2, U9.18 (IOA3)
unnamed: IC1.13 (~RXCA), IC1.14 (~TXCA), IC1.27 (~RxTxCB), U10.4 (Q4)
unnamed: C10.2, J3.1 (In)
unnamed: C11.2, J4.1 (In)
unnamed: J6.2, RN1.5 (R4), U1.12 (R4)
unnamed: J6.4, RN1.4 (R3), U1.14 (R5)
unnamed: J6.6, RN1.3 (R2), U1.16 (R6)
unnamed: J6.8, RN1.2 (R1), U1.18 (R7)
unnamed: Q1.2 (B), R25.2
unnamed: Q2.2 (B), R26.2
unnamed: Q3.2 (B), R27.2
unnamed: R1.1, RV1.2
unnamed: R2.1, RV2.2
unnamed: R3.1, R4.1, RV3.2
unnamed: R5.1, RV5.2
unnamed: R6.1, RV4.2
unnamed: R15.1, R19.1, U12.3
unnamed: R16.1, R20.1, U12.6
unnamed: R17.1, R21.1, U12.8
unnamed: R18.1, R22.1, U12.11
unnamed: RN2.2 (R1.2), U13.6
unnamed: RN2.6 (R3.2), U14.3
unnamed: RN4.2 (R1), U9.6 (IOB7), U12.13
unnamed: RN4.3 (R2), U9.7 (IOB6), U12.10
unnamed: RN4.4 (R3), U9.8 (IOB5), U12.4
unnamed: RN4.5 (R4), U9.9 (IOB4), U12.1
unnamed: RN4.6 (R5), U9.10 (IOB3), U12.12
unnamed: RN4.7 (R6), U9.11 (IOB2), U12.9
unnamed: RN4.8 (R7), U9.12 (IOB1), U12.5
unnamed: RN4.9 (R8), U9.13 (IOB0), U12.2
unnamed: U1.19 (P=R), U7.3, U8.3 (A2), U8.4 (E1), U8.5 (E2)
unnamed: C6.1, U6.7 (AUDIO_OUT)
unnamed: R9.1, U9.4 (A_CHA)
unnamed: R10.1, R11.1, U9.3 (A_CHB)
unnamed: R12.1, U9.38 (A_CHC)
unnamed: U7.4, U9.29 (BC1)
unnamed: U7.10, U9.27 (BDIR)
unnamed: U10.11 (CPC), U10.13 (CPR), X1.8 (OUT)
unnamed: C12.1, U11.10 (+)
unnamed: RV4.3, U11.8, U11.9 (-)
unnamed: C13.1, U11.12 (+)
unnamed: RV5.3, U11.13 (-), U11.14
unnamed: U13.2, U14.5
unnamed: U13.5, U13.8
unnamed: U14.1, U14.6
unnamed: U14.2, U14.8
unnamed: R23.2, U13.11, U15.6 (VO)
unnamed: R24.2, U13.13, U16.6 (VO)
OUT_YM_L: C8.1, U5.21 (MOL)
OUT_YM_R: C9.1, U5.20 (MOR)
~CS_PSG: U7.6, U7.9, U8.12 (O3)
~CS_SIO: IC1.35 (~CE), U8.15 (O0)
~CS_SN: U6.6 (~CE), U8.13 (O2)
~CS_YM: U5.14 (CS), U8.14 (O1)

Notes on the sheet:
/1 /2 /4 /8 /16 /32
Base address select
IF RD=0 AND CS=0 Q=1
1MHz/32 = 31250

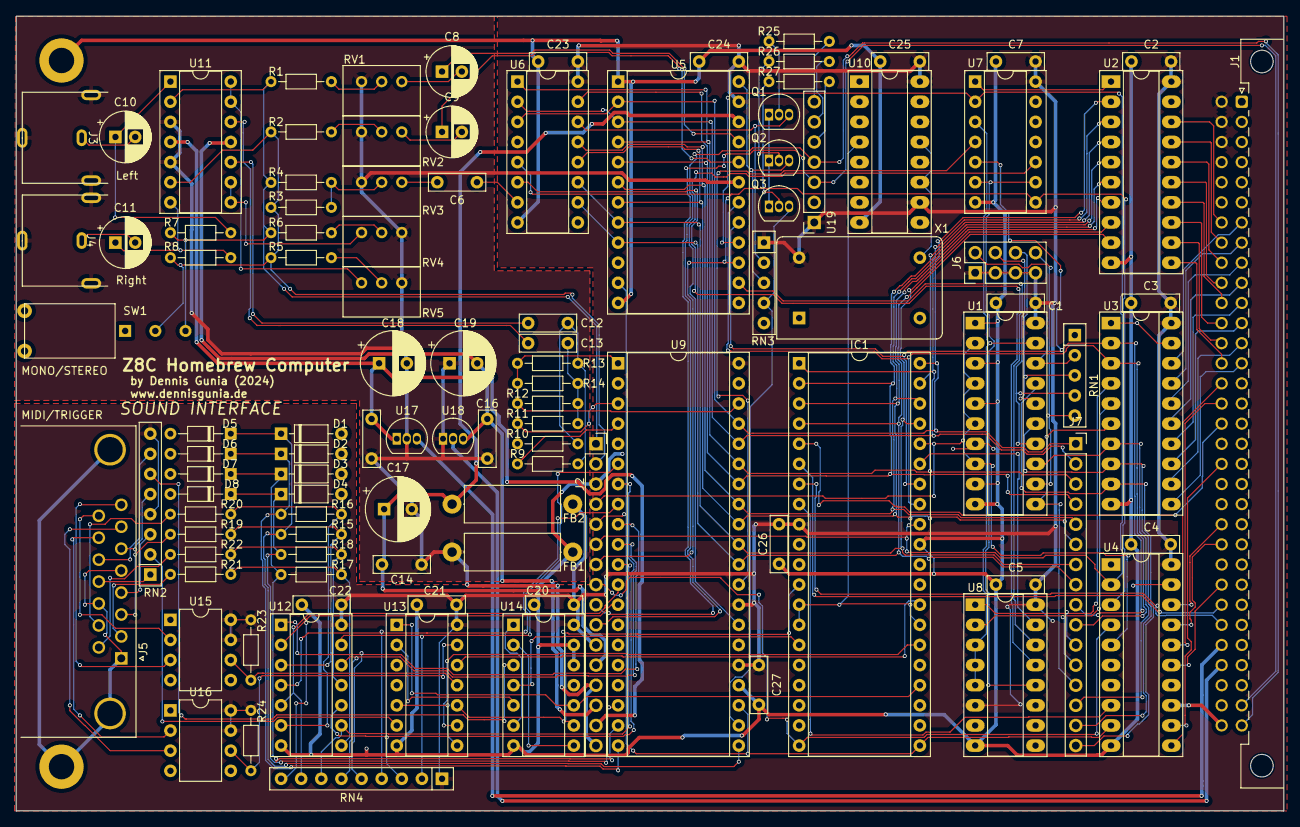
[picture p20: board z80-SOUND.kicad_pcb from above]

Board: 2 copper layers, 160.0 x 100.3 mm, 105 parts (0 on the bottom side), 147 nets.

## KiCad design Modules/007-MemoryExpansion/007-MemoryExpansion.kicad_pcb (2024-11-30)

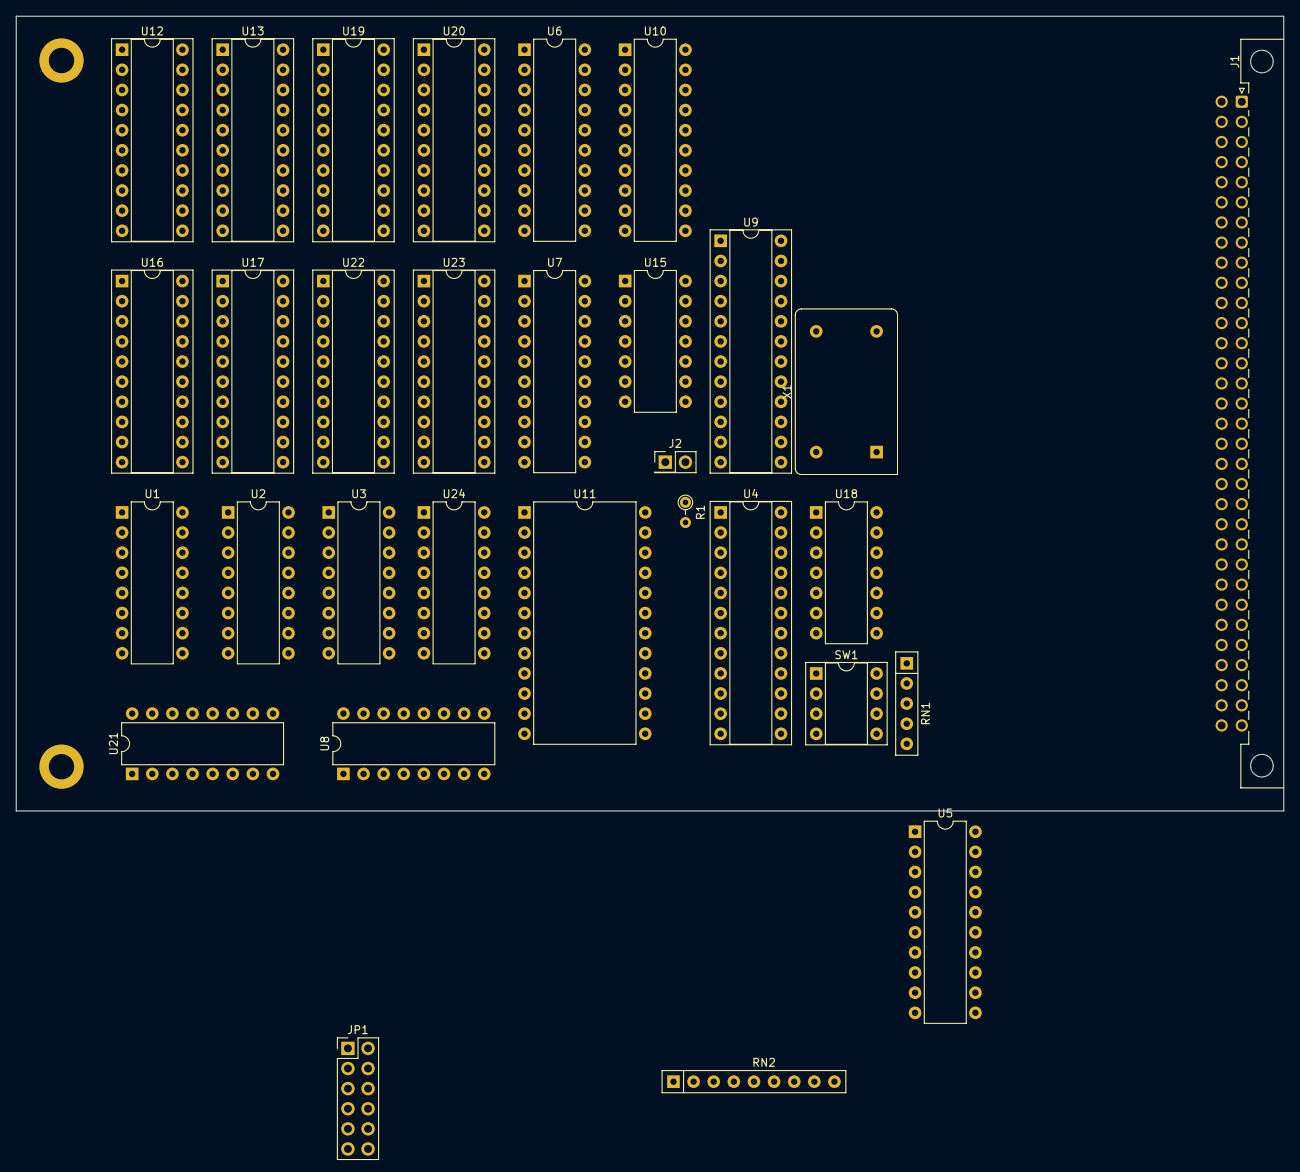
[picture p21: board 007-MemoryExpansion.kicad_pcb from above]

Board: 2 copper layers, 160.0 x 100.3 mm, 31 parts (0 on the bottom side), 98 nets, no tracks yet.

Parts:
J1: Z8C_Ca#RD; Z8C Card
J2: ENA19; PinHeader_2x01_P2.54mm_Vertical
JP1: Conn_02x06_Odd_Even; PinHeader_2x06_P2.54mm_Vertical
R1: 4.7k; R_Axial_DIN0204_L3.6mm_D1.6mm_P2.54mm_Vertical
RN1: 4k7; R_Array_SIP5
RN2: R_Network08; R_Array_SIP9
SW1: SW_DIP_x04; DIP-8_W7.62mm_Socket
U1, U2, U3, U8: 74LS157; DIP-16_W7.62mm
U4, U9: DIP-24_W7.62mm_Socket
U5: 74LS688; DIP-20_W7.62mm
U6, U10: 74LS245; DIP-20_W7.62mm
U7: 74LS374; DIP-20_W7.62mm
U11: DIP-24_W15.24mm
U12, U13, U16, U17, U19, U20, U22, U23: DIP-20_W7.62mm_Socket
U15: 74LS74; DIP-14_W7.62mm
U18: 74LS125; DIP-14_W7.62mm
U21: 74LS138; DIP-16_W7.62mm
U24: 74LS175; DIP-16_W7.62mm
X1: 40MHz; Oscillator_DIP-14

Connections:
+5V: J1.b1 (+5V), J1.b2 (+5V), J1.b3 (+5V), J2.1, JP1.1, JP1.3, JP1.5, JP1.7, JP1.9, JP1.11, SW1.1, SW1.2, SW1.3, SW1.4, U4.24 (VCC), U5.20 (VCC), U6.20 (VCC), U7.20 (VCC), U8.16 (VCC), U9.24 (VCC), U10.20 (VCC), U11.24 (Vcc), U12.20 (VSS), U13.20 (VSS), U16.20 (VSS), U17.20 (VSS), U19.20 (VSS), U20.20 (VSS), U21.6 (E3), U21.16 (VCC), U22.20 (VSS), U23.20 (VSS), U24.1 (~Mr), U24.16 (VCC), X1.14 (Vcc)
/#CA0: U1.2 (I0a), U4.9 (I9)
/#CA1: U1.5 (I0b), U4.11 (I10)
/#CA2: U1.11 (I0c), U5.6 (P2)
/#CA3: U1.14 (I0d), U5.8 (P3)
/#CA4: U2.2 (I0a), U5.11 (P4)
/#CA5: U2.5 (I0b), U5.13 (P5)
/#CA6: U2.11 (I0c), U5.15 (P6)
/#CA7: U2.14 (I0d), U5.17 (P7)
/#CA15: U4.13 (I13/~OE), U8.13 (I1d)
/#CD0: U6.2 (A0), U7.3 (D0), U10.2 (A0), U18.3, U24.4 (D0)
/#CD1: U6.3 (A1), U7.4 (D1), U10.3 (A1), U24.5 (D1)
/#CD2: U6.4 (A2), U7.7 (D2), U10.4 (A2), U24.12 (D2)
/#CD3: U6.5 (A3), U7.8 (D3), U10.5 (A3), U24.13 (D3)
/#CD4: U6.6 (A4), U7.13 (D4), U10.6 (A4)
/#CD5: U6.7 (A5), U7.14 (D5), U10.7 (A5)
/#CD6: U6.8 (A6), U7.17 (D6), U10.8 (A6)
/#CD7: U6.9 (A7), U7.18 (D7), U10.9 (A7)
/JENA19: J2.2, R1.1, U18.2
/MBA12: U1.13 (I1d), U10.18 (B0), U11.9 (D0)
/MBA13: U2.3 (I1a), U10.17 (B1), U11.10 (D1)
/MBA14: U2.6 (I1b), U10.16 (B2), U11.11 (D2)
/MBA15: U2.10 (I1c), U10.15 (B3), U11.13 (D3)
/MBA16: U2.13 (I1d), U10.14 (B4), U11.14 (D4)
/MBA17: U3.3 (I1a), U10.13 (B5), U11.15 (D5)
/MBA18: U10.12 (B6), U11.16 (D6), U21.1 (A0)
/MBPROT: U4.16 (IO16), U10.11 (B7), U11.17 (D7)
/MDA0: U6.18 (B0), U12.1 (DQ0), U13.1 (DQ0), U19.1 (DQ0), U20.1 (DQ0)
/MDA1: U6.17 (B1), U12.2 (DQ1), U13.2 (DQ1), U19.2 (DQ1), U20.2 (DQ1)
/MDA2: U6.16 (B2), U12.18 (DQ2), U13.18 (DQ2), U19.18 (DQ2), U20.18 (DQ2)
/MDA3: U6.15 (B3), U12.19 (DQ3), U13.19 (DQ3), U19.19 (DQ3), U20.19 (DQ3)
/MDA4: U6.14 (B4), U16.1 (DQ0), U17.1 (DQ0), U22.1 (DQ0), U23.1 (DQ0)
/MDA5: U6.13 (B5), U16.2 (DQ1), U17.2 (DQ1), U22.2 (DQ1), U23.2 (DQ1)
/MDA6: U6.12 (B6), U16.18 (DQ2), U17.18 (DQ2), U22.18 (DQ2), U23.18 (DQ2)
/MDA7: U6.11 (B7), U16.19 (DQ3), U17.19 (DQ3), U22.19 (DQ3), U23.19 (DQ3)
/MMA0: U1.4 (Za), U12.6 (A0), U13.6 (A0), U16.6 (A0), U17.6 (A0), U19.6 (A0), U20.6 (A0), U22.6 (A0), U23.6 (A0)
/MMA1: U1.7 (Zb), U12.7 (A1), U13.7 (A1), U16.7 (A1), U17.7 (A1), U19.7 (A1), U20.7 (A1), U22.7 (A1), U23.7 (A1)
/MMA2: U1.9 (Zc), U12.8 (A2), U13.8 (A2), U16.8 (A2), U17.8 (A2), U19.8 (A2), U20.8 (A2), U22.8 (A2), U23.8 (A2)
/MMA3: U1.12 (Zd), U12.9 (A3), U13.9 (A3), U16.9 (A3), U17.9 (A3), U19.9 (A3), U20.9 (A3), U22.9 (A3), U23.9 (A3)
/MMA4: U2.4 (Za), U12.11 (A4), U13.11 (A4), U16.11 (A4), U17.11 (A4), U19.11 (A4), U20.11 (A4), U22.11 (A4), U23.11 (A4)
/MMA5: U2.7 (Zb), U12.12 (A5), U13.12 (A5), U16.12 (A5), U17.12 (A5), U19.12 (A5), U20.12 (A5), U22.12 (A5), U23.12 (A5)
/MMA6: U2.9 (Zc), U12.13 (A6), U13.13 (A6), U16.13 (A6), U17.13 (A6), U19.13 (A6), U20.13 (A6), U22.13 (A6), U23.13 (A6)
/MMA7: U2.12 (Zd), U12.14 (A7), U13.14 (A7), U16.14 (A7), U17.14 (A7), U19.14 (A7), U20.14 (A7), U22.14 (A7), U23.14 (A7)
/MMA8: U3.4 (Za), U12.15 (A8), U13.15 (A8), U16.15 (A8), U17.15 (A8), U19.15 (A8), U20.15 (A8), U22.15 (A8), U23.15 (A8)
/MPROTEN: U4.15 (IO15), U7.19 (O7)
/MUXEN: U1.15 (E), U2.15 (E), U3.15 (E), U9.17 (IO17)
/REGBNK0: U7.2 (O0), U11.4 (A4)
/REGBNK1: U7.5 (O1), U11.3 (A5)
/REGBNK2: U7.6 (O2), U11.2 (A6)
/REGBNK3: U7.9 (O3), U11.1 (A7)
/REGBNK4: U7.12 (O4), U11.23 (A8)
/REGBNK5: U7.15 (O5), U11.22 (A9)
/REGBNK6: U7.16 (O6), U11.19 (A10)
/REGMAP0: U8.2 (I0a), U24.2 (Q0)
/REGMAP1: U8.5 (I0b), U24.7 (Q1)
/REGMAP2: U8.11 (I0c), U24.10 (Q2)
/REGMAP3: U8.14 (I0d), U24.15 (Q3)
/WRPROT: U4.19 (IO19), U7.11 (Cp)
/WRREG: U4.22 (IO22), U24.9 (Cp)
/~#DRAMREQ: U4.23 (IO23), U6.19 (CE), U9.6 (I6), U21.4 (E1)
/~#MREQ: U4.6 (I6), U9.7 (I7)
/~#RD: U4.7 (I7), U9.8 (I8)
/~#WR: U4.8 (I8), U6.1 (A->B), U9.9 (I9), U10.1 (A->B), U21.3 (A2)
/~CARDSEL: U4.5 (I5), U5.19 (P=R)
/~CSMAP: U4.20 (IO20), U8.1 (S), U10.19 (CE)
/~DBANK1_RD: U12.16 (~OE), U16.16 (~OE), U21.11 (O4)
/~DBANK1_WR: U12.3 (~WE), U16.3 (~WE), U21.15 (O0)
/~DBANK2_RD: U13.16 (~OE), U17.16 (~OE), U21.10 (O5)
/~DBANK2_WR: U13.3 (~WE), U17.3 (~WE), U21.14 (O1)
/~DBANK3_RD: U19.16 (~OE), U21.9 (O6), U22.16 (~OE)
/~DBANK3_WR: U19.3 (~WE), U21.13 (O2), U22.3 (~WE)
/~DBANK4_RD: U20.16 (~OE), U21.7 (O7), U23.16 (~OE)
/~DBANK4_WR: U20.3 (~WE), U21.12 (O3), U23.3 (~WE)
/~ENRAMDEC: U9.23 (IO23), U21.5 (E2)
/~MCAS: U9.15 (IO15), U12.17 (~CAS), U13.17 (~CAS), U16.17 (~CAS), U17.17 (~CAS), U19.17 (~CAS), U20.17 (~CAS), U22.17 (~CAS), U23.17 (~CAS)
/~MMUX: U1.1 (S), U2.1 (S), U3.1 (S), U9.16 (IO16)
/~MRAS: U9.14 (IO14), U12.4 (~RAS), U13.4 (~RAS), U16.4 (~RAS), U17.4 (~RAS), U19.4 (~RAS), U20.4 (~RAS), U22.4 (~RAS), U23.4 (~RAS)
/~NMIGAT: U4.14 (IO14), U18.4
/~RDPROT: U4.18 (IO18), U18.1
/~WRMAP: U4.21 (IO21), U11.21 (R/~W)
GND: J1.a1 (GND), J1.a2 (GND), J1.a3 (GND), J1.a4 (GND), J1.b32 (GND), R1.2, RN1.1 (common), RN2.1 (common), U4.12 (GND), U5.1 (G), U5.2 (P0), U5.10 (GND), U6.10 (GND), U7.1 (OE), U7.10 (GND), U8.8 (GND), U8.15 (E), U9.12 (GND), U9.13 (I13/~OE), U10.10 (GND), U11.12 (GND), U11.18 (~CS), U11.20 (~OE), U12.10 (VCC), U13.10 (VCC), U16.10 (VCC), U17.10 (VCC), U18.5, U19.10 (VCC), U20.10 (VCC), U21.8 (GND), U22.10 (VCC), U23.10 (VCC), U24.8 (GND), X1.7 (GND)
unnamed: JP1.2, RN2.7 (R6), U5.7 (R2)
unnamed: JP1.4, RN2.6 (R5), U5.9 (R3)
unnamed: JP1.6, RN2.5 (R4), U5.12 (R4)
unnamed: JP1.8, RN2.4 (R3), U5.14 (R5)
unnamed: JP1.10, RN2.3 (R2), U5.16 (R6)
unnamed: JP1.12, RN2.2 (R1), U5.18 (R7)
unnamed: RN1.2 (R1), SW1.8, U4.4 (I4)
unnamed: RN1.3 (R2), SW1.7, U4.3 (I3)
unnamed: RN1.4 (R3), SW1.6, U4.2 (I2)
unnamed: RN1.5 (R4), SW1.5, U4.1 (I1/CLK)
unnamed: RN2.8 (R7), U5.5 (R1)
unnamed: RN2.9 (R8), U5.3 (R0)
unnamed: U9.1 (I1/CLK), X1.8 (OUT)
unnamed: U8.4 (Za), U11.8 (A0)
unnamed: U8.7 (Zb), U11.7 (A1)
unnamed: U8.9 (Zc), U11.6 (A2)
unnamed: U8.12 (Zd), U11.5 (A3)

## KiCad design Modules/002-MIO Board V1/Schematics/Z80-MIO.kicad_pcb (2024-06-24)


Board: 2 copper layers, 160.0 x 100.3 mm, 71 parts (0 on the bottom side), 120 nets.

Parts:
BT1: 3V; Battery_Holder_Coin_2032_BS-7
C1, C2, C3, C4: 47pF; C_Disc_D3.0mm_W2.0mm_P2.50mm
C5, C6, C7, C8, C9, C10, C11, C12, C13, C14, C15, C16: 100nF; C_Disc_D4.3mm_W1.9mm_P5.00mm
D1, D2, D3, D4, D5, D6, D7, D8: 5.1V; D_DO-34_SOD68_P7.62mm_Horizontal
J1: Conn_02x05_Odd_Even; PinHeader_2x05_P2.54mm_Vertical
J2: Conn_02x02_Top_Bottom; PinHeader_2x03_P2.54mm_Vertical
J3: Conn_02x02_Top_Bottom; PinHeader_2x02_P2.54mm_Vertical
J4: Conn_02x07_Odd_Even; IDC-Header_2x07_P2.54mm_Latch_Horizontal
J5, J6: Mini-DIN-6; PS2
J7: Jumper_2_Bridged; PinHeader_1x02_P2.54mm_Vertical
J8, J9: Conn_02x04_Odd_Even; PinHeader_2x04_P2.54mm_Vertical
J10: Z8C_Card; Z8C Card
LS1: Speaker; Piezo_Transducer_THT_PS1240P02BT
Q1: BC548; TO-92_Inline
R1, R8, R9, R14, R15, R16, R17, R19: 4k7; R_Axial_DIN0204_L3.6mm_D1.6mm_P7.62mm_Horizontal
R2, R18, R20: 10k; R_Axial_DIN0204_L3.6mm_D1.6mm_P7.62mm_Horizontal
R3: 220; R_Axial_DIN0204_L3.6mm_D1.6mm_P7.62mm_Horizontal
R4, R5, R6, R7, R10, R11, R12, R13: 68; R_Axial_DIN0204_L3.6mm_D1.6mm_P7.62mm_Horizontal
RN1: R_Network08; R_Array_SIP9
U1: 74HC688; DIP-20_W7.62mm_LongPads
U2: GAL16V8; DIP-20_W7.62mm_LongPads
U3: 74HC2T45; DIP-20_W7.62mm_LongPads
U4, U5: 74HC245; DIP-20_W7.62mm_LongPads
U6: PIO-DIP-40; DIP-40_W15.24mm
U7: 7406; DIP-14_W7.62mm_Socket
U8: PCF8584; DIP-20_W7.62mm_LongPads
U9: 8048; DIP-40_W15.24mm_LongPads
U10: DS1307+; DIP-8_W7.62mm
U11: 74HC161; DIP-16_W7.62mm_LongPads
U12: Am9511A; DIP-24_W15.24mm_LongPads
Y1: 32.768 kHz; Crystal_AT310_D3.0mm_L10.0mm_Horizontal

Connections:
+5V: C5.1, C6.1, C7.1, C8.1, C9.1, C10.1, C11.1, C12.1, C13.1, C14.1, C15.1, C16.1, J1.1, J1.3, J1.5, J1.7, J1.9, J4.2, J5.4, J6.4, J10.b1 (+5V), J10.b2 (+5V), J10.b3 (+5V), LS1.1, R1.1, R2.1, R8.1, R9.1, R14.2, R15.2, R16.2, R17.2, R18.1, R19.1, R20.1, U1.20 (VCC), U2.20 (VCC), U3.20 (VCC), U4.20 (VCC), U5.20 (VCC), U6.26 (VCC), U7.14 (VCC), U8.4 (~IACK), U8.20 (VDD), U9.5 (~SS), U9.25 (PROG), U9.26 (VDD), U9.40 (VCC), U10.8 (VCC), U11.7 (CEP), U11.9 (~PE), U11.16 (VCC), U12.2 (VCC)
+12V: J10.b28 (+12V), U12.16 (VDD)
/#A0: U2.4 (I4), U4.2 (A0), U6.6 (B/~A), U8.6 (A0), U9.9 (~PSEN), U12.21 (C/~D)
/#A1: U2.5 (I5), U4.3 (A1), U6.5 (C/~D)
/#A2: U2.6 (I6), U4.4 (A2)
/#A3: U2.7 (I7), U4.5 (A3)
/#A4: U1.11 (P4), U4.6 (A4)
/#A5: U1.13 (P5), U4.7 (A5)
/#A6: U1.15 (P6), U4.8 (A6)
/#A7: U1.17 (P7), U4.9 (A7)
/#CLK_CPU: U5.7 (A5), U6.25 (CLK), U8.1 (CLK), U9.3 (X2), U11.2 (CP)
/#D0: U3.2 (A0), U6.19 (D0), U8.7 (D0), U9.12 (DB.0), U12.8 (D0)
/#D1: U3.3 (A1), U6.20 (D1), U8.8 (D1), U9.13 (DB.1), U12.9 (D1)
/#D2: U3.4 (A2), U6.1 (D2), U8.9 (D2), U9.14 (DB.2), U12.10 (D2)
/#D3: U3.5 (A3), U6.40 (D3), U8.11 (D3), U9.15 (DB.3), U12.11 (D3)
/#D4: U3.6 (A4), U6.39 (D4), U8.12 (D4), U9.16 (DB.4), U12.12 (D4)
/#D5: U3.7 (A5), U6.38 (D5), U8.13 (D5), U9.17 (DB.5), U12.13 (D5)
/#D6: U3.8 (A6), U6.3 (D6), U8.14 (D6), U9.18 (DB.6), U12.14 (D6)
/#D7: U3.9 (A7), U6.2 (D7), U8.15 (D7), U9.19 (DB.7), U12.15 (D7)
/A0: J10.a7 (CA0), U4.18 (B0)
/A1: J10.a8 (CA1), U4.17 (B1)
/A2: J10.a9 (CA2), U4.16 (B2)
/A3: J10.a10 (CA3), U4.15 (B3)
/A4: J10.a11 (CA4), U4.14 (B4)
/A5: J10.a12 (CA5), U4.13 (B5)
/A6: J10.a13 (CA6), U4.12 (B6)
/A7: J10.a14 (CA7), U4.11 (B7)
/A22/SCL: J3.3, J10.a31 (SCL)
/A23/SDA: J3.4, J10.a32 (SDA)
/CLK_CPU: J10.b16 (CLK), U5.13 (B5)
/D0: J10.b7 (CD0), U3.18 (B0)
/D1: J10.b8 (CD1), U3.17 (B1)
/D2: J10.b9 (CD2), U3.16 (B2)
/D3: J10.b10 (CD3), U3.15 (B3)
/D4: J10.b11 (CD4), U3.14 (B4)
/D5: J10.b12 (CD5), U3.13 (B5)
/D6: J10.b13 (CD6), U3.12 (B6)
/D7: J10.b14 (CD7), U3.11 (B7)
/FPU_CLK: J9.2, J9.4, J9.6, J9.8, U12.23 (CLK)
/I2C_SCL: J2.4, J3.1, J4.11, R9.2, U8.3 (SCL), U10.6 (SCL)
/I2C_SDA: J2.1, J3.2, J4.12, R8.2, U8.2 (SDA), U10.5 (SDA)
/PIO_PA0: J2.2, U6.15 (PA0)
/PIO_PA1: J2.5, U6.14 (PA1)
/PIO_PB0: J4.3, R4.2
/PIO_PB1: J4.5, R5.2
/PIO_PB2: J4.7, R6.2
/PIO_PB3: J4.9, R7.2
/PIO_PB4: J4.10, R10.2
/PIO_PB5: J4.8, R13.2
/PIO_PB6: J4.6, R12.2
/PIO_PB7: J4.4, R11.2
/SPK_DRV: R3.1, U6.12 (PA3)
/~#IOREQ: U1.2 (P0), U1.4 (P1), U1.6 (P2), U1.8 (P3), U2.1 (I1/CLK), U5.5 (A3), U6.36 (~IORQ)
/~#M1: U5.8 (A6), U6.37 (~M1)
/~#RD: U2.2 (I2), U5.2 (A0), U6.35 (~RD), U8.16 (~RD), U9.8 (~RD), U12.20 (~RD)
/~#RESET: U5.9 (A7), U9.4 (~RESET), U11.1 (~MR), U12.22 (RESET)
/~#WR: U2.3 (I3), U5.3 (A1), U9.10 (~WR), U12.19 (~WR)
/~CS_FPU: U2.15 (IO5), U12.18 (~CS)
/~CS_IIC: U2.17 (I03), U8.17 (~CS)
/~CS_PIO: U2.16 (IO4), U6.4 (~CE)
/~CS_PS2: U2.18 (IO2), U9.6 (~INT)
/~IIC_WR: U2.14 (IO6), U8.18 (~WR)
/~INT0: J8.1, J10.b4 (~INT0), R14.1, U6.10 (PA4)
/~INT1: J8.3, J10.b5 (~INT1), R15.1, U6.9 (PA5)
/~INT2: J8.5, J10.b6 (~INT2), R16.1, U6.8 (PA6)
/~INT3: J8.7, J10.a6 (~INT3), R17.1, U6.7 (PA7)
/~INT_IIC: J2.3, R2.2, U8.5 (~INT)
/~INT_KB: R1.2, U6.13 (PA2), U7.10, U7.12
/~INT: J10.b17 (~INT), U6.23 (~INT)
/~IOREQ: J10.b25 (~IOREQ), U5.15 (B3)
/~M1: J10.b19 (~M1), U5.12 (B6)
/~RD: J10.b22 (~RD), U5.18 (B0)
/~RESET: J10.b15 (~RESET), U5.11 (B7)
/~RST_IIC: J2.6, U8.19 (~RST)
/~WAIT: J7.1 (A), J10.b20 (~WAIT)
/~WR: J10.b23 (~WR), U5.17 (B1)
BUSDIR: U2.12 (IO8), U3.1 (A->B)
GND: BT1.neg, C1.2, C2.2, C3.2, C4.2, C5.2, C6.2, C7.2, C8.2, C9.2, C10.2, C11.2, C12.2, C13.2, C14.2, C15.2, C16.2, D1.2 (A), D2.2 (A), D3.2 (A), D4.2 (A), D5.2 (A), D6.2 (A), D7.2 (A), D8.2 (A), J4.1, J4.13, J4.14, J5.3, J5.G, J6.3, J6.G, J10.G (CHASSIS), J10.a1 (GND), J10.a2 (GND), J10.a3 (GND), J10.a4 (GND), J10.b32 (GND), Q1.3 (E), RN1.1 (common), U1.1 (G), U1.10 (GND), U2.10 (GND), U3.10 (GND), U3.19 (CE), U4.1 (A->B), U4.10 (GND), U4.19 (CE), U5.1 (A->B), U5.10 (GND), U5.14 (B4), U5.16 (B2), U5.19 (CE), U6.11 (GND), U7.7 (GND), U8.10 (VSS), U9.2 (X1), U9.7 (EA), U9.20 (GND), U10.4 (GND), U11.3 (D0), U11.4 (D1), U11.5 (D2), U11.6 (D3), U11.8 (GND), U11.10 (CET), U12.1 (GND)
KBCI: C4.1, J6.5, U7.8, U9.1 (T0)
KBCO: U7.9, U9.37 (P2.6)
KBDI: C3.1, J6.1, U7.6, U9.27 (P1.0)
KBDO: U7.5, U9.38 (P2.7)
MSCI: C2.1, J5.5, U7.2, U9.39 (T1)
MSCO: U7.1, U9.24 (P2.3)
MSDI: C1.1, J5.1, U7.4, U9.28 (P1.1)
MSDO: U7.3, U9.23 (P2.2)
unnamed: D1.1 (K), R4.1, U6.27 (PB0)
unnamed: D2.1 (K), R5.1, U6.28 (PB1)
unnamed: D3.1 (K), R6.1, U6.29 (PB2)
unnamed: D4.1 (K), R7.1, U6.30 (PB3)
unnamed: D5.1 (K), R11.1, U6.34 (PB7)
unnamed: D6.1 (K), R12.1, U6.33 (PB6)
unnamed: D7.1 (K), R13.1, U6.32 (PB5)
unnamed: D8.1 (K), R10.1, U6.31 (PB4)
unnamed: J1.4, RN1.5 (R4), U1.12 (R4)
unnamed: J1.6, RN1.4 (R3), U1.14 (R5)
unnamed: J1.8, RN1.3 (R2), U1.16 (R6)
unnamed: J1.10, RN1.2 (R1), U1.18 (R7)
unnamed: J7.2 (B), U12.17 (~PAUSE)
unnamed: J8.2, J8.4, J8.6, J8.8, R19.2, U12.24 (~END)
unnamed: J9.1, U11.14 (Q0)
unnamed: J9.3, U11.13 (Q1)
unnamed: J9.5, U11.12 (Q2)
unnamed: J9.7, U11.11 (Q3)
unnamed: J10.b26 (IEI), U6.24 (IEI)
unnamed: J10.b27 (IEO), U6.22 (IEO)
unnamed: Q1.2 (B), R3.2
unnamed: LS1.2, Q1.1 (C)
unnamed: RN1.6 (R5), U1.9 (R3)
unnamed: RN1.7 (R6), U1.7 (R2)
unnamed: RN1.8 (R7), U1.5 (R1)
unnamed: RN1.9 (R8), U1.3 (R0)
unnamed: U1.19 (P=R), U2.8 (I8)
unnamed: U7.11, U9.35 (P2.4)
unnamed: U7.13, U9.36 (P2.5)
unnamed: BT1.pos, U10.3 (VBAT)
unnamed: U10.1 (X1), Y1.2
unnamed: U10.2 (X2), Y1.1
unnamed: R18.2, U12.3 (~EACK)
unnamed: R20.2, U12.4 (~SVACK)

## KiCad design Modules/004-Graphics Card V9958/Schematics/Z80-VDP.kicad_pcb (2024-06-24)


Board: 4 copper layers, 160.0 x 100.3 mm, 78 parts (0 on the bottom side), 127 nets.

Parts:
C1: 470uF; CP_Radial_D8.0mm_P3.50mm
C2, C3, C4, C7, C8, C9, C10, C11, C12, C15, C16, C22, C23, C25, C26, C27, C28, C29, C30, C31, C32, C33: 100nF; C_Rect_L7.0mm_W2.0mm_P5.00mm
C5, C6: 22pF; C_Rect_L7.0mm_W2.0mm_P5.00mm
C13, C14: 47uF; CP_Radial_D6.3mm_P2.50mm
C17, C18, C19, C20, C21, C24: 220uF; CP_Radial_D6.3mm_P2.50mm
C34: 2200uF; CP_Axial_L20.0mm_D13.0mm_P26.00mm_Horizontal
FB1, FB2: FerriteBead; R_Axial_DIN0414_L11.9mm_D4.5mm_P15.24mm_Horizontal
J1: Conn_02x04_Odd_Even; PinHeader_2x04_P2.54mm_Vertical
J2: Conn_02x05_Counter_Clockwise; PinHeader_2x06_P2.54mm_Vertical
J3: Z8C_Card; Z8C Card
J4: S-VIDEO Out; MINIDIN4_SVIDEO
J6: Composite Out; RCA_Reichelt
J7: RGBOut_Red; RCA_Reichelt
J8: RGBOut_Green; RCA_Reichelt
J9: RGBOut_Blue; RCA_Reichelt
JP1: Conn_02x06_Odd_Even; PinHeader_2x06_P2.54mm_Vertical
JP2, JP3: JUMPER; PinHeader_1x02_P2.54mm_Vertical
R1, R2, R3: 470R; R_Axial_DIN0204_L3.6mm_D1.6mm_P7.62mm_Horizontal
R4, R5: 2k2; R_Axial_DIN0204_L3.6mm_D1.6mm_P7.62mm_Horizontal
R6, R7, R8, R11, R12: 75; R_Axial_DIN0204_L3.6mm_D1.6mm_P7.62mm_Horizontal
R9: 43; R_Axial_DIN0204_L3.6mm_D1.6mm_P7.62mm_Horizontal
R10: 2k61; R_Axial_DIN0204_L3.6mm_D1.6mm_P7.62mm_Horizontal
R13: 240; R_Axial_DIN0204_L3.6mm_D1.6mm_P7.62mm_Horizontal
RN1: R_Network08; R_Array_SIP9
U1: L7805; TO-220-3_Horizontal_TabDown
U2: 74LS688; DIP-20_W7.62mm_LongPads
U3, U4, U5: 74HC245; DIP-20_W7.62mm_LongPads
U6: 74HC125; DIP-14_W7.62mm_Socket
U7: 74HC02; DIP-14_W7.62mm_Socket
U8: V9958; SDIP64
U9, U10, U12, U13, U14, U15: 41464; DIP-18_W7.62mm_Socket
U11: CXA2075M; SOIC-24W_7.5x15.4mm_P1.27mm
X1: ACO-xxxMHz; Oscillator_DIP-14
Y1: 21.477MHz; Crystal_HC50_Vertical

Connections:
+5V: C3.1, C4.1, C15.1, C16.1, C22.1, C23.1, C25.1, C26.1, C27.1, C28.1, C29.1, C30.1, C31.1, C32.1, C33.1, J3.b1 (+5V), J3.b2 (+5V), J3.b3 (+5V), JP1.1, JP1.3, JP1.5, JP1.7, JP1.9, JP1.11, JP3.1, U2.20 (VCC), U3.20 (VCC), U4.20 (VCC), U5.20 (VCC), U6.14 (VCC), U7.14 (VCC), U8.4 (VRESET), U8.27 (/HRESET), U8.58 (VCC), U9.9 (VCC), U10.9 (VCC), U12.9 (VCC), U13.9 (VCC), U14.9 (VCC), U15.9 (VCC)
+5VA: C2.1, C7.1, C11.1, C12.1, C13.2, C14.2, C34.1, FB2.2, J2.11, JP3.2, R10.2, U8.21 (VCC/DAC), U11.12 (VCC1), U11.19 (VCC2), X1.14 (Vcc)
+12V: J3.b28 (+12V), U1.1 (IN)
/#A0: U4.2 (A0), U8.29 (MODE0)
/#A1: U4.3 (A1), U8.28 (MODE1)
/#A2: U2.6 (P2), U4.4 (A2)
/#A3: U2.8 (P3), U4.5 (A3)
/#A4: U2.11 (P4), U4.6 (A4)
/#A5: U2.13 (P5), U4.7 (A5)
/#A6: U2.15 (P6), U4.8 (A6)
/#A7: U2.17 (P7), U4.9 (A7)
/#D0: U3.2 (A0), U8.40 (D0)
/#D1: U3.3 (A1), U8.39 (D1)
/#D2: U3.4 (A2), U8.38 (D2)
/#D3: U3.5 (A3), U8.37 (D3)
/#D4: U3.6 (A4), U8.36 (D4)
/#D5: U3.7 (A5), U8.35 (D5)
/#D6: U3.8 (A6), U8.34 (D6)
/#D7: U3.9 (A7), U8.32 (D7)
/A0: J3.a7 (CA0), U4.18 (B0)
/A1: J3.a8 (CA1), U4.17 (B1)
/A2: J3.a9 (CA2), U4.16 (B2)
/A3: J3.a10 (CA3), U4.15 (B3)
/A4: J3.a11 (CA4), U4.14 (B4)
/A5: J3.a12 (CA5), U4.13 (B5)
/A6: J3.a13 (CA6), U4.12 (B6)
/A7: J3.a14 (CA7), U4.11 (B7)
/AD0: U8.49 (AD0), U9.14 (A0), U10.14 (A0), U12.14 (A0), U13.14 (A0), U14.14 (A0), U15.14 (A0)
/AD1: U8.50 (AD1), U9.13 (A1), U10.13 (A1), U12.13 (A1), U13.13 (A1), U14.13 (A1), U15.13 (A1)
/AD2: U8.51 (AD2), U9.12 (A2), U10.12 (A2), U12.12 (A2), U13.12 (A2), U14.12 (A2), U15.12 (A2)
/AD3: U8.52 (AD3), U9.11 (A3), U10.11 (A3), U12.11 (A3), U13.11 (A3), U14.11 (A3), U15.11 (A3)
/AD4: U8.53 (AD4), U9.8 (A4), U10.8 (A4), U12.8 (A4), U13.8 (A4), U14.8 (A4), U15.8 (A4)
/AD5: U8.54 (AD5), U9.7 (A5), U10.7 (A5), U12.7 (A5), U13.7 (A5), U14.7 (A5), U15.7 (A5)
/AD6: U8.55 (AD6), U9.6 (A6), U10.6 (A6), U12.6 (A6), U13.6 (A6), U14.6 (A6), U15.6 (A6)
/AD7: U8.56 (AD7), U9.10 (A7), U10.10 (A7), U12.10 (A7), U13.10 (A7), U14.10 (A7), U15.10 (A7)
/CLK_CPU: J3.b16 (CLK), U5.16 (B2)
/CSYNC: J2.7, U8.6 (CSYNC)
/D0: J3.b7 (CD0), U3.18 (B0)
/D1: J3.b8 (CD1), U3.17 (B1)
/D2: J3.b9 (CD2), U3.16 (B2)
/D3: J3.b10 (CD3), U3.15 (B3)
/D4: J3.b11 (CD4), U3.14 (B4)
/D5: J3.b12 (CD5), U3.13 (B5)
/D6: J3.b13 (CD6), U3.12 (B6)
/D7: J3.b14 (CD7), U3.11 (B7)
/HSYNC: J2.9, U8.5 (HSYNC)
/RD0: U8.41 (RD0), U9.2 (D0), U12.2 (D0), U14.2 (D0)
/RD1: U8.42 (RD1), U9.3 (D1), U12.3 (D1), U14.3 (D1)
/RD2: U8.43 (RD2), U9.15 (D2), U12.15 (D2), U14.15 (D2)
/RD3: U8.44 (RD3), U9.17 (D3), U12.17 (D3), U14.17 (D3)
/RD4: U8.45 (RD4), U10.2 (D0), U13.2 (D0), U15.2 (D0)
/RD5: U8.46 (RD5), U10.3 (D1), U13.3 (D1), U15.3 (D1)
/RD6: U8.47 (RD6), U10.15 (D2), U13.15 (D2), U15.15 (D2)
/RD7: U8.48 (RD7), U10.17 (D3), U13.17 (D3), U15.17 (D3)
/RGB_B: J2.1, U8.24 (B)
/RGB_G: J2.5, U8.22 (G)
/RGB_R: J2.3, U8.23 (R)
/R/W: U8.57 (R/W), U9.4 (~W), U10.4 (~W), U12.4 (~W), U13.4 (~W), U14.4 (~W), U15.4 (~W)
/VO_BLUE: C21.2, J9.1 (In)
/VO_COM: C24.2, J6.1 (In)
/VO_GREEN: C20.2, J8.1 (In)
/VO_RED: C18.2, J7.1 (In)
//CAS0: U8.61 (/CAS0), U9.5 (~RAS), U10.5 (~RAS)
//CAS1: U8.60 (/CAS1), U12.5 (~RAS), U13.5 (~RAS)
//CASX: U8.59 (/CAS_X), U14.5 (~RAS), U15.5 (~RAS)
//RAS: U8.62 (/RAS), U9.16 (~CAS), U10.16 (~CAS), U12.16 (~CAS), U13.16 (~CAS), U14.16 (~CAS), U15.16 (~CAS)
/~#IOREQ: U2.2 (P0), U2.4 (P1), U5.5 (A3)
/~#RD: U5.2 (A0), U7.9
/~#RESET: U5.9 (A7), U8.9 (/RESET)
/~#WAIT: U6.1, U8.26 (/WAIT)
/~#WR: U5.3 (A1), U7.3
/~INT0: J1.1, J3.b4 (~INT0)
/~INT1: J1.3, J3.b5 (~INT1)
/~INT2: J1.5, J3.b6 (~INT2)
/~INT3: J1.7, J3.a6 (~INT3)
/~IOREQ: J3.b25 (~IOREQ), U5.15 (B3)
/~IRQ_OUT: J1.2, J1.4, J1.6, J1.8, U8.25 (/INT)
/~M1: J3.b19 (~M1), U5.12 (B6)
/~RD: J3.b22 (~RD), U5.18 (B0)
/~RESET: J3.b15 (~RESET), U5.11 (B7)
/~VDP_RD: U7.13, U8.31 (/CSR)
/~VDP_WR: U7.4, U8.30 (/CSW)
/~WAIT: J3.b20 (~WAIT), JP2.2
/~WR: J3.b23 (~WR), U5.17 (B1)
BUSDIR: U3.1 (A->B), U7.10, U7.11, U7.12
GND: C1.2, C3.2, C4.2, C5.2, C6.1, C15.2, C16.2, C22.2, C23.2, C25.2, C26.2, C27.2, C28.2, C29.2, C30.2, C31.2, C32.2, C33.2, FB1.1, J3.G (CHASSIS), J3.a1 (GND), J3.a2 (GND), J3.a3 (GND), J3.a4 (GND), J3.b32 (GND), RN1.1 (common), U1.2 (GND), U2.1 (G), U2.10 (GND), U3.10 (GND), U3.19 (CE), U4.1 (A->B), U4.10 (GND), U4.19 (CE), U5.1 (A->B), U5.10 (GND), U5.13 (B5), U5.14 (B4), U5.19 (CE), U6.2, U6.4, U6.5, U6.7 (GND), U6.9, U6.10, U6.12, U6.13, U7.7 (GND), U8.1 (GND), U9.1 (~OE), U9.18 (GND), U10.1 (~OE), U10.18 (GND), U12.1 (~OE), U12.18 (GND), U13.1 (~OE), U13.18 (GND), U14.1 (~OE), U14.18 (GND), U15.1 (~OE), U15.18 (GND)
GNDA: C2.2, C7.2, C11.2, C12.2, C13.1, C14.1, C34.2, FB1.2, J2.12, J4.1, J4.2, J4.G, J6.2 (Ext), J7.2 (Ext), J8.2 (Ext), J9.2 (Ext), R1.1, R2.1, R3.1, R13.1, U8.20 (GND/DAC), U11.1 (GND1), U11.7 (NPIN), U11.24 (GND2), X1.7 (GND)
unnamed: C17.1, R12.2
unnamed: C17.2, J4.4
unnamed: C18.1, R6.2
unnamed: C19.1, R11.2
unnamed: C19.2, J4.3
unnamed: C20.1, R7.2
unnamed: C21.1, R8.2
unnamed: C24.1, R9.2, R13.2
unnamed: C8.1, J2.2, R3.2
unnamed: C10.1, J2.4, R2.2
unnamed: C9.1, J2.6, R1.2
unnamed: J2.8, R5.1
unnamed: J3.b26 (IEI), J3.b27 (IEO)
unnamed: JP1.2, RN1.7 (R6), U2.7 (R2)
unnamed: JP1.4, RN1.6 (R5), U2.9 (R3)
unnamed: JP1.6, RN1.5 (R4), U2.12 (R4)
unnamed: JP1.8, RN1.4 (R3), U2.14 (R5)
unnamed: JP1.10, RN1.3 (R2), U2.16 (R6)
unnamed: JP1.12, RN1.2 (R1), U2.18 (R7)
unnamed: JP2.1, U6.3
unnamed: RN1.8 (R7), U2.5 (R1)
unnamed: RN1.9 (R8), U2.3 (R0)
unnamed: C1.1, FB2.1, U1.3 (OUT)
unnamed: U2.19 (P=R), U7.2, U7.8
unnamed: U7.1, U7.5, U7.6
unnamed: C5.1, U8.63 (XTAL1), Y1.1
unnamed: C6.2, U8.64 (XTAL2), Y1.2
unnamed: C8.2, U11.4 (BIN)
unnamed: R8.1, U11.21 (BOUT)
unnamed: R12.1, U11.15 (COUT)
unnamed: R9.1, U11.20 (CVOUT)
unnamed: C9.2, U11.3 (GIN)
unnamed: R7.1, U11.22 (GOUT)
unnamed: C10.2, U11.2 (RIN)
unnamed: R6.1, U11.23 (ROUT)
unnamed: R4.2, U11.6 (SCIN)
unnamed: R5.2, U11.10 (SYNCIN)
unnamed: R11.1, U11.16 (YOUT)
unnamed: R10.1, U11.17 (YTRAP)
unnamed: R4.1, X1.8 (OUT)

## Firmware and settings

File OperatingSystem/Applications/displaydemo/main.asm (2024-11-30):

    IDE_CMD_WRITESEC .EQU 0x30


.include "extern_symbols.s" ;include monitor symbols.
    START_ADDR   .EQU 0x8000
    
    org START_ADDR  
com_header:
    jp com_prg
    db 0x00
    dw 0x00, 0x00, 0x00   ;always 0
    dw [START_ADDR]     ;start addr
    dw [_eof]           ;end of file
    dw [_eof - START_ADDR]  ;length
    dc 48,0x00
    
com_prg:
; Program starts here

    call TermInit
	ret
;-------------------------------------------------
; Z8C/MEGA80 VDP Console IO Functions
; by Dennis Gunia 2022/02
; Version 0.1
;
; For Z8C Monitor
;-------------------------------------------------

; Constant Values
TermVarMemoryLocation        equ 0x7000


; Dynamic VARs
TermVarTemplate:
    phase TermVarMemoryLocation  ;Change pointers to this template to the specified location
TermCurrentX:   ; Start sector
    defb 0x01
TermCurrentY:   ; Start sector
    defb 0x04
TermCursorState:
    defb 0x00
TermCursorEnabled:
    defb 0x00
TermVarTemplateEnd:
    dephase



TermInit:
    ; Copy TermVarTemplate to memory
    LD HL, TermVarMemoryLocation     ;Load destination into HL
    LD BC, [TermVarTemplate]         ;Load source into BC
    LD DE, [TermVarTemplateEnd]      ;Load end into DE
TermInit_copy_loop:
    LD A,(BC)       ;Copy value
    LD (HL),A       
    INC BC          ;Increment pointers
    INC HL
    PUSH HL         ;Backup HL
    SBC HL,DE       ;Check if next pointer matches end
    POP HL          ;Restore HL
    JP NZ, TermInit_copy_loop    ;Loop if pointer != end
    ; template copy done


    ; install font
    call    setup_vars
    ld      hl, TmsFont
    call    TmsTextMode                     ; initialize text mode

    ld      a, TmsDarkRed                  ; set colors
    call    TmsBackground
    ld      a, TmsWhite
    call    TmsTextColor

    ld      a, 0                           ; put title at 11, 1
    ld      e, 0
    call    TmsTextPos
    ld      hl, TitleMessage                ; output title
    call    TmsStrOut

    ld      a, 0                           ; put title at 11, 1
    ld      e, 4
    call    TmsTextPos


    ret

TermSetCursor:
    ld      a, (TermCurrentY)
    ld      e, a
    ld      a, (TermCurrentX)                           
    
    call    TmsTextPos
    ret

TermPrintStr:
    ; BC contains String offset
    ; Prints null terminated string
    PUSH AF
    PUSH BC
TermPrintStr_LOOP:
    LD A,(BC)

    ; Return if nullbyte
    OR 0
    JR Z, TermPrintStr_EXIT
    ; Print Char
    CALL TermPrintChar

    ; INC BC and JP start of loop
    INC BC
    jp TermPrintStr_LOOP
TermPrintStr_EXIT:
    POP BC
    POP AF
    RET

TermPrintChar:
    push AF
    push BC
    push DE
    push HL
    ; check if special char
    cp 0x7F ; Backspace
    jp z, TermPrintCharSPDelete
    cp 13
    jp z, TermPrintCharSPCR
    cp 10
    jp z, TermPrintCharSPLF
    ; a has char
    call TmsChrOut
    ld a,(TermCurrentX)
    inc a
    cp 39
    jp z,TermPrintCharWrap; if line end
    jp nc,TermPrintCharWrap; if line end
    ld (TermCurrentX), a
    call TermSetCursor
    jp TermPrintCharDone
TermPrintCharWrap:
    xor a
    ld (TermCurrentX), a
    ld a,(TermCurrentY)
    cp 23   ; if already last line
    jp z, TermPrintCharSPLFScroll
    inc a
    ld (TermCurrentY),a
    call TermSetCursor
    jp TermPrintCharDone
TermPrintCharSPDelete:
    ld a,(TermCurrentX)
    and a
    jp z, TermPrintCharSPDeleteWrap ; if at pos X 0 then go previous line
    dec a   ; else decrement X
    ld (TermCurrentX), a
    call TermSetCursor
    ld      a, " "     
    call    TmsChrOut
    call TermSetCursor
    jp TermPrintCharDone
TermPrintCharSPDeleteWrap:
    ld a,39
    ld (TermCurrentX), a
    ld a,(TermCurrentY)
    dec a
    ld (TermCurrentY),a
    call TermSetCursor
    ld      a, " "     
    call    TmsChrOut
    call TermSetCursor
    jp TermPrintCharDone

TermPrintCharSPLF:  ; linefeed
    ld a,(TermCurrentY)
    cp 23   ; if already last line
    jp z, TermPrintCharSPLFScroll
    inc a
    ld (TermCurrentY),a
    call TermSetCursor
    jp TermPrintCharDone
TermPrintCharSPLFScroll:
    call TermScroll
    ld a,23
    ld (TermCurrentY),a
    call TermSetCursor
    jp TermPrintCharDone
TermPrintCharSPCR:  ; linefeed
    xor a
    ld (TermCurrentX),a
    call TermSetCursor
    jp TermPrintCharDone

TermPrintCharDone:
    pop HL
    pop DE
    pop BC
    pop AF
    ret

TermScroll:
    ld bc, 0x3800    ; load start of text-buffer into pointer

TermScrollLine:
    ld h,b
    ld l,c

    ld de, 40   ; line width
    add hl, de

    ld a,l          ; setup VDP address
    out (0x81),a
    ld a,h
    and 3fh
    out (0x81),a
    call VDPWait
    in a, (0x80)    ; read byte
    push af

    ld a,c          ; setup VDP address
    out (0x81),a
    ld a,b
    and 3fh         
    or 40h          ; write bit
    out (0x81),a
    pop af
    call VDPWait
    out (0x80),a

    inc bc

    ld h,b
    ld l,c
    ld de, VDPTextBufferEnd   ; buffer end
    sbc hl, de

    jp nz, TermScrollLine

    ; clear last line
    ld bc,920
    ld a,c          ; setup VDP address
    out (0x81),a
    ld a,b
    and 3fh         
    or 40h          ; write bit
    out (0x81),a
    ld c,40
TermScrollClearLine:
    ld bc, 0x3800 + 920
TermScrollClearLineLoop:

    ld a,c          ; setup VDP addressh
    out (0x81),a
    ld a,b
    and 3fh         
    or 40h          ; write bit
    out (0x81),a
    ld a, ' '
    out (0x80),a
    call VDPWait

    inc bc
    ld h,b
    ld l,c
    ld de, 0x3800 + 960   ; buffer end
    sbc hl, de

    jp nz, TermScrollClearLineLoop
    ret

VDPWait:
    nop
    nop
    nop
    nop
    ret

VDPTextBufferStart  equ 0
VDPTextBufferEnd    equ 0x3800 + 920

TitleMessage:    
    db '  Z8C Mk IV - A Z80 Homebrew Computer   '
    db '  ROM Ver. 1.0 by Dennis Gunia (2024)   '
    db '        64k RAM - 10MHz Z80 CPU         ',0

TmsSubs:
    .include "tms.s"                       ; TMS graphics routines
;        .include "utility.s"                   ; BDOS utility routines
    .include "font1.s"
    

TermClear:
    ld bc, 0x3800
TermClearLoop:
    ld a,c          ; setup VDP addressh
    out (0x81),a
    ld a,b
    and 3fh         
    or 40h          ; write bit
    out (0x81),a
    ld a, ' '
    out (0x80),a
    call VDPWait
    inc bc

    ld h,b
    ld l,c
    ld de, 0x3800 + 960   ; buffer end
    sbc hl, de
    jp nz, TermClearLoop

    xor a
    ld (TermCurrentX), a
    ld (TermCurrentY), a

    call TermSetCursor

    ret


; Program ends here
_eof:

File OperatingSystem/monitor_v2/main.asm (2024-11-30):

;----------------------------------------------------------------
;Z8C Homebrew Computer Monitor 
;by Dennis Gunia (01/2023)
;----------------------------------------------------------------

;================================================================
; Memory areas
;================================================================
SYS_RAM_START   equ 0x4000
SYS_BUF_START   equ 0x4010
PRG_RAM_START   equ 0x4110
PRG_RAM_TOP     equ 0xFF00
STACK_RAM_TOP   equ 0xFFFF

;================================================================
; Terminal configuration
;================================================================
VAR_CONSOLE_CONF    equ 0x0F  ;CPU/16  Clock @ 230402.5625/s
VAR_CONSOLE_BAUD    equ 24  ;BAUD timer constant
                            ;CLK/TRG Clock @ 1843220.5/s
                            ; -> 0x16 : 14400
                            ;CPU/16  Clock @ 230402.5625/s
                            ; -> 12 : 19200
                            ; -> 24 : 9600

;================================================================
; Includes (1/2)
;================================================================
; include IO device addresses
.include "addresses.s"

;================================================================
; RST Vectors for BASIC
;================================================================
    org 0x0000
RST_00: ;Hardware Restart
    jp BOOT_PHASE0    

    org 0x0008
RST_08  ;Print Char
    jp EXEC_RST_08

    org 0x0010
RST_10  ;receive char
    jp EXEC_RST_10

    org 0x0018
RST_18  ;Buffer length
    jp EXEC_RST_18

;================================================================
; Default interrupt vectors
;================================================================
INT_VEC:    
    org 0x0044
    ;DEFW EXEC_INT_VDP

;================================================================
; Memory layout
;================================================================

mon_var_template_sof .EQU mon_var_template + 1024

mon_var_template:
    phase SYS_RAM_START
interrupt_vectors:
    defs 256
var_buffer_conin_data:  ;contains console input
    defs 256
var_buffer_conin_in:    ;pointer to write position of buffer
    defb 0
var_buffer_conin_out:   ;pointer to read position of buffer
    defb 0
var_buffer_conin_sts:   
    defb 0
var_buffer_conout:
    defb 0
var_buffer_len:
    defb 0
var_last_char:
    defb 0
var_curserx:
    defb 0
var_cursery:
    defb 0
var_curserstate:
    defb 0
var_curseron:
    defb 0
var_curserchar:
    defb 0
var_curserlastaddr:
    defw 0
var_pio_present:
    defb 0
var_apu_present:
    defb 0
var_scratch:
    defs 16 ;16 bytes space for scratch vars
var_ps2mem:
    defs 16 ;16 bytes space for scratch vars
var_dir:
    defs 80 
var_input:
    defs 80 
var_idebuffer:
    defs 768

    dephase
mon_var_template_end:
    nop

;================================================================
; Start of monitor
;================================================================
.include "ref.s"    ;static bios calls for programs
    
BOOT_PHASE0:     ;Setup Hardware
    ;Setup Stack-Pointer
    ld sp, STACK_RAM_TOP
    ;Disable Interrupts
    di
    ;Setup PIO on MIO Board
    LD A,0xCF
    OUT (CS_PIO_AC), A
    LD A,11110111b      ;All pins inputs except speaker
    OUT (CS_PIO_AC), A
    LD A,00000011B      ;Preset I2C pins to high
    OUT (CS_PIO_AC), A  

    ;Set variables    
    ld (var_curserstate),a
    ld (var_curseron),a
    ld a, " "
    ld (var_curserchar),a

    ;Enable interupts
    call intctrl_init
    ;Initialize Console (Serial-Port)
    call CONSOLE_INIT   
    

    ;clear memory area
    ld hl, [mon_var_template_sof]
    ld bc, [mon_var_template_end-mon_var_template_sof]
    ld de, [mon_var_template_sof+1]
    xor a
    ld (hl),a
    ldir

    jp BOOT_PHASE2  ;skip rest of table init
BOOT_PHASE1:    ;Copy default values to RAM
    ld hl,mon_var_template + 1024
    ld de,mon_var_template_end
    ld bc,SYS_RAM_START
BOOT_PHASE1_LOOP:
    ld a,(hl)  ;copy values
    ld (bc),a
    inc hl      
    inc bc
    push hl    ;check if end is reached
    sbc hl,de
    pop hl
    jp nz, BOOT_PHASE1_LOOP
    ;template copy done

    
BOOT_PHASE2:    ;Hardware initialized.
    ; Print banner
    call print_clear
    ld hl, [STR_Banner_Start]
    call print_str

    ; Power-On Self Tests
    call POST_START

    ; Detect IDE drives
    call ideif_init_all

    ; Beep after start
    LD DE,0x40
    LD BC,0x48
    CALL beep

    xor a   ;set dir to empty
    ld (var_dir),a
    ld (var_dir+1),a
    ;enable interrupts
    ei
    ; Start commandline
    jp COMMAND
    
    ; This instruction should never be reached
    halt
   
;================================================================
; Includes (2/2)
;================================================================
.include "console.s"
.include "conversions.s"
.include "disassembler.s"
.include "disassembler_table.s"
.include "rst.s"
.include "beep.s" 
.include "kdrv_ide8255.s" ;include ide interface driver.
.include "kdrv_ideif.s" ;include ide driver.
.include "kdrv_siic.s"
.include "kdrv_int.s"
.include "kdrv_sio.s"
.include "prettydump.s"
.include "command.s"
.include "cmd_mem.s"
.include "cmd_io.s"
.include "cmd_date.s"
.include "cmd_disk.s"
.include "post.s"
.include "fat16.s"
.include "fat16_cmd.s"

;================================================================
; Strings
;================================================================
STR_Banner_Start:
    db "Z8C Monitor V2.1 by Dennis Gunia (2022-2024)",0

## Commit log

2022-12-05 New features
    [Z80-GPU.kicad_sch, z80-MIDI.kicad_sch]
2022-12-20 added i2c controller tests
    [Z80-X86CPU.kicad_sch]
2023-01-16 added i2c controller functions, added IDE interface functions, fiexd IDE schematics
    [Z80-IDE.kicad_pcb]
2023-12-28 multiple updates
    [Z80-MIO.kicad_pcb, Z80-MIO.kicad_sch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]
2024-06-24 pushed updates
    [TRIGGER_PANEL.kicad_pcb, TRIGGER_PANEL.kicad_sch, Z80-MIO.kicad_pcb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]
2024-06-24 reorganize everything
    [007-MemoryExpansion.kicad_pcb, 007-MemoryExpansion.kicad_sch]
2024-11-30 several fixes
    [007-MemoryExpansion.kicad_pcb, 007-MemoryExpansion.kicad_sch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]
2024-12-22 fix Sound board rev1
    [z80-SOUND_rev1.kicad_sch]
2024-12-22 added updated schematics
2025-01-03 Added Backplane
    [Z80-Backplane-B_Cu.gbr, Z80-Backplane-B_Mask.gbr, Z80-Backplane-B_Paste.gbr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]
